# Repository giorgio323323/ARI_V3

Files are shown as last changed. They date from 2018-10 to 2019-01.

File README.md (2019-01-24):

il progetto si sposta in https://github.com/stuffcube/ARI_V3
questo repository va in abbandono.

la documentazione è in costruzione.
ogni folder sarà un repository e conterrà un proprio readme

la documentazione sarà in markdown language per poter essere editata e condivisa

# ARI_V3
versione 3 di Ari(anna)

ARI_V3 è un robot didattico.  
L'abbiamo fatto scrivendo il codice da zero per poter capire e poi speigare tutte le nozioni che servono a farlo funzionare.
Doveva poi poter essere usato senza il timore di romperlo. 
Avere un costo che permettesse a ognuno di averlo.
Doveva avere le possibilità di un robot "Grande", permettere di fare se cose che si fanno sui robot "seri".

Costando il materiale circa 100 € permette a ognuno di averlo per poterci lavorare.
Ha dei motori che gli permettono di muoversi. Sono dotati di encoder sulle ruote, ha quindi un algoritmo di odometria. L'odometria gli permette di sapere dove sta andando.
Ha un Lidar, un radar laser, montato su un servo che permette di ruotarlo. Questo permette di analizzare gli algoritmi di scansione in due dimensione.
Gli permette anche di viaggiare mantenendo la distanza da una parete laterale o di seguire una persona.
Ha una interfaccia WiFi, tramite questa si collega a un pc da dove è possibile inviare comandi ed eseguire programmi che comandano e usano i dati ritornati da ARI.

monta un puntatore laser per indicare cose, ha un sensore IR per poter tornare a casa quando si perde.

Per ultimo ha una interfaccia per bussola magnetica e navigatore inerziale completo.

Ogni suo aspetto può essere studiato 
senza timore di rompere qualcosa.

istruzioni di installazione del SW nel folder:
ARI_V3\00_doc\00_installaECompila

a cura di https://stuffcube.wordpress.com/

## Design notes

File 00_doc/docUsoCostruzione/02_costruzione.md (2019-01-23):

| Tabella aggiornamenti |  |  |
| --- | --- | --- |
| data | autore | modifica |
| |  |  |
| |  |  |
| |  |  |

# Impostazioni e taratura

Una volta montata ARI V3 occorre configurarla per fargli conoscere come è il suo corpo. Le informazioni che servono sono:

La _Carreggiata o Baseline_: distanza tra le ruote in mm

Lo _Sviluppo della ruota_ in mm, la sua circonferenza che è pari a 3.14 volte il diametro.

I _ppr_ (Pulses Per Revolution) degli encoder. Il numero di tacche che ha il disco dell&#39;encoder.

Con questi numeri si ricavano i numeri del robot.

Baseline = Carreggiata

Giro Ruota = sviluppo ruota[mm]/(4\*ppr)

ED = 1

ED\_BASE  = 1

Calcolati questi numeri tramite la CLI

[^]: CLI, Command Line Interface. È la finestra con la quale inviamo I comandi digitandoli sulla tastiera.

 vi imposto su ARI V3. Scritto il comando lo si invia con _InviaCmd_.

_I comandi hanno la seguente forma:_

_il primo numero indica l&#39;azione. 3 significa scrittura, 1 lettura.
dal terzo carattere si indica quale azione fare, nell&#39;esempio sotto F1 significa scrivi ED\_BASE
i caratteri successivi contengono l&#39;argomento del comando, di norma il valore._

_Ad ogni comando inviato viene ritornata una risposta &quot;comprensibile&quot;.
es: invio &quot;3F11&quot; mi viene ritornato &quot;F1\_ED\_BASE: 1.000000&quot;_

Il comando è il seguente:

Fnxxx: imposta dei parametri del robot. &quot;n&quot; indica quale parametro, &quot;xxx&quot; è il valore.

    F0xx ED
    F1xx ED\_BASE
    F2xx BASELINE               mm
    F3xx GIRO\_RUOTA        mm = sviluppo ruota[mm]/(4\*ppr)
    
    N.B. questi valori vanno attivati con un 3E3

Esempio:

carreggiata 		= 220 mm
diametro ruota 	= 50 mm
ppr 				= 20

sviluppo ruota = 3.14\*50 = 157 mm

Giro Ruota = sviluppo ruota[mm]/(4\*ppr) = 157/(4\*20) =1.9625 mm

Comandi da inviare:

E2                carica i valori di default.
E3                attiva i valori
E0                salva i valori in E2prom

I valori di default sono quelli sotto riportati.

dovendo modificare i valori sotto sono riportati i singoli comandi.	

ED                 		= 1        		inviare           	**F01**. **N.B. 0 è &quot;zero&quot; non &quot;O&quot; maiuscolo**
ED\_BASE  		= 1        		inviare               **F11**
BASELINE		= 220      	inviare                **F2220**
GIRO\_RUOTA       	= 1.9625 	inviare                **F31.9625**

inviare E3 per attivare i valori. La risposta conterrà la lista dei parametri attiva. Questo parametro serve anche per mostrare i parametri in uso.

E0 per salvarli nella EEprom 

[^]:  EEprom oppure E2prom. Electrically Erasable Programmable Read-Only Memory. Una memoria dove i dati possono essere letti, scritti e conservati anche senza tensione, cioè a chip spento.

 di ARI V3. Cosi facendo verranno ricaricati ad ogni accensione.

# Verifica dei dati.

Per vedere se i numeri &quot;quadrano&quot; muoviamo ARI. Facciamogli fare un movimento e vediamo come va. Mi serve un metro per misurare lo spazio percorso.

## Verifica distanza

Accendo e spengo ARI.

**3D1000**         definisco un percorso di 1000 mm.
**3R1**                 la faccio muovere in linea retta. ARI dovrebbe partire e fermarsi dopo un metro circa.

Se la distanza percorsa non è corretta aggiusto GIRO\_RUOTA opportunamente.. formula

## Verifica centratura

È probabile che il percorso non sia rettilineo e tenda a curvare verso destra o sinistra. Il fenomeno è dovuto alle ruote che pur simili hanno differenze minime. Aggiustando il parametro ED si corregge questo comportamento, ED infatti modifica il diametro delle ruote sinistra e destra rendendoli diversi.
ED si modifica a piccoli passi, qualche percento alla volta, per esempio 1.01 oppure 0.99. Se lo si aumenta ARI va verso destra, diminuendolo ruota verso sinistra.

Per attivare il valore ED = 1.02 la sequenza è:

passo 1: impostazione parametro

**3F01.02**                 per impostare il nuovo valore 1.02
**3E3**                         per attivare i valori, la risposta

Passo 2:Test

**3D1000**         definisco un percorso di 1000 mm.
**3R1**                 la faccio muovere in linea retta.

Muove verso destra?         Diminuisco ED e torno al passo 1
Muove verso sinistra?         aumento ED e torno al passo 1

Muove diritta? Proseguo e salvare i dati

**3E0**                 salvo i dai in memoria EEprom.

Ex: EEprom.  Esegue operazioni su dei parametri di taratura. Vedi procedura DataEEprom.

    E0 SCRIVI i parametri in E2prom,
    E1 LEGGI i parametri in E2prom,
    E2 rispristina in valori di DEFAULT,
    E3 attiva e mostra i parametri CORRENTI,

# Tabelle di collegamento connettori

| **J\_ENC** | **filo** | **Jb**asetta End Stop | |
| --- | --- | --- | --- |
| 1 | Nero | Emitter-Katode | Dx |
| 2 | Bianco | Collector | Dx |
| 3 | Grigio | Anode | Dx |
| 4 | Viola | Emitter-Katode | Sx |
| 5 | Blu | Collector | Sx |
| 6 | verde | Anode | Sx |

| CN_FRONT_HEAD | | |
| --- | --- | --- |
| 1 | Marrone | Rosso 5V |
| 3 | Rosso | Nero Gnd |
| 5 | Arancio | Bianco Rx1 (lidar tx) |
| 7 | Giallo  | Verde Tx1 (lidar rx)  |
| 2 | Viola | IR rx pin |
| 4 | Grigio  | Nc |
| 6 | Bianco  | Led pointer |
| 8 | Nero | 3V3 IR power supply |

# Collegamento motori

Per il significato di sotto e sopra e destro sinistro fare riferimento all'immagine di montaggio. 

**1) Notare il nottolino giallo rivolto verso l'interno**
**2) Dx e Sx sono riferiti al robot in posizione di lavoro con la punta in avanti. Nella foto c'è la vista da sotto e dx e sx sono quindi invertite.**

| MOTORS | | |
| --- | --- | --- |
| 1 | Marrone | Sotto sx |
| 2 | Rosso | Sopra sx |
| 3 | Arancio | Sopra dx |
| 4 | Giallo  | Sotto dx |

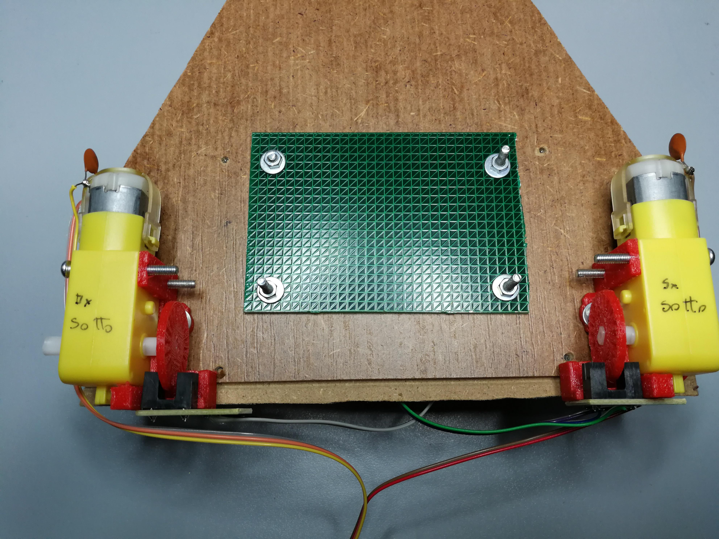
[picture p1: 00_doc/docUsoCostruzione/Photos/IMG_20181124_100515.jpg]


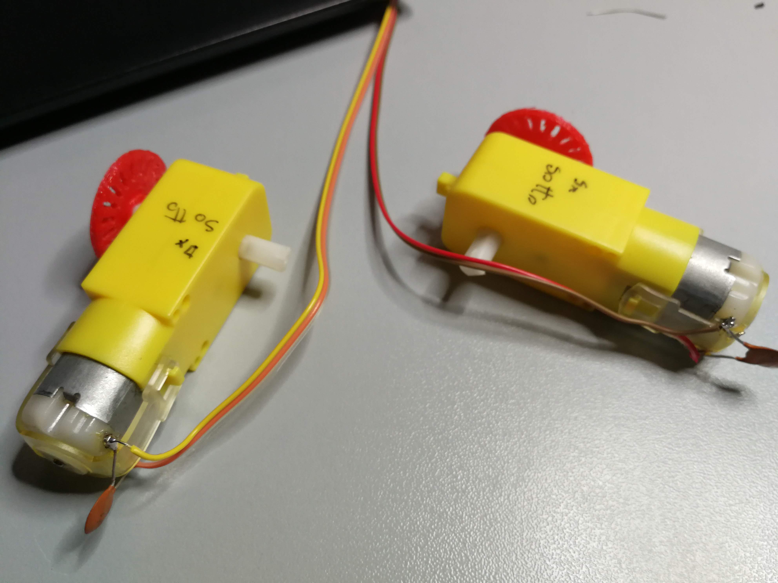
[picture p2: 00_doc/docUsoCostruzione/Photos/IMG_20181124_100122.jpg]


# Sequenza montaggio

Indicare il nottolino che deve stare all&#39;interno

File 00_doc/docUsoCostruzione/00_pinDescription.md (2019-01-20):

# Documentazione elettrica

| Tabella aggiornamenti | | |
| --- | --- | --- |
| data | autore  | modifica |
| 13gen19 | giorgio | portato documento in formato .md |
| | | |
| | | |
| | | |
| | | |
| | | |

##  

vengono descritti i pin dei vari componenti e come vengono usati.

## Wemos nomi pin

Per indirizzare i pin usare il nome della colonna GPIO. I nomi Wemos nella colonna di destra non tornano.

per verificare le corrispondenze ho scritto un codice che stampa i valori dei vari Dx, 

`Serial.println(D1);`

`...`

`Serial.println(D5);`

la colonna Valore print mostra il valore ritornato

| Print(Dx) | Valore print | GPIO | Nome wemos |
| --- | --- | ---- | --- |
| D1 | 01 | 01 | - |
| D2 | 16 | 16 | D0 |
| D3 | 05 | 05 | D1 |
| D4 | 04 | 04 | D2 |
| D5 | 14 | 14 | D5 |
| | | 15 | D8 |
| | | 13 | D7 |
| | | 12 | D6 |
| | | 02 | D4 |
| | | 00 | D3 |
| | | | |

# Dove sono usati i Wemos 

I Wemos sono usati sia sul robot che sulla base a terra. La base a terra è un radiofaro per permettere ad ARI di orientarsi.

La tabella riporta l'ssegnamento pin sui due Wemos

| **Pin number** | **Pin** **name** | **function** | **Ir Tx On ground** | **Ir Rx On robot** |
| --- | --- | --- | --- | --- |
| 1 | RST | Reset module | | |
| 2 | ADC | A/d conversion result. Input voltage range 0~1V, value range: 0~1024 | Fotocellula - in | |
| 3 | EN | Chip enable pin. Active high | | |
| 4 | GPIO16 | GPIO16; can be used to wake up the chipset from deep sleep mode | Stato barriera - D0 - out | |
| 5 | GPIO14 | GPIO14; HSPI_CLK | | |
| 6 | GPIO12 | GPIO12; HSPI_MISO | | |
| 7 | GPIO13 | GPIO13; HSPI_MOSI; UART0_CTS | | |
| 8 | VCC | 3.3V power supply (VDD) | | IR_chip pwr supply |
| 9 | GND | GND | | IR chip ground |
| 10 | GPIO15 | GPIO15; MTDO; HSPICS; UART0_RTS | | |
| **11** | **GPIO2** | **GPIO2; UART1_TXD** | **Seriale tx Debug – D4  - out** | **Seriale tx Debug – D4  - out** |
| 12 | GPIO0 | GPIO0 | Sx led sel  - D3  - out | |
| 13 | GPIO4 | GPIO4 | Ir tx - D2  -  out | Ir rx (D5) In |
| 14 | GPIO5 | GPIO5 | Dx led sel - D1 - out | |
| 15 | RXD0 | UART0_RXD; GPIO3 | | Rx |
| 16 | TXD0 | UART0_TXD; GPIO1 | | Tx |

# Wemos pin description

| **Interface** | **Pin Name** | **Description** |
| --- | --- | --- |
| HSPI | IO12(MISO), IO13(MOSI) IO14(CLK), IO15(CS) | SPI Flash , display screen, and MCU can be connected using HSPI interface |
| PWM | IO12(R), IO15(G), IO13(B) | Currently the PWM interface has four channels, but users can extend the channels according to their own needs. PWM interface can be used to control LED lights, buzzers, relays, electronic machines, and so on. |
| IR Remote Control | IO14(IR_T), IO5(IR_R) | The functionality of Infrared remote control interface can be implemented via software programming. NEC coding, modulation, and demodulation are used by this interface. The frequency of modulated carrier signal is 38KHz. |
| ADC | TOUT | ESP8266EX integrates a 10-bit analog ADC. It can be used to test the power supply voltage of VDD3P3 (Pin3 and Pin4) and the input power voltage of TOUT (Pin 6). However, these two functions cannot be used simultaneously. This interface is typically used in sensor |
| I2C | IO14(SCL), IO2(SDA) | I2C interface can be used to connect external sensor products and display screens, etc. |
| UART | UART0: TXD(U0TXD), RXD(U0RXD), IO15(RTS), IO13(CTS) UART1: IO2(TXD) | Devices with UART interfaces can be connected with the module. Downloading: U0TXD+U0RXD or GPIO2+U0RXD Communicating: UART0: U0TXD, U0RXD, MTDO (U0RTS), MTCK (U0CTS) Debugging: UART1_TXD (GPIO2) can be used to print debugging information. |
| By default, UART0 will output some printed information when the device is powered on and is booting up. If this issue exerts influence on some specific applications, users can exchange the inner pins of UART when initializing, that is to say, exchange U0TXD, U0RXD with U0RTS, U0CTS. | | |
| I2S | I2S Input： IO12 (I2SI_DATA) ; IO13 (I2SI_BCK ); IO14 (I2SI_WS); | I2S interface is mainly used for collecting, processing, and transmission of audio data. |
| I2S Output:： IO15 (I2SO_BCK ); IO3 (I2SO_DATA); IO2 (I2SO_WS ). | | |

## Arduino ATmega 2560 pin assignement table

| **Used for** | **Schematic Name** | **Pin Name** | **Mapped Pin Name** |
| --- | --- | --- | --- |
| | | | |
| | | | |
| | | PG5 ( OC0B ) | Digital pin 4 (PWM) |
| Lidar rx | PWMH.1 | PE0 ( RXD0/PCINT8 ) | Digital pin 0 (RX0) |
| - | | PE1 ( TXD0 ) | Digital pin 1 (TX0) |
| | | PE2 ( XCK0/AIN0 ) | |
| Motor A2 | PWML.6 | PE3 ( OC3A/AIN1 ) | Digital pin 5 (PWM) |
| Motor B2 | PWMH.2 | PE4 ( OC3B/INT4 ) | Digital pin 2 (PWM) |
| Motor B1 | PWMH.3 | PE5 ( OC3C/INT5 ) | Digital pin 3 (PWM) |
| | | PE6 ( T3/INT6 ) | |
| | | PE7 ( CLKO/ICP3/INT7 ) | |
| | | VCC | VCC |
| | | GND | GND |
| | | PH0 ( RXD2 ) | Digital pin 17 (RX2)  |
| | | PH1 ( TXD2 ) | Digital pin 16 (TX2)  |
| | | PH2 ( XCK2 ) | |
| Motor A1 | PWML.7 | PH3 ( OC4A ) | Digital pin 6 (PWM) |
| | | PH4 ( OC4B ) | Digital pin 7 (PWM) |
| | | PH5 ( OC4C ) | Digital pin 8 (PWM) |
| | | PH6 ( OC2B ) | Digital pin 9 (PWM) |
| | | PB0 ( SS/PCINT0 ) | Digital pin 53 (SS) |
| | | PB1 ( SCK/PCINT1 ) | Digital pin 52 (SCK)  |
| | | PB2 ( MOSI/PCINT2 ) | Digital pin 51 (MOSI) |
| | | PB3 ( MISO/PCINT3 ) | Digital pin 50 (MISO) |
| | | PB4 ( OC2A/PCINT4 ) | Digital pin 10 (PWM)  |
| | | PB5 ( OC1A/PCINT5 ) | Digital pin 11 (PWM)  |
| | | PB6 ( OC1B/PCINT6 ) | Digital pin 12 (PWM)  |
| | | PB7 ( OC0A/OC1C/PCINT7 ) | Digital pin 13 (PWM)  |
| | | PH7 ( T4 ) | |
| | | PG3 ( TOSC2 ) | |
| | | PG4 ( TOSC1 ) | |
| | | RESET | RESET |
| | | VCC | VCC |
| | | GND | GND |
| | | XTAL2 | XTAL2 |
| | | XTAL1 | XTAL1 |
| | | PL0 ( ICP4 ) | Digital pin 49 |
| | | PL1 ( ICP5 ) | Digital pin 48 |
| | | PL2 ( T5 ) | Digital pin 47 |
| | | PL3 ( OC5A ) | Digital pin 46 (PWM)  |
| | | PL4 ( OC5B ) | Digital pin 45 (PWM)  |
| | | PL5 ( OC5C ) | Digital pin 44 (PWM)  |
| | | PL6 | Digital pin 43 |
| | | PL7 | Digital pin 42 |
| | | PD0 ( SCL/INT0 ) | Digital pin 21 (SCL)  |
| | | PD1 ( SDA/INT1 ) | Digital pin 20 (SDA)  |
| | | PD2 ( RXDI/INT2 ) | Digital pin 19 (RX1)  |
| | | PD3 ( TXD1/INT3 ) | Digital pin 18 (TX1)  |
| | | PD4 ( ICP1 ) | |
| | | PD5 ( XCK1 ) | |
| | | PD6 ( T1 ) | |
| | | PD7 ( T0 ) | Digital pin 38 |
| | | PG0 ( WR ) | Digital pin 41 |
| | | PG1 ( RD ) | Digital pin 40 |
| | | PC0 ( A8 ) | Digital pin 37 |
| | | PC1 ( A9 ) | Digital pin 36 |
| | | PC2 ( A10 ) | Digital pin 35 |
| Led 3 | XIOH.4 | PC3 ( A11 ) | Digital pin 34 |
| Led 2 | XIOH.5 | PC4 ( A12 ) | Digital pin 33 |
| Led 1 | XIOH.6 | PC5 ( A13 ) | Digital pin 32 |
| | | PC6 ( A14 ) | Digital pin 31 |
| | | PC7 ( A15 ) | Digital pin 30 |
| | | VCC | VCC |
| | | GND | GND |
| | | PJ0 ( RXD3/PCINT9 ) | Digital pin 15 (RX3)  |
| | | PJ1 ( TXD3/PCINT10 ) | Digital pin 14 (TX3)  |
| | | PJ2 ( XCK3/PCINT11 ) | |
| | | PJ3 ( PCINT12 ) | |
| | | PJ4 ( PCINT13 ) | |
| | | PJ5 ( PCINT14 ) | |
| | | PJ6 ( PCINT 15 ) | |
| | | PG2 ( ALE ) | Digital pin 39 |
| | | PA7 ( AD7 ) | Digital pin 29 |
| | | PA6 ( AD6 ) | Digital pin 28 |
| | | PA5 ( AD5 ) | Digital pin 27 |
| | | PA4 ( AD4 ) | Digital pin 26 |
| | | PA3 ( AD3 ) | Digital pin 25 |
| | | PA2 ( AD2 ) | Digital pin 24 |
| | | PA1 ( AD1 ) | Digital pin 23 |
| | | PA0 ( AD0 ) | Digital pin 22 |
| | | PJ7 | |
| | | VCC | VCC |
| | | GND | GND |
| | | PK7 ( ADC15/PCINT23 ) | Analog pin 15 |
| | | PK6 ( ADC14/PCINT22 ) | Analog pin 14 |
| | | PK5 ( ADC13/PCINT21 ) | Analog pin 13 |
| | | PK4 ( ADC12/PCINT20 ) | Analog pin 12 |
| | | PK3 ( ADC11/PCINT19 ) | Analog pin 11 |
| | | PK2 ( ADC10/PCINT18 ) | Analog pin 10 |
| | | PK1 ( ADC9/PCINT17 ) | Analog pin 9 |
| | | PK0 ( ADC8/PCINT16 ) | Analog pin 8 |
| | | PF7 ( ADC7 ) | Analog pin 7 |
| | | PF6 ( ADC6 ) | Analog pin 6 |
| | | PF5 ( ADC5/TMS ) | Analog pin 5 |
| | | PF4 ( ADC4/TMK ) | Analog pin 4 |
| | | PF3 ( ADC3 ) | Analog pin 3 |
| | | PF2 ( ADC2 ) | Analog pin 2 |
| | | PF1 ( ADC1 ) | Analog pin 1 |
| | | PF0 ( ADC0 ) | Analog pin 0 |
| | | AREF | Analog Reference |
| | | GND | GND |
| | | AVCC | VCC |

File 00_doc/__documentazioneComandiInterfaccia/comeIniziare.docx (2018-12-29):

Come muovere ARI V3.

Ari non si muove da sola, si muove su commando. I comandi vengono inviati tramite una riga di commando (Command Line Interface), una GUI oppure un sw.
Per iniziare a capire usare la CLI è una buona soluzione.

Tabella aggiornamenti
data | autore | modifica
29dic18 | giorgio | Inseriti primi movimenti

# Primi movimenti

Onxx:

O0: distRef [cm]. riferimento per guida a distanza fissa nei modi R1 e R2

O1: distOstacolo [cm]. distanza minima sotto la quale ARI si arresta

Pxxx: orienta il servo PAN della testa. xxx è in gradi, 90° guarda in avanti, 0 a sinistra e 180 a destra.

in alcuni casi, a seconda del servo usato, è bene limitare l'escursione ad esempio tra 10 e 170°.

Rx: Run. Definisce in che modo effettuare la corsa "Run". Il run è definito con un obbiettivo (target).

Il raggiungimento del target termina il run.

x=4: R4. Il robot si muove sino a percorrere la distanza impostata con "D" nella direzione alfa impostata con "A".

x=5: R5. Il robot si muove sino a orientarsi nella direzione alfa impostata con "A". La rotazione fa perno su una ruota che rimane ferma.

x=6: R6. Il robot si muove sino a orientarsi nella direzione alfa impostata con "A". La rotazione avviene con perno al centro del robot con ruote controrotanti.

x=2: R2. Il robot effettua un percorso circolare con raggio pari al parametro "C". Il raggiorSterzo può anche essere

imposto direttamente con il comando "S". In questo caso sarà lo scorrimento tra le ruote dx e sx.

R1 e 3. i modi 1 e 3 fanno viaggiare il robot a una distanza fissa dalla parete laterale. la misura è fatta orinetando il LIDAR.

suggerimento, angolo lidar 45 rispetto alla parete

leggere distanza e metterla come distRef (O0)

mettere distOstacolo maggiore distRef (O1), per esempio + 30 cm

gli angoli pan (P) sono P45 seguo parete dx con R3

gli angoli pan (P) sono P135 seguo parete sx con R1

x=99: provoca l'arresto del movimento

R2 lo scorrimento tra i due motori depende dal parametro "S". con zero i due motori hanno la stessa velocità

## Elenco comandi

Axxx: Alfa. assegna Alfa, la direzione del robot. xxx è l'angolo in radianti, es 3.14. La direzione zero è definita all'accensione del robot. E' la direzione in avanti. Coincide con l'asse x.

Alfa è positivo in senso antiorario.

Bx: enableFrontSensor. 1 Enable, 0 disable

Cxxx: assegna "raggiorSterzo" in [m]. La variabile è usata nella movimento R2, stabilisce il raggio della circonferenza su cui ruota il robot.

Dxxx: Distance. La distanza che viene percorsa nel prossimo Run espressa in [mm]. La distanza è sempre incrementale.

Ex: EEprom. Esegue operazioni su dei parametri di taratura. Vedi procedura DataEEprom.

E0 SCRIVI i parametri in E2prom,

E1 LEGGI i parametri in E2prom,

E2 rispristina in valori di DEFAULT,

E3 mostra i parametri CORRENTI,

E4 carica i valori di DEFAULT per il modello ARI02,

E5 carica i valori di DEFAULT per il modello ARI03,

Fnxxx: imposta dei parametri del robot. "n" indica quale parametro, "xxx" è il valore.

F0xx ED

F1xx ED_BASE

F2xx BASELINE mm

F3xx GIRO_RUOTA mm = sviluppo ruota[mm]/(4*ppr)

N.B. questi valori vanno attivati con un 3E3

Gxxx: "Guide Mode". definisce il modo di guida nel run "R4". Il teta di feedback, tetaMisura, può provenire dall'odometria, dalla bussola, o altri mix possibili.

Nel codice sotto teta è l'angolo ricavato dagli encoder.

Il modo zero si affida alle misure fatte dagli encoder.

Il modo 1 e 3 ricavano il teta direttamente dalla bussola. Nel modo 3 anche le posizioni x e y

sono calcolate dal teta della bussola.

con il modo 2 è possibile imporre l'angolo corrente come angolo zero. Altrimenti la direzione è

assoluta come determinata dalla bussola.

if (modoGuida == 0) tetaMisura = teta; // ID_001

if (modoGuida == 1) tetaMisura = tetaCompass; // ID_009

if (modoGuida == 3) tetaMisura = tetaCompass; // ID_009

if (modoGuida == 2) {

tetaCompass = 0; // definisco la direzione corrente come zero.

modoGuida = 1;

}

in updatePosition integro posizioni in funzione del modoGuida attivo

if (modoGuida == 3) {

xpos += deltaC*cos(tetaCompass);

ypos += deltaC*sin(tetaCompass);

}

else{

xpos += deltaC*cos(teta);

ypos += deltaC*sin(teta);

}

Knxx: assegna i guadagni

K0 kpTeta il guadagno proporzionale kp usato nel modo Run 4

K1 kiTeta

K2 kp_guida il guadagno proporzionale kp usato nel modo Run 1 e 3 (sensore di distanza laterale)

K3 kd_guida il guadagno derivativo kd usato nel modo Run 1 e 3 (sensore di distanza laterale)

H0: Homing, assegna lo posizione corrente (x, y, teta) = (0, 0, 0)

Ixxx; Integral part. assegna il guadagno della parte integrale kiTeta usato nel modo Run 4.

Lx: Led. puntatore a Led acceso, x=1, o spento x=0.

Mx: Monitor. Attiva, 1, o disattiva, 0, l'invio continuo di misure da parte del robot.

le msiure sono inviate nella routine "updatePosition" ogni 100 ms.

La stringa ha l'header "mon:"

if (monitorDati && (counter >=4) ){

counter = 0;

risposta = "mon;";

risposta += (dDxCnt);

risposta += (";");

risposta += (dSxCnt);

risposta += (";");

risposta += (deltaC);

risposta += (";");

risposta += (teta);

risposta += (";");

risposta += (xpos);

risposta += (";");

risposta += (ypos);

risposta += (";");

risposta += (i_part);// raggiorSterzo

risposta += (";");

risposta += event.magnetic.x;

risposta += ";";

risposta += event.magnetic.y;

risposta += ";";

risposta += event.magnetic.z;

risposta += ";";

sendAnswer2(port);

}

Nnxxx: assegna i coefficienti di correzione della bussola.

N0: ox

N1: oy

N2: ky

Onxx:

O0: distRef [cm]. riferimento per guida a distanza fissa nei modi R1 e R2

O0: distOstacolo [cm]. distanza minima sotto la quale ARI si arresta

Pxxx: orienta il servo PAN della testa. xxx è in gradi, 90° guarda in avanti, 0 a sinistra e 180 a destra.

in alcuni casi, a seconda del servo usato, è bene limitare l'escursione ad esempio tra 10 e 170°.

Rx: Run. Definisce in che modo effettuare la corsa "Run". Il run è definito con un obbiettivo (target).

Il raggiungimento del target termina il run.

x=4: R4. Il robot si muove sino a percorrere la distanza impostata con "D" nella direzione alfa impostata con "A".

x=5: R5. Il robot si muove sino a orientarsi nella direzione alfa impostata con "A". La rotazione fa perno su una ruota che rimane ferma.

x=6: R6. Il robot si muove sino a orientarsi nella direzione alfa impostata con "A". La rotazione avviene con perno al centro del robot con ruote controrotanti.

x=2: R2. Il robot effettua un percorso circolare con raggio pari al parametro "C". Il raggiorSterzo può anche essere

imposto direttamente con il comando "S". In questo caso sarà lo scorrimento tra le ruote dx e sx.

R1 e 3. i modi 1 e 3 fanno viaggiare il robot a una distanza fissa dalla parete laterale. la misura è fatta orinetando il LIDAR.

x=99: provoca l'arresto del movimento

Il movimento si arresta quando il lidar vede un ostacolo troppo vicino.

if (lidardist<50 && (statoRun != 5) &&(statoRun != 6) &&(statoRun != 0))

{

statoRun = 99; // senza rampa

motorSpeed = 0; // annullo rampa

motorSpeedRef = 0;

risposta = "ostacolo";

sendAnswer2(port);

}

Sxxx: Scorrimento. Imposta direttamente la varibile "raggiDiSterzo". è un numero tra -1 e 1.

Zero significa scorrimento nullo, cioè le due ruote hanno la stessa velocità comandata.

vedi procedura "differenziale"

ponendo s = raggiorSterzo abbiamo che le velocita' alle ruote valgono:

VA = motorSpeed*(1-s)

VB = motorSpeed*(1+s)

Txxx: orienta il servo TILT della testa. xxx è in gradi, 90° guarda in avanti, 0 a sinistra e 180 a destra.

in alcuni casi, a seconda del servo usato, è bene limitare l'escursione ad esempio tra 10 e 170°.

Vxxx: Velocità. Definisce la velocità del robot. é il valore assegnato al PWM.

Zxxx: definisce MAX_S. è il limite dello scorrimento (positivo e negativo) applicabile dal controllo.

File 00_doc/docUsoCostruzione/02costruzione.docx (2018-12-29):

Tabella aggiornamenti
data | autore | modifica

# Impostazioni e taratura

Una volta montata ARI V3 occorre configurarla per fargli conoscere come è il suo corpo. Le informazioni che servono sono:

La Carreggiata o Baseline: distanza tra le ruote in mm

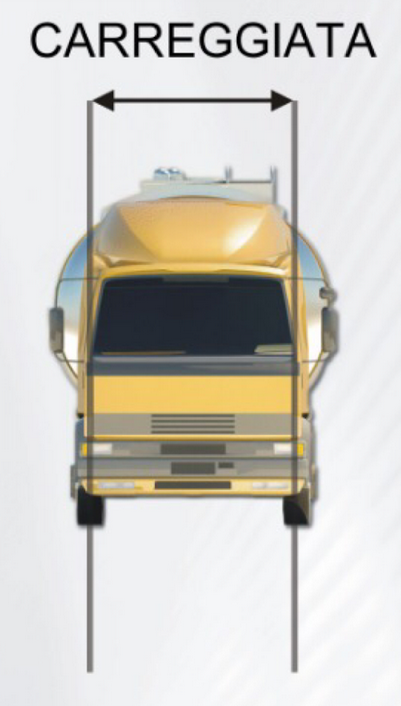
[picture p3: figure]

Lo Sviluppo della ruota in mm, la sua circonferenza che è pari a 3.14 volte il diametro.

I ppr (Pulses Per Revolution) degli encoder. Il numero di tacche che ha il disco dell’encoder.

Con questi numeri si ricavano i numeri del robot.

Baseline = Carreggiata

Giro Ruota = sviluppo ruota[mm]/(4*ppr)

ED = 1

ED_BASE = 1

Calcolati questi numeri tramite la CLI[^1] vi imposto su ARI V3. Scritto il comando lo si invia con InviaCmd.

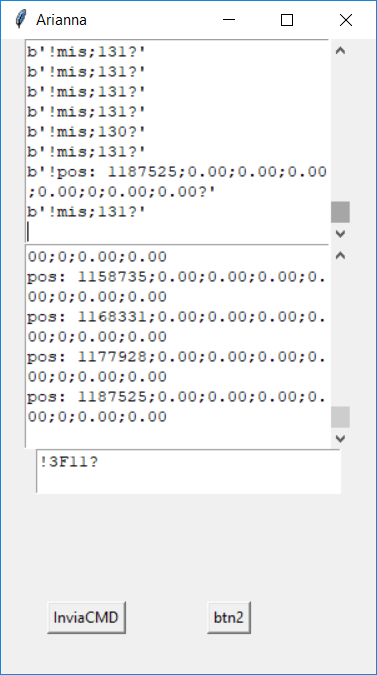
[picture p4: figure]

I comandi hanno la seguente forma:

il primo numero indica l’azione. 3 significa scrittura, 1 lettura.
dal terzo carattere si indica quale azione fare, nell’esempio sotto F1 significa scrivi ED_BASE
i caratteri successivi contengono l’argomento del comando, di norma il valore.

Ad ogni comando inviato viene ritornata una risposta “comprensibile”.
es: invio “3F11” mi viene ritornato “F1_ED_BASE: 1.000000”

Il comando è il seguente:

Fnxxx: imposta dei parametri del robot. "n" indica quale parametro, "xxx" è il valore.

F0xx ED

F1xx ED_BASE

F2xx BASELINE mm

F3xx GIRO_RUOTA mm = sviluppo ruota[mm]/(4*ppr)

N.B. questi valori vanno attivati con un 3E3

Esempio:

carreggiata = 220 mm
diametro ruota = 50 mm
ppr = 20

sviluppo ruota = 3.14*50 = 157 mm

Giro Ruota = sviluppo ruota[mm]/(4*ppr) = 157/(4*20) = 1.9625 mm

Comandi da inviare:

E2 carica i valori di default.
E3 attiva i valori
E0 salva i valori in E2prom

I valori di default sono quelli sotto riportati.

dovendo modificare i valori sotto sono riportati i singoli comandi.

ED = 1 inviare F01. N.B. 0 è “zero” non “O” maiuscolo
ED_BASE = 1 inviare F11
BASELINE = 220 inviare F2220
GIRO_RUOTA =1.9625 inviare F31.9625

inviare E3 per attivare i valori. La risposta conterrà la lista dei parametri attiva. Questo parametro serve anche per mostrare i parametri in uso.

E0 per salvarli nella EEprom[^2] di ARI V3. Cosi facendo verranno ricaricati ad ogni accensione.

# Verifica dei dati.

Per vedere se i numeri “quadrano” muoviamo ARI. Facciamogli fare un movimento e vediamo come va. Mi serve un metro per misurare lo spazio percorso.

## Verifica distanza

Accendo e spengo ARI.

3D1000 definisco un percorso di 1000 mm.
3R1 la faccio muovere in linea retta. ARI dovrebbe partire e fermarsi dopo un metro circa.

Se la distanza percorsa non è corretta aggiusto GIRO_RUOTA opportunamente.. formula

## Verifica centratura

È probabile che il percorso non sia rettilineo e tenda a curvare verso destra o sinistra. Il fenomeno è dovuto alle ruote che pur simili hanno differenze minime. Aggiustando il parametro ED si corregge questo comportamento, ED infatti modifica il diametro delle ruote sinistra e destra rendendoli diversi.
ED si modifica a piccoli passi, qualche percento alla volta, per esempio 1.01 oppure 0.99. Se lo si aumenta ARI va verso destra, diminuendolo ruota verso sinistra.

Per attivare il valore ED = 1.02 la sequenza è:

passo 1: impostazione parametro

3F01.02 per impostare il nuovo valore 1.02
3E3 per attivare i valori, la risposta

Passo 2:Test

3D1000 definisco un percorso di 1000 mm.
3R1 la faccio muovere in linea retta.

Muove verso destra? Diminuisco ED e torno al passo 1
Muove verso sinistra? aumento ED e torno al passo 1

Muove diritta? Proseguo e salvare i dati

3E0 salvo i dai in memoria EEprom.

Ex: EEprom. Esegue operazioni su dei parametri di taratura. Vedi procedura DataEEprom.

E0 SCRIVI i parametri in E2prom,

E1 LEGGI i parametri in E2prom,

E2 rispristina in valori di DEFAULT,

E3 attiva e mostra i parametri CORRENTI,

# Tabelle di collegamento

J_ENC | filo | JbasettaMotore
1 | Nero | Emitter-Katode | Dx | Gnd
2 | Bianco | Collector | Dx | Encoder
3 | Grigio | Anode | Dx | Alimentazione diodo
4 | Viola | Emitter-Katode | Sx | Gnd
5 | Blu | Collector | Sx | Encoder
6 | verde | Anode | Sx | Alimentazione diodo

CN_FRONT_HEAD
1 | Marrone | Rosso 5V
3 | Rosso | Nero Gnd
5 | Arancio | Bianco Rx1 (lidar tx)
7 | Giallo | Verde Tx1 (lidar rx)
2 | Viola | IR rx pin
4 | Grigio | Nc
6 | Bianco | Led pointer
8 | Nero | 3V3 IR power supply

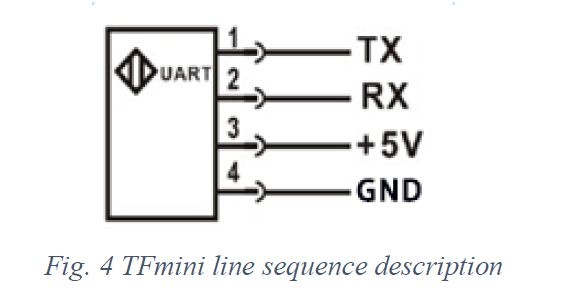
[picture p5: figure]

Collegamento motori

MOTORS
1 | Marrone | Sotto sx
2 | Rosso | Sopra sx
3 | Arancio | Sopra dx
4 | Giallo | Sotto dx

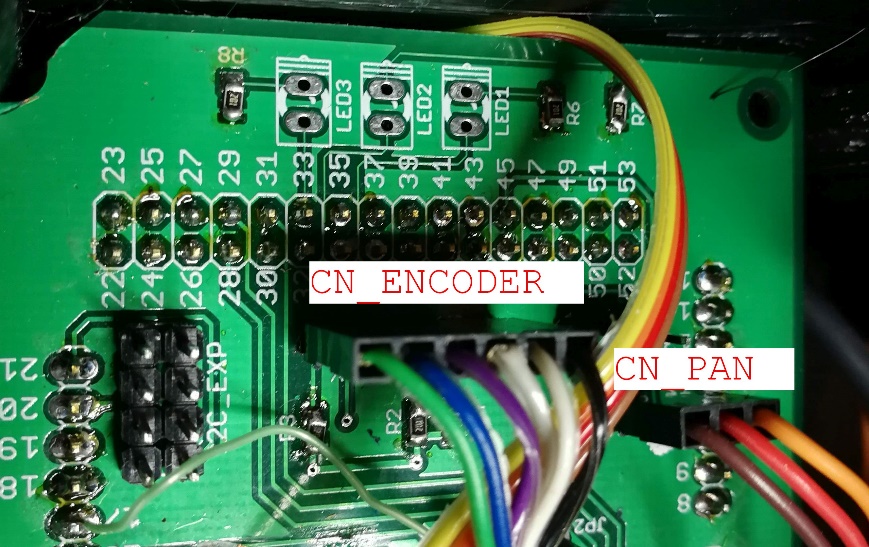
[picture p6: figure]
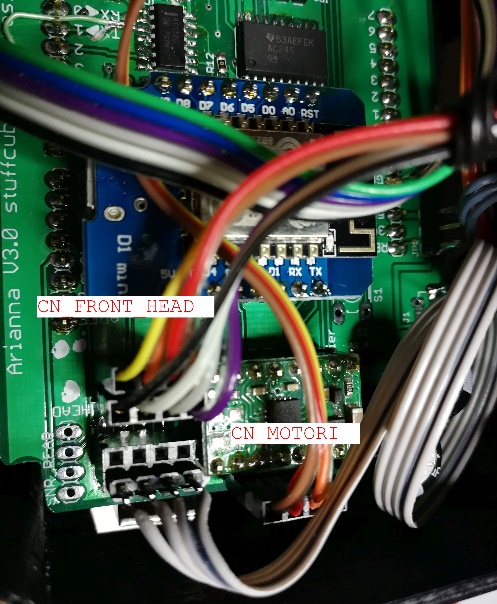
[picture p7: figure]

# Sequenza montaggio

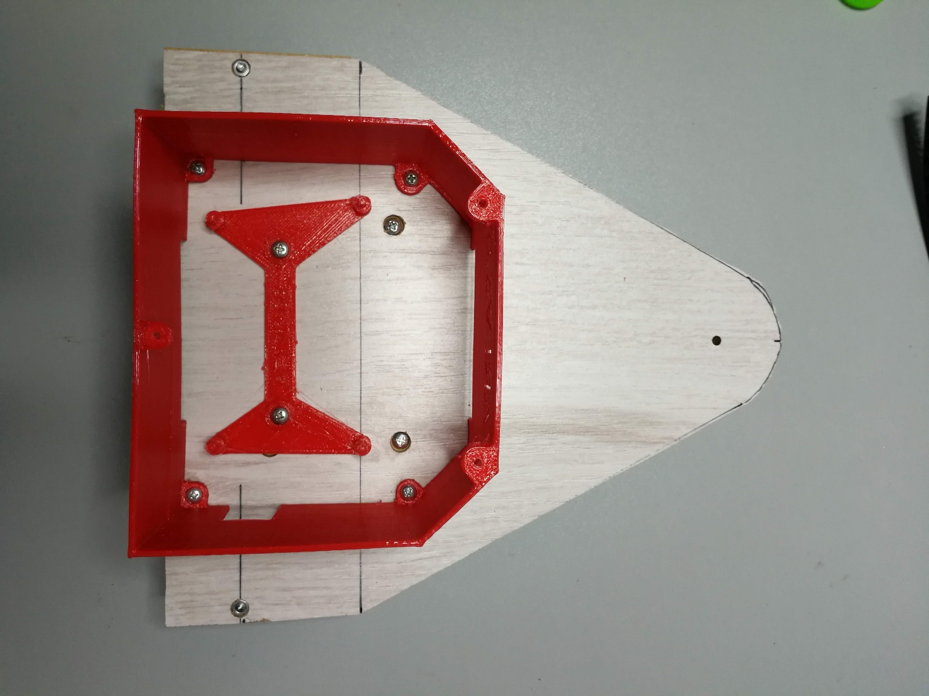
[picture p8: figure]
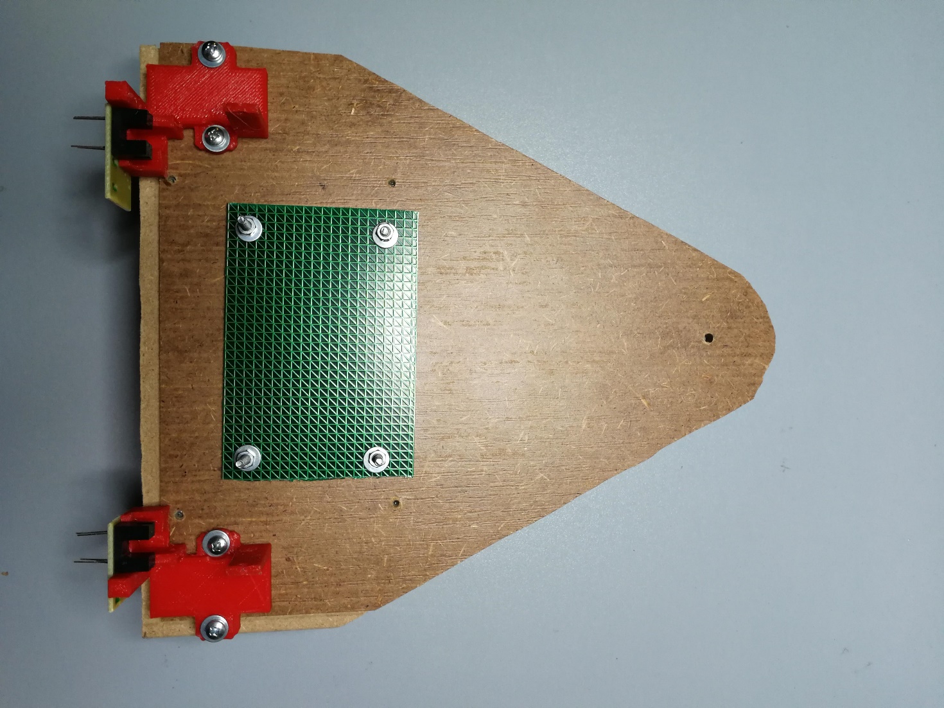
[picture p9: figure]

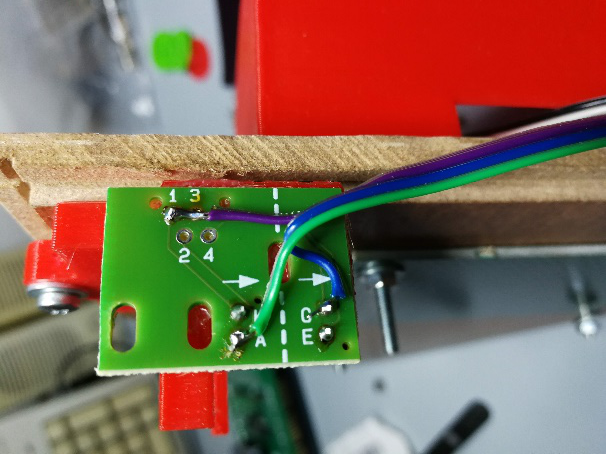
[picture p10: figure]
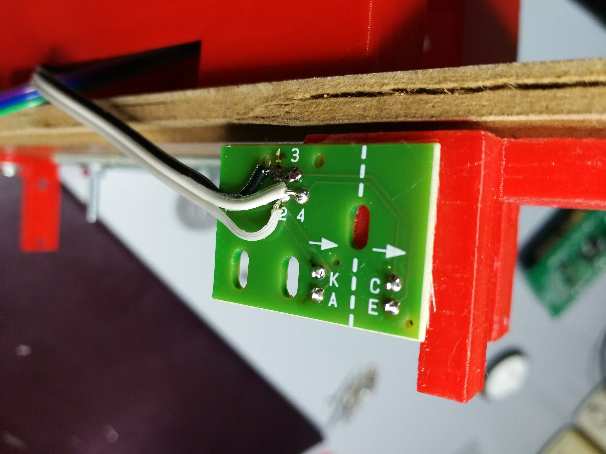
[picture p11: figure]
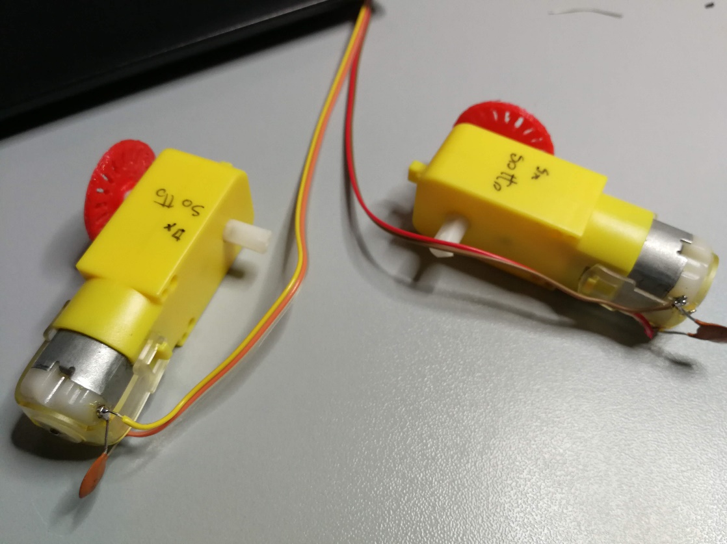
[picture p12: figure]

Indicare il nottolino che deve stare all’interno

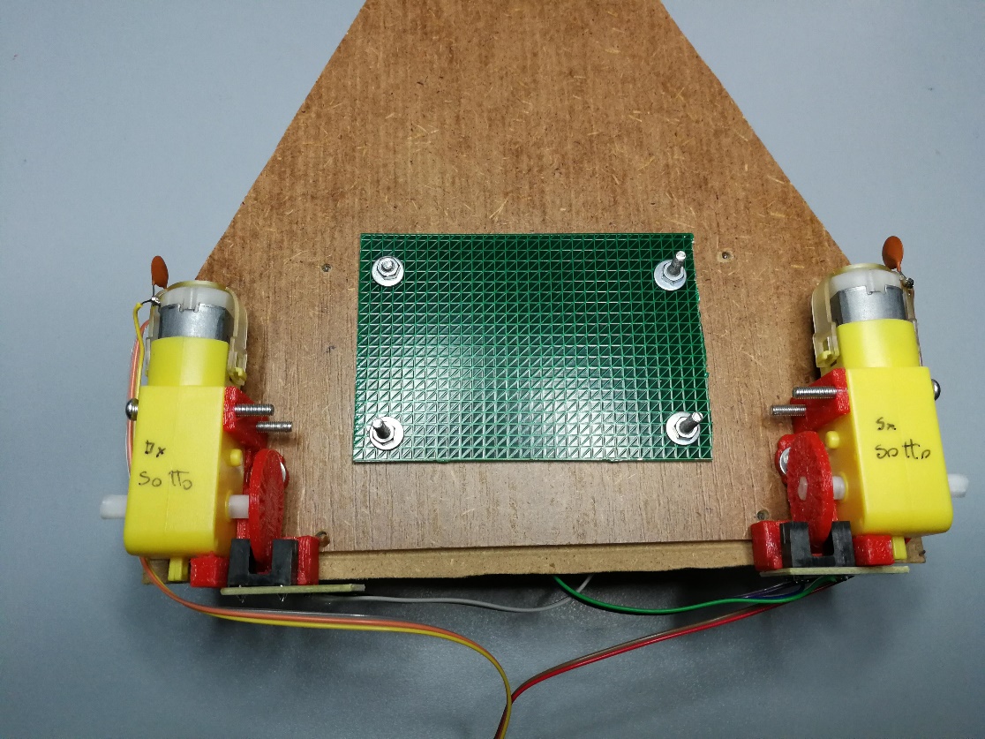
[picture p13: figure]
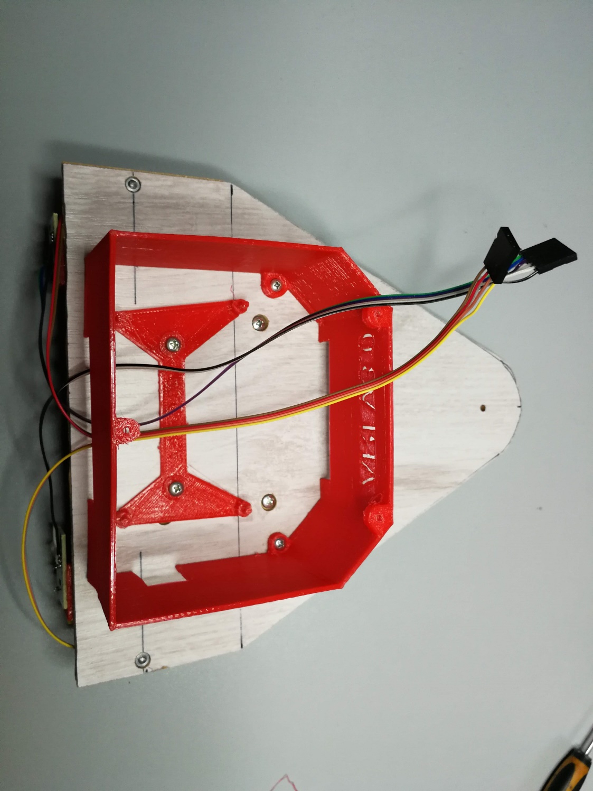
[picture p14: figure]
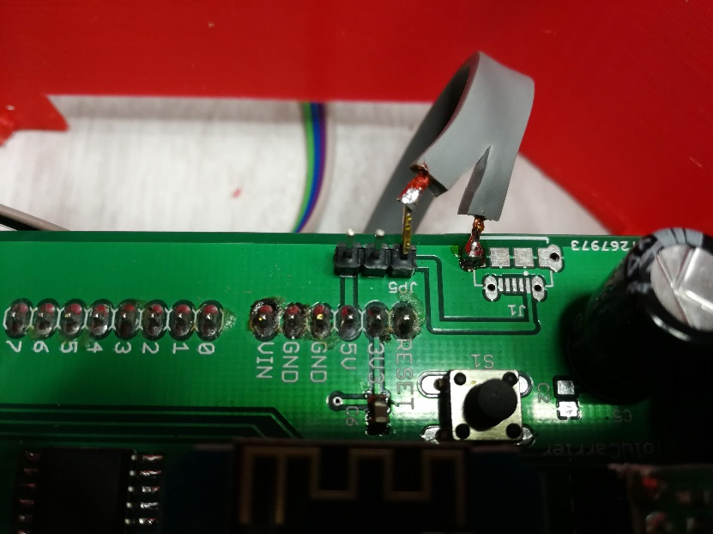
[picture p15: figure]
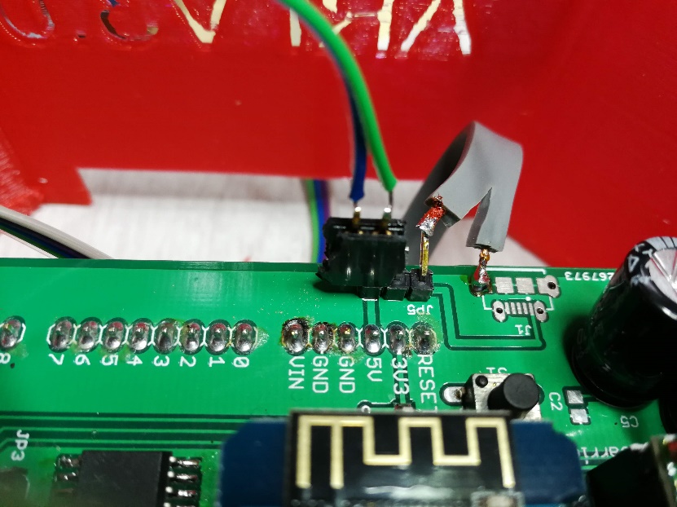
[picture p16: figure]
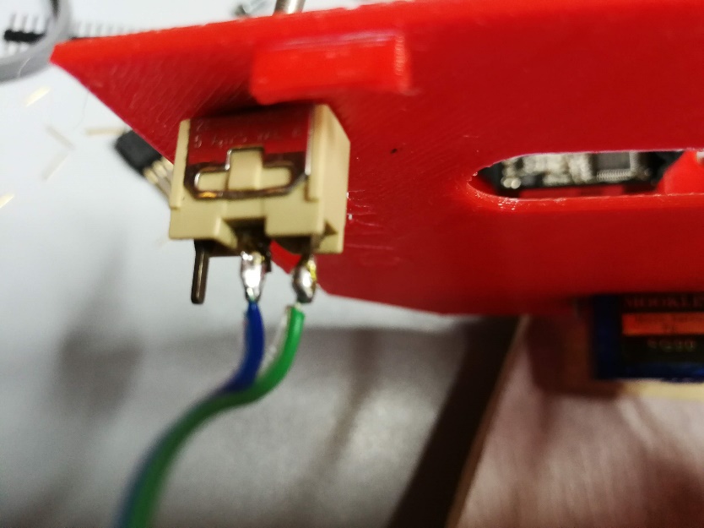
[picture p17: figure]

[^1] CLI, Command Line Interface. È la finestra con la quale inviamo I comandi digitandoli sulla tastiera.
[^2] EEprom oppure E2prom. Electrically Erasable Programmable Read-Only Memory. Una memoria dove i dati possono essere letti, scritti e conservati anche senza tensione, cioè a chip spento.

02costruzione.docx 1/10

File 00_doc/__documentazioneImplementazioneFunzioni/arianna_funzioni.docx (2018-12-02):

Sommario

# 1 come nasce Arianna

Arrivo in biblioteca e chiedo “Robinia Blues” di Valter Binaghi, il bibliotecario consulta il computer e mi informa che c’è e lo posso trovare tra gli autori italiani. Un attimo di imbarazzo, non frequento questo luogo abbastanza da conoscere la disposizione degli scaffali, faccio per domandare ma il mio interlocutore mi anticipa dicendomi di seguire Arianna. Arianna ? Un sibilo mi fa voltare, vedo una macchinina che parte lungo il corridoio, porta la scritta Arianna. Al mio sguardo interrogativo il mio interlocutore mi fa cenno di andare, segua Arianna mi dice. Tutto dura pochi secondi nei quali valuto anche la possibilità di essere vittima di “Scherzi a parte”, Arianna si ferma, si gira un poco e con un altro fruscio un puntatore luminoso si muove, si accende e quando decido di guardare dove Arianna sembra “indicare” vedo una luce sui libri e li vicino il mio “Robina Blues”. Lo prendo, lo sfoglio e me ne vado un poco stupito, saluto il bibliotecario e nel frattempo risento il sibilo. Vedo Arianna che torna da dove era venuta, la vedo accoccolarsi in una piccola casetta e io lascio la biblioteca pronto a rileggere il libro di un bravo insegnante che ha attraversato i nostri luoghi.

Arianna è un robot che è in grado di muoversi sul pavimento e andare dove gli viene richiesto. E’ il progetto che abbiamo avviato all’interno di StuffCube. La prima parte è stato definire cosa deve fare, lo abbiamo descritto nell’incipit. Successivamente abbiamo scomposto il progetto nelle diverse funzioni di considerando le caratteristiche della biblioteca che ci ospita:

- Realizzare oggetto che si muove (rover cioè vagabondo)
- sensori sul rover
- ricevimento comandi di destinazione
- determinare dove deve andare
- determinare dove è
- determinare il moto verso la destinazione
- indicare il libro
- ritorno a casa
- ricarica
- la nostra bilbioteca ha degli scaffali su ruote, questo aggounge un nuovo compito, mappare gli scaffali quando vengono spostati.

Altri vincoli di progetto che ci siamo dati sono di essere il meno intrusivi possibile, questo fa si che dobbiamo evitare soluzioni che richiedano sorgenti di alimentazione, oppure il porre strisce guida sul pavimento e cosi via.

Inizieremo partendo dagli scaffali più semplici, quelli che affiancano la parete. L’idea è seguire lo scaffale viaggiandoci radente e identificando dove siamo misurando lo spostamento e usando dei segni già presenti sulla struttura. Guardare cosa hanno fatto altri è utile e istruttivo. Siamao partiti da: Un robot che segue le pareti (http://www.allaboutcircuits.com/projects/how-to-build-a-robot-follow-walls/)

# 2 il punto di vista del robot

Arianna, l’aiuto bibliotecario dove lavora? La biblioteca dove lavora Arianna è un ampio spazio aperto su un solo piano e ha un bel pavimento in parquet laminato. I libri sono ospitati da un lungo scaffale disposto lungo e da alcuni scaffali montati su rotelle. Ci sono sia tavoli che ospitano dei pc fissi che tavoli per lo studio. Alcune poltroncine e un pianoforte completano l’arredo. I vari elementi sono facilmente spostabili per adattare lo spazio a varie esigenze, studio, conferenze, laboratori. Questo almeno è quello che vediamo noi, lo vediamo coi nostri occhi e la consuetudine che abbiamo con l’ambiente. Arianna è diversa, la sua percezione del mondo è dovuta ai suoi sensori e le sue scelte sono frutto di quello che scriveremo nel software.

Il punto di vista è importante, già abbassandoci al livello di Arianna vediamo le cose in maniera diversa. Iniziamo dal movimento. Il prototipo zero ha due ruote motrici posteriori ognuna pilotata da un proprio motore, davanti una sfera funge da terzo appoggio. Controllando opportunamente i due motori siamo in grado di regolare sia la velocità che la direzione. Arianna zero usa due motori stepper derivati da dei lettori CD. Gli stepper sono motori nei quali possiamo imporre rotazioni in maniera controllata. Questo ci permette di conoscere anche l’entità dello spostamento, questa informazione ci permetterà di sapere dove siamo sul pavimento.

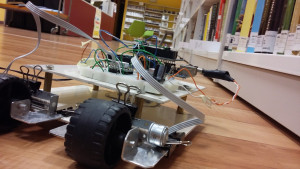
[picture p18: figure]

il punto di vsita di Arianna

Le ruote vengono da una scatola del Meccano. I supporti sono lamiera di allumino taglia e piegata. Mollette, viti e distanziali permettono di montare il tutto su delle piastre in PVC.

Abbiamo pronta la parte meccanica. Il prossimo passo è verificare il movimento, come curva e stimare la capacità di percorrere ripetutamente uno stesso percorso senza l’ausilio di sensori.

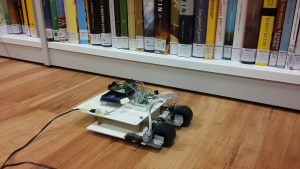
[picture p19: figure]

Arianna di fronte agli scaffali

# 3 vari prototipi. Arianna e i suoi fratelli

Tre sono i prototipi in corso di costruzione, servono a provare in campo diverse soluzioni di motorizzazione e guida.

Arianna 00 ha come base una macchinina giocattolo, ha un motore DC posteriore per il movimento e il classico sterzo anteriore a due ruote come le automobili. Lo sterzo è stato modificato sostituendo l’esistente che ammetteva solo tre possibili direzioni dritto, tutto sinistra, tutta destra con un servomotore che regola a piacere la direzione.
Arianna 01, detta anche Ambros, è invece un tre ruote. Due motrici comandate da due separati motori DC e una terza piroettante anteriore. In questo caso la direzione viene cambiata regolando le velocità dei due motori. Con questa soluzione è possibile ottenere qualunque angolo di sterzata, anche ruotando su se stessa.
Ultima è 02, questa ha la stessa struttura di 01 eccetto che usa motori stepper.

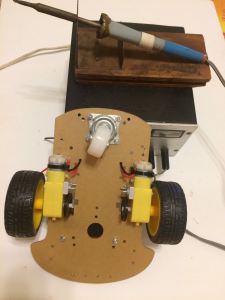
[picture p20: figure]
ari-01-20161202-wa0004

Arianna 01 detta “Ambros”

Con gli stepper siamo in grado di imporre una rotazione nota delle ruote, possiamo quindi imporre la traslazione e rotazione del robot senza usare sensori sui motori. Con il motore dc per conoscere lo spostamento delle ruote abbiamo bisogno di un sensore di rotazione posto sull’albero del motore.

## chi guida?

Fatta la macchina occorre il guidatore che a sua volta necessità di occhi bene aperti. Il nostro comune guidare l’auto è a ben vedere composto da diverse guide sovrapposte:
una prima è quella che ci fa seguire la strada evitando muri, marciapiedi e altri ostacoli, un controllo sugli elementi locali, la chiameremo guida locale.
Un livello superiore è quello che ci fa capire dove siamo e quale percorso fare per giungere a destinazione, diamogli il nome di navigazione e posizionamento.

## La guida locale, valutazione e misura

I questo momento stiamo lavorando sulla guida locale. Il primo test di guida in corso è quello di percorre l’intero scaffale diritto con una velocità ragionevolmente elevata e un andamento elegante e sicuro, il test è detto “della libreria”.
Questi due parametri sono il criterio di misura e valutazione del risultato. La velocità deve essere paragonabile a una persona che cammina in un locale, l’abbiamo stimata ragionevole tra i 0.25-0.5 m/s pari a circa 1-2 km/h. L’incedere deve essere lineare senza bruschi cambi di direzione e neppure oscillate a mo’ di ubriaco. Un moto di questo tipo è prevedibile e ben accetto, è conforme alle attese di chi ci segue.

Nei video vediamo una demo di Arianna 00 con risultati promettenti.

https://youtu.be/69APaa1ccjU

https://youtu.be/A6ZCeFUlZlU

## Sensori

Per correre lungo la libreria dobbiamo sapere dove questa si trova, tramite dei sensori posti sul lato del veicolo otteniamo l’informazione. In questo modello abbiamo usato sensori a infrarossi della Pololu 2579 – Pololu 38 kHz IR Proximity Sensor.

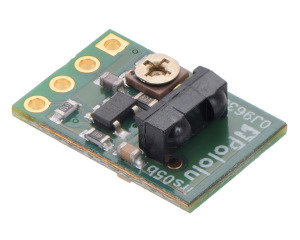
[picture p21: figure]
ir38khz

Questi sono previsti per indicare la presenza o assenza di un ostacolo in un range tra i 30-40 cm. Hanno una banda di incertezza di 10-20 cm dove la loro uscita è instabile.
Abbiamo voluto sperimentare se fosse possibile sfruttare questa banda di incertezza per avere una informazione continua sulla distanza, lo facciamo misurando il tempo in cui il segnale rimane a uno sul tempo di lettura totale.
Usando sia il rapporto Ton/Tmisura che il numero di transizioni abbiamo ottenuto una misura utile nel passaggio tra presenza e assenza.
La funzione ha dato buoni risultati. Il grafico mostra una misura fatta con un oggetto che si avvicina al sensore. La linea rossa con asse a sinistra mostra la variazione tra ostacolo assente, valore uno, a ostacolo presente, valore zero. Nella regione di transizione viene restituita una informazione significativa. In blu riferito all’asse destro c’è il contatore dello stato del sensore.

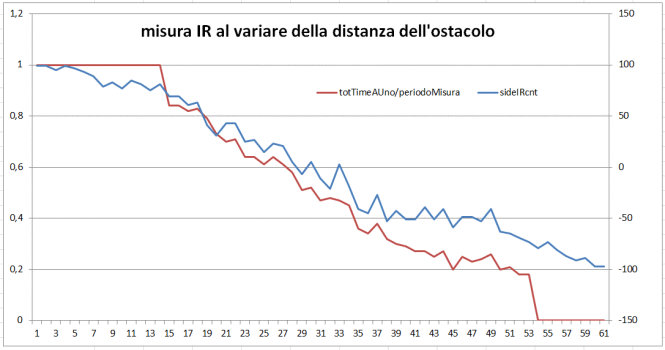
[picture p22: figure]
misurair_excel

misurazione ricavata nel campo di incertezza del sensore

Il contatore valore viene incrementato a tempo secondo il suo stato e serve a capire se siamo vicini alla zona di lettura stabile. I queste zone non possiamo estrarre ulteriori informazioni.

1 2 | if (digitalRead(SIDE_IR)) sideIRcnt++; else sideIRcnt--;

disponiamo quindi di un’informazione continua che ci dice che siamo tra i 30-50 cm dalla libreria, e che siamo oltre i 50 o al disotto dei 30 cm. Questa è la nostra visione del mondo. sottraendo uno 0.5 abbiamo normalizzato questo numero tra +/- 0.5.

## Il guidatore ovvero il sistema di controllo

Noi vogliamo che Arianna viaggi a una distanza dalla libreria che vale 0.5. Per fare questo utlizziamo un regolatore proporzionale. La distanza misurata viene sottrata a 0.5, il valore ottenuto è l’errore, usiamo questo numero per pilotare l’angolo dello sterzo.
Con errore 0 andiamo diritti.
Quando ci allontaniamo curviamo verso destra per avvicinarci, quando ci avviciniamo andiamo a sinistra.
Questi continui aggiustamenti ci mantengono sulla retta via. Così come quando impariamo a guidare dobbiamo imparare a dosare la curva per non avere una traiettoria ondeggiante da ubriaco. Più veloci andiamo più dobbiamo essere dolci. Il guadagno proporzionale del nostro anello è quello che ci serve tarare.

Attualmente il sistema in assenza di ostacolo si muove verso destra cercando la libreria.

## Prossimi passi

Le varie attività proseguono in parallelo a seconda delle difficoltà e disponibilità di tempo delle persone. Non c’è quindi un cronoprogamma rigoroso, c’è invece un lavoro flessibile e guidato dalle opportunità. Possiamo però indicare le previsioni a breve.

Appena pronti anche gli altri prototipo saranno sottoposti al test della libreria. Abbiamo visto che il sensore frontale deve avere un raggio di azione di almeno un paio di metri e lo sostituiremo con uno a ultrasuoni. Possiamo iniziare a definire una strategia di utilizzo dei sensori per navigare in assenza di informazioni, in altre parole se i miei sensori non vedano nulla dove vado? Il tema si chiama posizionamento all’interno di locali (indoor positioning).

# 4 struttura scelta

L’articolo precedente su Arianna, il robot bibliotecario, risale a dicembre. Anche se apparentemente i cambiamenti sono pochi per il nostro robot letterato la frase “tutto cambia affinché nulla cambi” non vale. Un grosso lavoro è stato fatto, molte le cose imparate e che condivideremo con voi. La cadenza degli articoli sarà settimanale e manterremo la continuità.
StuffCube è un luogo di incontro reale e non virtuale, siamo il mercoledì e giovedì sera alla biblioteca di Canegrate e l’ingresso è libero.
Arianna serve per imparare come si fa un robot, non per usarne uno già fatto!

A dicembre Arianna era fatto con una meccanica basata su sterzo di Ackerman (http://www.modellismo.net/articoli/assetto.html), il classico sistema di curvatura delle automobili, e aveva la trazione posteriore, era capace di seguire lo scaffale della biblioteca grazie ad un sensore ad infrarossi, misurava la distanza percorsa tramite un sensore sull’asse posteriore, partiva comandato da un bottone. Aveva anche dei fratelli e delle sorelle che avevano scelto motorizzazioni diverse.

## Arianna oggi

La struttura: Viste le caratteristiche dei fratelli, Arianna oggi è basata su un kit con due ruote motorizzate e una ruota castor anteriore. Il testo “Autonomous Mobile Robot Mechanical Design” (http://mech.vub.ac.be/multibody/final_works/ThesisKristofGoris.pdf)
contiene una chiara presentazione dei vari tipi di scelte fattibili sul movimento di macchine, partendo da un semplice robottino sino a una ruspa passando attraverso l’Ape car. Leggendolo abbiamo scoperto le ruote ominidirezionali, mostrate nel video seguente

https://youtu.be/IlmKcohyXG0

Tornando a noi la meccanica è basata su un kit (https://www.amazon.it/gp/product/B01F3OHY1U/ref=oh_aui_detailpage_o00_s00?ie=UTF8&amp;psc=1)reperibile su Amazon, kit che era stato usato da “Ambros”. È un sistema a tre ruote con due ruote fisse, motorizzate e indipendenti, la terza è una ruota piroettante castor.

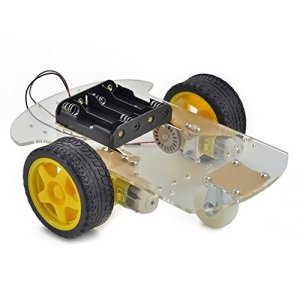
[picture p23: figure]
51eazpp-s2l

È stato scelto per diversi motivi. Il primo era dare la possibilita di avere un oggetto che chiunque potesse facilmente ed economicamente riprodurre. L’arianna ottenuta modificando una macchinina giocattolo è un esercizio istruttivo ma richiede tempo e manualità che non tutti hanno. Questo permette di fare esperienza e sviluppare software in poco tempo.
Inoltre la struttura a due motori separati permette un mobilità molto superiore allo sterzo classico. Il kit contiene anche i dischi encoder che servono per rilevare lo spostamento delle ruote e da questo identificare dove va Arianna (odometria).

Arrivato il kit è stato adattato per ospitare l’elettronica precedente. La scelta fatta di usare una piastra aggiuntiva che raccogliesse tutta l’elettronica ha permesso un “trapianto abbastanza semplice. Una nuova struttura è stata fatta sul kit per accogliere la piastra elettronica e sono stati collegati i motori, uno destro e uno sinistro, e in sensori degli encoder. La scheda Arduino è passata dal modello “Uno” alla “Mega 2560”. Vedremo nei prossimi articoli che il cambio si è reso necessario per gestire sotto interrupt anche gli encoder delle ruote.

Nelle foto la meccanica attuale. Per le connessioni meccaniche in questo modello si fa largo uso di connessioni usando delle mollette che si trovano in cartoleria.

Tramite opportune fessure fatte col seghetto è possibile unire pezzi meccanici in maniera robusta, veloce e facilmente smontabile.

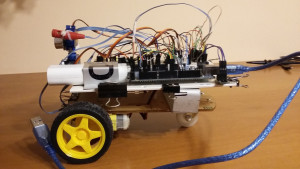
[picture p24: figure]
piastra controllo montata su base. Da sinistra, batteria. ATmega 2560, pan e tilt con sonar montato

piastra controllo montata su base. Da sinistra, batteria. ATmega 2560, pan e tilt con sonar montato

base: vista superiore

base: vista superiore

base: vista inferiore

base: vista inferiore

## Come sterza Arianna

Avendo due ruote motrici indipendenti è facile intuire che la direzione viene stabilita dalla velocità delle ruote, se vanno alla stessa velocità Arianna procederà diritta, con velocità diverse curverà più o meno. Dall’intuizione passiamo alla pratica che in questo caso è matematica.

formulacurva

moto circolare uniforme intorno a un punto. w è la velocità angolare, Vi,Vc, Ve le velocità tangenziali alla distanza ri, rc, re

Ve = re*w velocità ruota esterna, re raggio curva ruota e(sterna)
Vi = ri*w velocità ruota interna, ri raggio curva ruota i(nterna)
Vc = rc*w velocità punto centrale, rc raggio curva punto centrale

w = Vc/rc velocità angolare

Ve = re*Vc/rc
Vi = ri*Vc/rc

a = carreggiata, distanza tra le due ruote motrici.

Re = rc + a/2
Ri = rc – a/2

Ve = (rc + a/s)*Vc/rc = Vc + Vc*a/(2*rc) = Vc*(1 + a/(2*rc))
Vi = (rc – a/s)*Vc/rc = Vc – Vc*a/(2*rc) = Vc*(1 – a/(2*rc))

Detto:
S = a/(2*rc) scorrimento tra le ruote
V = Vc velocità di Arianna

possiamo scrivere:
Ve= V*(1+S)
Vi= V*(1-S)

Le formule sopra ci mostrano come imporre la velocità di Arianna (V) su una curva di raggio rc imponendo il parametro S.

- Con S=0 abbiamo le ruote che viaggiano alla stesso velocità e quindi andiamo diritti, notiamo che S diventa zero se il raggio di curvatura rc tende a infinito.
- Se S vale 1 abbiamo che Vi vale zero, Arianna girerà su se stessa con una ruota ferma, la formula ci mostra che S vale uno quando rc = a/2, cioè il raggio di curvatura è pari a mezza carreggiata.
- Quando S supera l’uno Vi girerà in senso negativo portando Arianna a ruotare sempre più su se stessa, sempre la formula mostra che con rc tendente a zero S tende a infinito.

https://youtu.be/tLTO42dV7H8

https://youtu.be/ULWIDnszzB4

Il codice che realizza questa funzione è riportato sotto, S è limitato tra +/- 1.

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
/* sterzo con differenziale

raggiorSterzo indica lo scorrimento che applichiamo alle ruote

VA = motorSpeed*(1-s)

VB = motorSpeed*(1+s)

S_NEUTRO è il valore per andare diritto

si ottiene per taratura (prova)

*/

void differenziale(float motorSpeed){

static float rs;

if (direzione) rs = raggiorSterzo + S_NEUTRO_FWD;

else rs = raggiorSterzo - S_NEUTRO_REV;

if (rs &gt; 1.0) rs = 1.0;

if (rs &lt; -1.0) rs = -1.0;

VA = motorSpeed*(1.0+rs);

VB = motorSpeed*(1.0-rs);

if (VA &gt; 255) VA = 255;

if (VA &lt; 0) VA = 0;

if (VB &gt; 255) VB = 255;

if (VB &lt; 0) VB = 0;

if (direzione){

driver.motorAReverse(VA);

driver.motorBReverse(VB);

}

else{

driver.motorAForward(VA);

driver.motorBForward(VB);

}

}

Abbiamo così lo strumento per fare sterzare Arianna.
La misura della distanza dal bordo l’abbiamo visto in arianna-e-i-suoi-fratelli-sperimentare-soluzioni/ (https://stuffcube.wordpress.com/2016/12/08/arianna-e-i-suoi-fratelli-sperimentare-soluzioni/)

# 5 il primo anello di controllo. Un sistema per correre parallelo alla libreria

il sistema di pilotaggio di Arianna dei motori delle ruote ci permette di fare curve più o meno larghe e abbiamo visto che una curva a raggio infinito equivale ad andare diritto. Perché correre diritto e paralleli alla libreria dovrebbe essere un problema? Approfondiamo la teoria e vediamone che la soluzione sta nell’introdurre un sistema di controllo retroazionato. Vedremo l’elemento di base dei sistemi di controllo che sono onnipresenti intorno a noi, dalla caldaia di casa ai jet militari a reazione che non possono volare senza questi sistemi attivi.

Per percorrere una retta le due ruote devono percorre lo stesso spazio.
Ci sono tre effetti che fanno si che il risultato sia vicino a quello atteso ma non abbastanza per garantire il risultato. Noi governiamo la velocità di rotazione di ogni singolo motore e quindi della ruota.
Supponiamo che le velocità siano uguali, devono essere identiche anche le ruote. Identiche significa perfettamente uguali anche nell’appoggio al terreno. Se la loro circonferenza differisse di un millimetro, che significa una differenza tra i diametri diverso di 3 decimi di mm, avremmo che per ogni giro ruota perderemmo un mm, nel nostro caso una differenza di circa lo 0.7 %. Un piccolo errore che sommato nel tempo, integrato (dalla funzione matematica di integrale) è il termine corretto, conduce a delle differente importanti.
Successivamente abbiamo lo slittamento delle ruote sul terreno, per piccola che sia Arianna, soffre anche lei di perdite di aderenza che fanno si che a un giro ruota non corrisponda esattamente un pari avanzamento sul pavimento.
Per ultimo l’effetto più importante, la differenza tra la velocità richiesta e quella ottenuta. Noi stiamo usando un motore in continua con rotore alimentato a spazzole e statore a magneti permanenti. Il rotore costituisce il circuito di armatura.

eqmotoredc

- Va è la tensione di armatura. Nel nostro caso la tensione generata dal PWM.
- Ia è la corrente di armatura.
- Ra è la resistenza di armatura
- La è l’induttanza di armatura
- Ke e Kt son due costanti, proprie del motore, dette costante elettrica e di coppia
- Cm la coppia motrice
- ω è la velocità di rotazione
- Eg è la tensione controelettromotrice generata dalla rotazione del motore. Questa dipende dalla velocità di rotazione.

A questa aggiungiamo l’equazione della meccanica che lega momento di inerzia, ‘J’, a Coppia motrice e Coppia resistente.

J*dω/dt = Cm – Cr

Il tutto per dire che la velocità del motore, ω, dipende da una serie di fattori. Il considerarla proporzionale alla tensione di alimentazione è una prima approssimazione.

E quindi??

Quindi se vogliamo governare il moto di Arianna non ci basta imporre le scorrimento tra le velocità dei motori, dobbiamo fare anche altro.

## Come guidiamo la macchina?

Quando guidiamo la macchina non lo facciamo ad occhi chiusi, sappiamo anzi che distogliere gli occhi dalla strada ci porta fuori via e dobbiamo correggere prontamente. Se scomponiamo le nostre azioni fatte inconsciamente queste sono nell’ordine:

- valutare nostra posizione rispetto ai bordi della strada,
- ruotare di conseguenza il volante. Questa azione modifica la posizione dell’auto.
- ritornare all’azione di valutazione. Punto 1

Il ripetere questo processo ci porta a seguire il percorso voluto. Questo algoritmo realizza un sistema di controllo ad anello chiuso.

## Controllo in anello chiuso

Vediamolo con uno schema a blocchi, una rappresentazione grafica dove le parti vengono scomposte e vengono indicate i collegamenti.
Nel nostro caso il robot Arianna viene rappresentato come un elemento, blocco, che riceve un valore di scorrimento “S” e in conseguenza a questo si porta a una certa distanza dalla libreria, la posizione reale. All’interno del blocco ci sarà una funzione matematica che rappresenta la fisica del sistema. Al momento non ci interessa adesso sapere come si ricava la funzione.
Vediamo invece come questa distanza fisica entri nel blocco “sensore IR” e da questo esca il numero “lettura sensore”. Questo è il blocco che rappresenta la misura fatta dal sensore IR. La misura viene condotta al nodo di differenza dove viene sottratto al valore “Riferimento”. Questo nodo o blocco si chiama di confronto. È un blocco fondamentale in un sistema di controllo, qui viene fatta la differenza tra il valore desiderato “Riferimento” e dove è realmente il “sistema”. La sua uscita è l’errore “e” che viene portato al “regolatore” altro blocco fondamentale del sistema. Il regolatore in funzione dell’errore produce l’azione di sterzata su Arianna. Siamo così tornati all’inizio dove il ciclo si ripete nuovamente. Nel nostro caso ogni 100 ms ripetiamo tutta l’operazione.

Il risultato di questo ripetersi è che quando Arianna si allontana o avvicina alla libreria viene sterzata in maniera opportuna per mantenersi alla distanza voluta.

Questo modo di operare si dice regolazione ad anello chiuso o a retroazione, il significato di chiuso sta nel blocco di ritorno “sensore IR”. Questo sensore misura la realtà e permette al sistema di reagire a ciò che accade realmente.

Abbiamo introdotto il concetto di sistema di controllo ad anello chiuso perché avevamo visto che governando solo i valori dei PWM non sapevamo esattamente dove saremmo andati. Quel metodo di controllo si chiama in anello aperto.

Introducendo la misura della distanza dalla libreria ci siamo dati un occhio (il sensore) con il blocco comparazione e il blocco regolatore siamo passati alla guida in funzione della distanza letta (sistema in anello chiuso)

## il codice del controllo

Tutto questi concetti si traducono in poche righe di codice:

1 2 3 4 5 6 7 8 9 10 11 12 13 14 15 16 17 18 19 | // parte a 100 ms if ((millis()-lastTime) &gt; 100){ lastTime = millis(); noInterrupts(); measureAvailable = 0; errore = 0.5 - misuraSideIR(0); // nodo di confronto interrupts(); // controllo sterzo da sensore laterale if (statoRun == 1){ raggiorSterzo = kp*errore; // regolatore proporzionale if (raggiorSterzo < -MAX_S) raggiorSterzo = -MAX_S; if (raggiorSterzo > MAX_S) raggiorSterzo = MAX_S; } // raggiorSterzo va al blocco differenziale che gestisce i due motori .....

ogni 100 ms il regolatore viene eseguito.
*per prima c’è una parte relativa alla gestione del sensore IR. Vengono bloccati gli interrupt per poter accedere ai dati in maniera coerente. Il flag measureAvailable viene azzerato per avviare la prossima misura. Sono dettagli che possiamo ora tarscurare.

*la riga sotto è il nodo di confronto. Il nostro sensore restituisce, nel suo range di misura, un numero reale 0 e 1. Mettiamo il riferimento al valore fisso di 0.5 in maniera da poter rimanere all’interno della sua capacità di misura.

1 | errore = 0.5 - misuraSideIR(0); // nodo di confronto

- il regolatore: quando Arianna è in movimento, statoRun == 1, viene eseguito la regolazione. L’errore viene moltiplicato per un numero kp detto guadagno proporzionale. Questo forma un regolatore Proporzionale. Il valore del guadagno verrà trovato in maniera empirica, con il sistema attuale numeri tra 4 e12 danno risultati disgnitosi. L’uscita del regolatore viene limitata con un valore MAX_S, questo evita che vengano applicate correzioni inutili (è inproduttivo sterzare a 90° se devo andare circa diritto, così come in autostrada facciamo correzioni dolci ). Il guadagno e il limite della correzzione possono essere cambiati in funzione della velocità e del tipo di movimento che facciamo adattandoli alle condizioni.

1 2 3 4 5 6 | // controllo sterzo da sensore laterale if (statoRun == 1){ raggiorSterzo = kp*errore; // regolatore proporzionale if (raggiorSterzo < -MAX_S) raggiorSterzo = -MAX_S; if (raggiorSterzo > MAX_S) raggiorSterzo = MAX_S; }

# 6 gli encoder

Arianna parafrasando Totò e Peppino si chiede “per andare dove devo andare, quanto devo andare?”, a questa domanda gli encoder danno la risposta.
Con encoder, nel caso di trasduttori di posizione, intendiamo dei dispositivi in grado di indicarci lo spostamento rotatorio di un albero o lineare di un carrello. Questo valore può essere assoluto o incrementale. I trasduttori possono essere di vari tipi: ai link https://en.wikipedia.org/wiki/Linear_encoder e https://en.wikipedia.org/wiki/Rotary_encoder, sono rappresentati esempi di encoder realizzati con diverse tecnologie.

Gli encoder sono composti di diverse parti: meccanica, elettronica, conteggio etc. In funzione dell’applicazione vengono acquistati già completi (es nell’automazione industriale) oppure costruiti con parti separate, per esempio in una stampante. Arianna ne ha uno realizzato a d hoc che ci permette di vedere le varie parti che lo costituiscono.

## Il trasduttore meccanico


Nel caso di Arianna usiamo un trasduttore incrementale rotatorio, detto anche angolare. Questo è un disco con dei fori lungo la periferia posto sull’asse della ruota, un sensore opportuno rileva il passaggio di ogni fessura, il numero di fessure sul disco è detto ppr cioè pulses per revolution. Quando contiamo ppr impulsi abbiamo fatto un giro. È possibile avere ppr che variano da 1 a decine di migliaia. Nel nostro caso ne abbiamo 20, con una ruota intorno ai 35 mm di diametro un impulso equivale a circa 5.25 mm.
Gli encoder possono anche indicare il senso di rotazione, nel nostro caso non abbiamo questa informazione.

## Sensore elettrico

La rilevazione degli impulsi encoder viene fatta con sensori a infrarossi, questi sono composti da un emettitore e un ricevitore. L’interruzione del fascio luminoso viene rilevata dal ricevitore e costituisce l’informazione. I modelli a forcella (fork) comprendono Tx e Rx meccanicamente allineati rendendoli facili da usare. Un modello usato è lo Omron ee_sx4070


Tx Rx a infrarossi per la lettura degli impulsi

Il Tx è composto da un diodo led a infrarossi, si decide la corrente di lavoro ponendo una resistenza in serie. Il ricevitore è un fototransistor, un transistor la cui base è alimentata dalla luce.
Per il fototransistor la radiazione luminosa ha lo stesso effetto di iniettare corrente in base. Facendola semplice lo fa commutare dandoci un livello alto o basso in uscita a seconda che il percorso Tx Rx sia libero o meno. Avendo un fototransistor va polarizzato per poter funzionare, può essere messo a collettore o emettitore comune e le correnti vanno viste dal data sheet.

fototransistor

fototransistor

Si consiglia di usare sensori con già uscita digitale. Si riconoscono dall’avere 5 terminali anziché quattro. Al loro interno hanno già la parte elettronica che squadra il segnale e gli applica una isteresi per evitare falsi conteggi. Per isteresi si intende che la tensione per dare un livello alto in uscita deve superare un valore Vh, per dare un livello basso non è sufficiente che scenda sotto Vh ma bensi sotto Vl, che è minore di Vh. Questa differenza di livelli, isteresi, fa si che in caso di segnali incerti nel commutare non si abbiano false commutazioni. Il simbolo nel triangolo è rappresenta l’isteresi.

uscita digitale

uscita digitale

## Conteggio hw o sw debounce

Il segnale in uscita del foto sensore va ora collegato a un ingresso digitale e contato. Questa operazione può essere fatta via software o tramite un circuito hardware. In ambedue i casi lo scopo è contare il numero di impulsi che sono arrivati.
Nel caso software possiamo mettere nel loop una lettura dell’ingresso, questo metodo è detto polling. Ovviamente non possiamo rimanere fermi ad attendere il fronte, faremmo solo quello. Dobbiamo ad ogni ciclo verificare un eventuale cambio dell’ingresso e a fronte di un cambio incrementare un contatore. La prossima verifica avverrà al prossimo passaggio. Il sistema è adatto ove il tempo di cambio del segnale sia molto maggiore del tempo di ciclo. Nel nostro caso vogliamo avere una velocità intorno ai 0.5 m/s, con una ruota di sviluppo 0.15 m abbiamo un giro ogni 0.333 s. Il sensore da 20 impulsi a giro e quindi un impulso ogni 16 ms, poiché un impulso è un ciclo 50% alto e 50% basso abbiamo 8 ms per riconoscerlo.
Voler utilizzare il sistema del polling costringe a scrivere un programma strozzato da questo vincolo, per esempio l’invio di dati con la seriale può causare perdita di impulsi encoder.

## L’interrupt

Questo problema si pose si dall’inizio della programmazione. Trovò una soluzione con l’interrupt o interruzione. Questo consiste nell’interrompere il flusso di istruzioni corrente per saltare a una parte di codice appunto di interrupt, al termine di questa sezione il controllo ritorna all’istruzione dove era stato interrotto. Così facendo il nostro processore sembra fare più cose insieme, in realtà ne fa sempre una per volta. Dal punto di vista logico l’interrupt ci permette di ragionare separando le cose dal punto di vista logico, alcune operazioni vengono eseguite in polling nel loop principale, quando serve un codice in interrupt gestisce immediatamente l’encoder.

dichiarazione dell’interrupt

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
/* odometro dx

pin 21 (atMega) int 2

la funzione attachInterrupt richiede:

il numero dell'interrupt da collegare. La funzione digitalPinToInterrupt() passandogli il pin lo

trova per noi;

la funzione o callBack da chiamare quando accade l'evento;

l'evento sul quale attivarsi, questo può essere fronte di salita (RISING), discesa (FALLING),

qualunque transizione (CHANGE).

*/

attachInterrupt(digitalPinToInterrupt(GIRO_DX_PIN), odometroDxMisuraHW, CHANGE);

// pin 20 (atMega) int 3

attachInterrupt(digitalPinToInterrupt(GIRO_SX_PIN), odometroSxMisuraHW, CHANGE);

routine di interrupt lato Destro

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
pin 21 (atMega) int 2

sotto interrupt incremmento contatore interi

solo se R != 0

*/

void odometroDxMisuraHW(void){

unsigned long pulseTime;

/*

questo test verifica il tempo tra due impulsi

se sono troppo vicini significa che c'è un errore nella lettura

*/

if ((millis() - pulseTime) < MIN_TIME_TRA_PULSE) return;

pulseTime = millis();

if (statoRun == 0) return;

//Serial.println("dx"); // debug

digitalWrite(ledPin, !digitalRead(ledPin)); // segnalazione visiva

if (direzione == AVANTI) odometroDxCnt ++;

else odometroDxCnt --;

}

Il codice in interrupt deve spesso essere veloce, cioè durare poco. Evitiamo quindi ove possibile di utilizzare conti “difficili” e fatti in floating point. Nella tabella sotto abbiamo una idea dei tempi di esecuzione con diversi formati. Vediamo che la divisione è un conto difficile, questo perché la moltiplicazione gode di una parte hardware dedicata alle moltiplicazioni 8 bit per 8 bit = 16 bit mentre la divisione no.

Nanosecond execution times on Arduino Mega2560 (16 MHz)
Operation uint8 int16 int32 int64 float
+ 63 884 1763 8428 10943
* 125 1449 4592 57038 10422
/ 15859 15969 41866 274809 31951

http://forum.arduino.cc/index.php?topic=196522.0

## Traduzione in spazio

Dal numero degli impulsi alla misura fisica il passo è breve, ci basta una moltiplicazione per la costante meccanica. La costante meccanica è il numero di mm che Arianna percorre per impulso encoder arrivato. Questa traduzione in unita fisiche, i mm, viene fatta solo quando ci serve. In questo caso nel task di controllo che gira ogni 100 ms. Giunta prossima alla posizione richiesta Arianna rallenta per poi fermarsi arrivata nell’intorno della destinazione fissato.

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
if ( distanza > odometro ) direzione = AVANTI;

else direzione = INDIETRO;

/* gestione velocità

se sono ancora fuori dalla zona di approccio

tengo la velocita' normale

*/

if ( abs(distanza - odometro) > E_APPROCCIO){

motorSpeedRef = motorSpeedValue;

}

else

// altrimenti attuo la velocita' di approccio

if ( abs(distanza - odometro) > E_POSIZIONAMENTO){

motorSpeedRef = APPROCCIO;

}

else{

// arrivato all'interno dell'errore di posizionamento

// mi fermo

motorSpeedRef = FERMO;

lastPosition = odometro;

statoRun = 0;

}

}// fine parte temporizzata TEMPO_CONTROLLO ms

// faccio le variazioni di velocita' con una rampa

if ((millis()-lastTimeFast) > 10){

lastTimeFast = millis();

if (statoRun == 0) motorSpeedRef = 0;

// rampa sulla velocita'

if (motorSpeedRef > motorSpeed) motorSpeed += 5;

if (motorSpeedRef < motorSpeed) motorSpeed -= 15; if (motorSpeed > 250) motorSpeed = 250;

if (motorSpeed < 1) motorSpeed = 0;

}// fine temporizzata veloce

# 7 Servomotori per Pan e Tilt, come muovo la testa.

Arianna si muove sul pavimento, giace su spazio bidimensionale definito con un piano cartesiano x, y. Il libro è posto nello spazio tridimensionale x, y, z. Una volta giunti di fronte allo scaffale cercato, cioè alle coordinate x, y ci manca la dimensione z, nel nostro caso l’altezza, per indicare dove sta il libro. La fantasia può immaginare tante idee ognuna coi suoi pro e contro. Arianna usa un sistema di pan e tilt con un puntatore a diodo. A fianco di questo c’è un progetto di puntatore più simpatico “innovativo” che presenteremo in futuro.

## Pan e Tilt

Pan e tilt sono i movimenti angolari di due assi. Il secondo asse e montato sul primo e quindi si muove con lui. Nel video il progetto per il supporto di un sensore a ultrasuoni fatto da Luca. Il cad permette di verificare movimenti e eventuali inetrferenze.

per muovere i due assi vengono utilizzati i servomotori utilizzati in auto radiocomandati. I servomotori per radiocomandi contengono al loro interno un sistema che permette, variando opportunamente duty cycle applicato, di imporre la posizione dell’albero. Lo schema a blocchi ci mostra le parti costituenti:


schema a blocchi del servomotore

- Il motore dc comanda il movimento meccanico
- Un riduttore a ingranaggi, gearbox, ne diminuisce la velocità di rotazione. L’albero lento è quello di uscita, output shaft, che viene usato per muovere gli oggetti.
- Su questo albero è montato un ingranaggio che si collega a un sensore di posizione. Il sensore, un piccolo potenziometro, ruota con l’albero di uscita, quindi la tensione sul cursore dipende dalla posizione.
- error signal è la differenza tra l’uscita del sensore di posizione e il riferimento, positional input signal.
- L’errore viene passato a un amplificatore capace di pilotare in maniera lineare il motore dc chiudendo l’anello. La parte sensore, nodo di confronto è l’anello di retroazione, feedback loop.

La struttura è la stessa usata per controllare che Arianna viaggiasse parallela alla libreria. La troveremo usata per altre funzioni e che impariamo a conoscere con diversi usi ma sempre lo stesso principio. Azione, misura dell’effetto, comparazione con il valore richiesto, errore e nuova azione.
La differenza tra i due controlli è che Arianna per correre parallela realizzava questo controllo nel software, in questo caso è realizzato con componenti analogici. Il primo è detto controllo digitale, il secondo controllo analogico.

## il software per comandare i servo

Per comandare i due servo usiamo le librerie presenti su Arduino. È sufficiente dichiarare l’oggetto servo e usare il metodo write per scrivere l’angolo desiderato.

1 2 3 4 5 6 7 8 | // dichiarazione degli oggetti Servo servoPan; // create servo object to control a servo Servo servoTilt; // create servo object to control a servo // loop vengono scritti gli angoli ai due servomotori servoPan.write ( panAngle); servoTilt.write(tiltAngle);

## La meccanica


montaggio dei servo

montaggio dei servo

la foto mostra come montare i servo uno sull’altro usando angolari, lamiera e mollette. Il pan e tilt serve a muovere un sensore di distanza a ultrasuoni e il diodo è usato per puntare il libro.

## Arianna indica il libro

https://youtu.be/BjnJZCtSfhg

La sequenza è dunque questa: Arianna arriva all’altezza dello scaffale che contiene il libro, ruota, si mette perpendicolare alla libreria e si allontana un poco.
Una volta ferma, tramite il sensore a ultrasuoni, misura la distanza dalla libreria. Conoscendo l’altezza dello scaffale da puntare calcola l’angolo di inclinazione del tilt, lo orienta e accende il puntatore.
Il servo del pan serve per correggere disallineamenti rispetto alla libreria e per muovere il puntatore per indicare la zona dove si trova il libro.
Il video mostra con ottimismo il libro esattamente puntato, nella realtà, si indica la zona dove sta.

# 8 Odometria

Nella prima puntata ci siamo detti che dobbiamo vedere col il punto di vista di Arianna, l’odometria è una tecnica che usa sensori per stimare dove ci si trova nello spazio. Se pensiamo alla nostra esperienza di vita è la vista il senso che ci fornisce il grosso delle informazioni per stabilire dove siamo. Stabilire dove siamo significa posizionarci nello spazio in relazione ad altri oggetti, quindi in maniera relativa. Messo in un spazio senza oggetti mi sento perso!
La visione ci permette di vedere a grandi distanze, ci risulta difficile provare questa senza sensazione a meno di entrare in camere appositamente realizzate in maniera da annullare la percezione di forme e ombre, Villa Panza a Varese ne ha ospitato sino a qualche anno fa un esempio http://www.aisthesis-fai.it/Ganzfeld.htm .
Possiamo provare una situazione di perdita di posizione se chiudiamo gli occhi, ci mettiamo al centro di una stanza senza toccare nulla e in un luogo senza sorgenti sonore, oppure all’aperto su un sentiero in un parco. Dopo qualche tempo con gli occhi chiusi iniziamo a perdere i riferimenti. Se ci muoviamo il nostro cervello inizia a stimare il nostro movimento e noi costantemente immaginiamo la nostra posizione salvo poi, aprendo gli occhi trovarci da tutt’altra parte. Quello che fa il nostro cervello è fondere tutte le informazioni provenienti dai nostri sensi e ricostruire il nostro movimento, mancando la vista che gli permette una verifica continua della posizione, deve aspettare di trovare un punto di riferimento e sperare di riconoscerlo.

L’odometria in base ai sensori di movimento posti sulle ruote, gli encoder, tenta di ricostruire la posizione di Arianna da quando inizia il suo percorso.

Usiamo come riferimento per questo post l’introduzione che troviamo all’indirizzo: odomtutorial.pdf (http://web.mit.edu/6.186/2007/tutorials/odomtutorial/odomtutorial.pdf).

## La posizione di Arianna

La posizione di Arianna è rappresentata in un piano cartesiano dalle sue coordinate x e y. Questo piano è il pavimento su cui si muove. L’origine è il punto da cui parte per mostrarci il libro, la x è allineata con la libreria, la y rappresenta la distanza da questa. Ci accorgiamo però che queste coordinate non bastano, manca dove è orientata, dove sta guardando. Questa terza variabile è teta, l’angolo che forma l’asse longitudinale del robot, centrato tra le ruote che va dal dietro al davanti, e l’asse delle x. Questo angolo vale quindi 0 se Arianna si muove lungo la libreria allontanandosi dalla base, vale 180 se torna verso la base.


Geometria. Su un periodo sufficientemente piccolo il moto del robot si approssima a un arco. Il problema della odometria è calcolare (x’, y’, teta’) a partire a (x, y, teta). Nella figura il robot si muove in senso antiorario. d_baseline è la distanza tra le due ruote (carreggiata).

La figura illustra il movimento delle due ruote del robot, d_left la distanza percorsa dalla ruota sinistra e d_right dalla destra. L’arco di cerchio percorso ha centro nel punto P. Essendo un moto circolare con centro P in ogni punto sul raggio r la distanza percorsa d vale:

d1 = φ*r1

Dagli encoder, ammesso di non avere slittamento, abbiamo la misura della distanza percorsa dalle singole ruote. Ci serve una formula che a partire dalla posizione attuale ci dia la prossima posizione.
Ripetendo il calcolo continuamente potremo stimare dove siamo.
Arianna calcolerà questo nel loop di controlloche viene eseguito ogni 100 ms, all’interno di questo periodo possiamo supporre che nel velocità dei due motori siano costanti anche se diverse. Vale quindi il disegno della figura 1. Da evidenziare che viaggiare in linea retta significa avere le due velocità uguali.

## La formula

Lo sviluppo della formula è riportato nell’introduzione indicata sopra. Concentriamoci sull’algoritmo che ne deriva.


Con riferimento alla figura sopra le formule da applicare a ogni giro sono le seguenti:


Gli ingressi sono dati dalle coordinate attuali (x, y, θ) e dallo spostamento delle due ruote d_left e d_right. La d_baseline è una costante meccanica, la carreggiata. Applicando le formule ne deriva il nuovo set di coordinate (x’, y’, θ’) che diventano a loro volta le nuove coordinate attuali. Il ciclo va dunque a ripetersi.

## Codice

Il codice raggruppa quanto visto nei post precedenti. Un sensore encoder per ogni ruota e quindi due routine di interrupt che agiscono su due contatori diversi.

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
#define GIRO_RUOTA 2.625 // mm per impulso*0.5 = sviluppo ruota[mm]/ppr (pulsi per rivoluzione)

#define GIRO_RUOTA_DX 2.625

#define GIRO_RUOTA_SX 2.615

// odometro

// pin 21 (atMega) int 2

attachInterrupt(digitalPinToInterrupt(GIRO_DX_PIN), odometroDxMisuraHW, CHANGE);

// pin 20 (atMega) int 3

attachInterrupt(digitalPinToInterrupt(GIRO_SX_PIN), odometroSxMisuraHW, CHANGE);

/*

pin 21 (atMega) int 2

sotto interrupt incremmento contatore interi

solo se R != 0. cioè se in movimento

*/

void odometroDxMisuraHW(void){

unsigned long pulseTime;

// se gli impulsi sono troppo vicini è dovuto a un disturbo

if ((millis() - pulseTime) < MIN_TIME_TRA_PULSE) return;

pulseTime = millis();

if (statoRun == 0) return;

if (direzione == AVANTI) odometroDxCnt ++;

else odometroDxCnt --;

}

/*

pin 20 (atMega) int 3

sotto interrupt incremmento contatore interi

solo se R != 0. cioè se in movimento

*/

void odometroSxMisuraHW(void){

unsigned long pulseTime;

// se gli impulsi sono troppo vicini è dovuto a un disturbo

if ((millis() - pulseTime) < MIN_TIME_TRA_PULSE) return;

pulseTime = millis();

if (statoRun == 0) return;

if (direzione == AVANTI) odometroSxCnt ++;

else odometroSxCnt --;

}

void updatePosition(void){

static long SxCnt_k_1 = 0; // valore cnt a k-1

static long DxCnt_k_1 = 0; // valore cnt a k-1

static long dDxCnt, dSxCnt; // delta cnt

static long letturaDx; // congelo cnt

static long letturaSx; // congelo cnt

static float deltaC; // delta cnt

// valore complessivo: usato temporaneamente

odometro = (odometroDxCnt + odometroSxCnt)*GIRO_RUOTA;

// calcolo evoluzione nel periodo

// blocco gli interrupt per fare le letture coerenti

noInterrupts();

letturaDx= odometroDxCnt;

letturaSx= odometroSxCnt;

interrupts();

dDxCnt = letturaDx - DxCnt_k_1; // delta sx e dx in count

dSxCnt = letturaSx - SxCnt_k_1;

deltaC = (dDxCnt + dSxCnt)*GIRO_RUOTA; // avanzamento del centro nel periodo in mm

DxCnt_k_1= letturaDx; // memoria per prossimo ciclo

SxCnt_k_1= letturaSx;

// integro teta

teta += ((float)dDxCnt*GIRO_RUOTA_DX - (float)dSxCnt*GIRO_RUOTA_SX)*2.0/BASELINE;

// integro posizioni

xpos += deltaC*cos(teta);

ypos += deltaC*sin(teta);

// monitor dati

if (monitorDati){

Serial1.print(dDxCnt);

Serial1.print(", ");

Serial1.print(dSxCnt);

Serial1.print(", ");

Serial1.print(deltaC);

Serial1.print(", ");

Serial1.print(teta);

Serial1.print(", ");

Serial1.print(xpos);

Serial1.print(", ");

Serial1.print(ypos);

Serial1.print(", ");

Serial1.print(errore);

Serial1.println();

}

}

Allo scattare del tempo viene chiamata la updatePosition. Qui viene eseguito l’algoritmo descritto, per risparmiare tempo si usano gli interi per i contatori sotto interrupt, le trasformazioni in float vengono fatte solo quando necessario per i conti difficili. Le costanti meccaniche per ogni impulso sono definite separatamente per ogni ruota. Durante la fase di taratura una differenza di 1 centesimo di mm per ogni impulso rendeva il sistema più preciso. Il valore equivale a 4 decimi di mm di differenza sullo sviluppo tra le due ruote.

## Risultato e Problemi

Grazie all’odometria è stato aggiunto un nuovo meccanismo di guida, è possibile definire l’angolo cioè la direzione del movimento. Il regolatore confronta l’angolo desiderato con il valore stimato dall’odometria. L’errore influisce sullo scorrimento tra le due ruote.
Il meccanismo funziona! Sotto il grafico dei valori x e y restituiti da Arianna con il monitorDati attivo.


Il grafico x, y mostra i punti stimati in un viaggio con varie curve. Il tragitto partiva da 0, 0 con direzione 0°, poi 180°, di nuovo 0°, -90° e per finire 180°. Le distanze da percorrere erano diverse nei vari tratti. È curioso come per passare da -90 a 180° Arianna abbia fatto un intero giro su se stessa, in realtà ha fatto quanto richiesto, infatti per curvare ancora verso destra avremmo dovuto dirgli di andare a -180°!! Per capirlo occorre ragionare un poco sugli angoli!

Una nota sulla posizione y, come si vede durante le curve si sposta dallo zero. anche qui nessuno stupore, quella che viene controllata è la direzione non le posizioni x e y.

Gli ondeggiamenti che si vedono sono dovuti alla dinamica del sistema e del regolatore, possiamo paragonarlo a quando guidando l’auto dobbiamo correggere più del dovuto, ad esempio uscendo velocemente da una curva o essendo lenti nelle correzioni.

Altra fonte di errore sono gli scivolamenti delle ruote sul terreno. La base del principio usato è la misura dello spostamento se questa è falsata il risultato è falsato. Il pavimento della biblioteca ha reso necessari degli ulteriori accorgimenti per evitare questo fenomeno.

Altro errore è la bassa risoluzione degli encoder usati, questi fanno si che la risoluzione minima dell’angolo sia circa 3.5°, valore di per se non male per l’angolo. Purtroppo questo errore riportato sulle y ad esempio da luogo a deviazioni notevoli. Possiamo dire che mentre l’angolo e quindi l’orientamento è sufficiente lo stesso non vale per le coordinate cartesiane.

Per finire rammentiamo che il meccanismo di stima della posizione per integrazione dei piccoli passi a lungo andare accumula forzatamente errori, questo rende necessari dei riallineamenti quando si passa in prossimità di punti noti. Riprendendo la metafora iniziale abbiamo che viaggiando ad occhi chiusi dobbiamo ogni tanto tastare le pareti alla ricerca di un punto di riferimento.

# Arianna ritorno alla docking station.

Per avere l’autonomia un robot mobile deve essere in grado di tornare da solo alla stazione di ricarica. Affidarsi alla sua capacità di sapere dove si trova grazie all’odometria non è sufficiente, sia per motivi sistematici, l’odometria è un processo di integrazione e quindi portato a fare errori, sia per cause accidentali come urti e ingombri sull terreno.

È necessario ricorrere a riferimenti esterni. Il metodo usato è basato su trasmettitori e ricevitori IR del tipo utilizzato nei telecomandi del televisore.

## Il metodo usato

Il principio è basato su una base fissa che monta due diversi trasmettitori. questi sovrappongono parzialmente i loro coni di emissione. Quando il robot è nel raggio di azione dei trasmettitori si muoverà per seguire la zona dove legge ambedue i fasci.

Figura 1: fascio emesso dai due diversi trasmettitori IR. I mezzo la zona centrale che guida al bersaglio.

Sul robot andiamo a porre tre ricevitori. Questo ci permette di avere una copertura angolare molto ampia.
Una soluzione alternative è usare un solo IR e orientarlo col PAN.

Figura 2: tre ricevitori a poco meno di 90° l'uno dall'altro allargano l'angolo di copertura

La realizzazione

### La base di trasmissione

La prima necessità era quella di limitare l’angolo di emissione del led IR. Questi hanno un ampio angolo di emissione


E’ utile sapere che gli infrarossi usati dai led (near IR) sono diversi da quelli termici (thermal IR) https://edavies.me.uk/2014/08/ir-myth/. Quelli dei nostri Led sono vicini di spettro alla luce visibile si comportano in maniera simile. Questo permette di limitare il cono di diffusione con del materiale che non riflette la luce. La verifica sperimentale ha confermato la funzionalità della schermatura.

Per identificare i trasmettitori si sono utilizzati due diversi codici, uno per il led destro e uno per il sinistro. Questi vengono trasmessi alternativamente per evitare sovrapposizioni. Il codice di trasmissione usato è quello dei telecomandi dei televisori implementato su una scheda Arduino.

Due transistor vengono utilizzati per fornire la corrente necessaria ad avere la portata di oltre tre metri.

### La parte ricevente

Questa parte è montata sul robot. Per sviluppare velocemente il test si è utilizzata una scheda arduino addizionale che comunica con la scheda principale tramite la seriale 4. Meccanicamente i tre ricevitori sono montati a 90 gradi l’uno dall’altro. I ricevitori sono circondati da separatori che restringono l’angolo di ricezione, facendolo più stretto per il ricevitore centrale il quale deve seguire la pista verso la docking station. Elettricamente si è usato un unico pin di ricezione, tramite delle porte logiche si abilita un ricevitore alla volta.

La stazione trasmittente emette alternativamente il due codici: CodeSx dal led sinistro e codice CodeDX dal quello destro.
Il ricevitore, su comando, avvia la scansione dei ricevitori. Il ciclo di lettura consiste in 20 letture sui tre sensori sinistro (sx), centrale (cnt) e destro (dx). Se il segnale letto corrisponde a un codice valido un viene incrementato il contatore relativo a ricevitore ( sx, cnt, dx) e sul codice ricevuto (CodeSx, CodeDX).

L’informazione del codice lettore e del numero di letture per il sensore sinistro, centrale, destro ha la forma seguente:

#{'CodeSX': {'sx': 8, 'ct': 0, 'dx': 0, 'cn': 0},

# 'CodeDX': {'sx': 9, 'ct': 0, 'dx': 0, 'cn': 0}}

### La procedura di ricerca della base

Quando si ritiene che il robot sia nel raggio di azione della docking station si avvia la procedura di ricerca della base (seeking). È una procedura ripetitiva composta da tre passi fondamentali: misura, scelta e azione.

1. Misura: lettura dati
2. scelta: decisione del movimento. Se arrivato vai alla fine
3. movimento: azione. Avanza della distanza e secondo l’angolo scelto e li si arresta.
4. torna a 1
5. fine

l’andamento è quindi simile all’avanzare di un ubriaco. Osserva i luoghi, decide dove andare, fa un piccolo spostamento, si arresta e ripete il ciclo

la misura è l’avvio della scansione dei sensori che ritorna la frequenza dei codici sui sensori.

La scelta deve decidere che movimento fare. Il robot viene comandato in angolo (direzione) e spazio da percorrere. Lo spazio è adesso fisso e pari a 100 mm. La direzione viene calcolata sommando alla direzione corrente un valore dato dalla seguente formula:

eDX = IRcode['CodeSX']['dx'] + IRcode['CodeDX']['dx']

eSX = IRcode['CodeSX']['sx'] + IRcode['CodeDX']['sx']

eCT = IRcode['CodeSX']['ct'] - IRcode['CodeDX']['ct']

# decidi

e = 4*eSX + eCT - 4*eDX

alfa += e

la formula fornisce un numero che rappresenta come il robot è inclinato rispetto alla base. Questo numero indica quanto, rispetto alla direzione corrente, sterzare a destra i sinistra.
partiamo da eCT, errore sui centrali, indica se il ricevitore frontale (centrale) riceve uniformemente i due codici. Lo sbilancio dei conteggi dei codici indica se sterzare a destra o sinistra.
Per i sensori sx e dx i conteggi si sommano andando richiedere di sterzare maggiormente. Il segno – su eDx attribuisce la direzione.
eSx ed eDx vengono moltiplicati per 4. Questo attribuisce un peso maggiore sull’angolo da parte di questi sensori.


Figura 3: le due righe superiori mostrano il CodeSx e CodeDx ricevuti dal sensore sx, cnt, dx. La riga inferiore a sinistra da l'errore ‘e’ e a destra l'angolo ‘alfa’. Sull’asse x il ciclo di ricerca. Attenzione alle scale sulle y diverse.

I grafici sopra mostrano un avvicinamento. Attenzione alle scale sulle y diverse. Nei primi cicli non vi sono segnali sui sensori centrali e sinistro. L’angolo passa da zero a 50 gradi in pochi cicli. Iniziano ad apparire letture sui sensori centrali sino a portare il robot a destinazione. Alcuni segnali sui sensori laterali arrivano per riflessione dovuta alle pareti circostanti.

Rimane da definire come decretare che il robot è arrivato alla base. È necessario rilevare l’arrivo del robot e inviare l’informazione di robot arrivato alla procedura di ricerca. Per la prima parte è stata realizzata una semplice barriera luminosa. Un diodo laser del tipo utilizzato per i puntatori luminosi illumina una cellula fotoelettrica. Quando il robot arriva interrompe il raggio e la resistenza della fotocellula cambia. Il micro della docking station rileva questa variazione.
Per trasferire l’informazione si è utilizzato il canale ad infrarossi. Quando il raggio è interrotto il codice trasmesso cambia e la procedura può agire di conseguenza.

## Miglioramenti

La procedura di ricerca può essere velocizzata misurando la distanza tramite il lidar dalla base e variando il passo di avanzamento del robot. Quando il sensore frontale è ben illuminato, ha cioè un numero elevato di codici ricevuti, è ragionevole ignorare i sensori laterali che possono ricevere riflessioni. La stazione di arrivo può modulare la potenza e il codice emesso, questo può permettere una valutazione ulteriore della posizione. Le stazione può dialogare col il robot tramite wifi o bluetooth per ulteriori strategie di sincronizzazione tra trasmissione e ricezione. Queste possono permettere la lettura al volo senza la necessità di fermata.

# 9 Tempo di libri, Technology Hub

StuffCube ha contribuito ad animare lo stand del consorzio delle biblioteche CSBNO alla fiera “Tempo di libri” che si svolge a Rho Fiera Milano. lo ha fatto con gli oggetti prodotti dai partecipanti, in questo caso le versioni di Arianna -il robot bibliotecario-, il braccio e mano meccanica Luka-Arm e un video su StuffCube.

Nel contempo ho visitato Technology Hub, una piccola fiera dedicata all’innovazione, che si teneva alla fiera di Milano city. I trend erano materiali compositi, la stampa 3d, la realtà aumentata e virtuale, i robot collaborativi.

Due fiere diverse, libri verso innovazione tecnologica. La domanda che mi sorge è : ”Sono veramente fiere diverse?”


A Technology Hub, in uno stand sulla robotica, in un video ho visto queste parole “ un robot lavora 24 ore al giorno, 365 giorni all’anno, non vuole aumenti di stipendio, non sciopera, non sbaglia”.

I robot collaborativi hanno la novità di poter lavorare a fianco di un essere umano, non dovendo essere confinati per ragioni di sicurezza, e possono apprendere da lui.
Nulla di nuovo, semplicemente la prosecuzione di quanto iniziato da Taylor all’inizio del secolo scorso. Taylor, citato spesso insieme a Ford, introdusse la scomposizione del lavoro in singole operazioni aumentando la produttività delle fabbriche.
Oltre ad aumentare l’efficienza questo modo di lavorare apprendeva dagli artigiani la conoscenza della tecnologia di produzione. Prima della fabbrica moderna erano gli artigiani che sapevano fare le cose e se le tramandavano in bottega. Nella fabbrica moderna con i concetti introdotti da Taylor e Ford ogni operaio sa fare solo la sua parte di lavoro e quindi è più produttivo e facilmente sostituibile.

Queste informazioni si trovano scritte sui libri che vanno letti e ne vanno letti molti perché ogni episodio della vita umana ha molti aspetti. Volendo dare uno spunto di riflessione direi che la lettura della storia del inizio del ‘900 propone temi attuali anche oggi.
Leggere i pensieri dei nostri predecessori ci permette di vedere lontano “di vedere seduti sulle spalle di giganti”.

Quello che voglio dire è che i libri, conoscenza umanistica cioè dell’uomo, e tecnologia non possono vivere separatamente, le grandi menti del Rinascimento, uno per tutti Leonardo, erano umanisti, tecnici e scienziati allo stesso tempo. Avere una tecnologia, con tutto il suo impatto sull’uomo, che si muove guidata da chi ignora cosa sia l’uomo non è bello e le conseguenze potrebbero essere spiacevoli.
L’atto di semplificare le cose va fatto quando le cose si sono comprese a fondo, oggi un malinteso processo di specializzazione e semplificazione ci fa perdere il quadro d’insieme degli accadimenti e quindi ci porta a decisioni che danno effetti imprevisti ma non imprevedibili.

# 10 IoT + Robotics = Cloud Robotics

Sabato 13 maggio abbiamo fatto un corso su IoT + Robotics = Cloud Robotics. Un progetto made in Torino per rendere facile la realizzazione di robot utilizzando il sistema ROS (Robot Operating System). Il lavoro è all’inizio, ambisce ad essere l’Arduino dei Robot connessi in rete.
Il termine robot è ampio e non si limita a solo quelli che si movono, un robot può anche accendere luci o aprire porte o quello che volete.

Nelle otto ore di workshop tenutosi a WeMake di Milano abbiamo giocato con alcuni robot, questi sono basati su Raspberry PI, tramite l’iterfaccia su cloud abbiamo acceso un led, inviato comandi a i motori da un joystick da web, da una interfaccia vocale, intefacciato al Raspberry una scheda Arduino via seriale.

Abbiamo inoltre conosciuto tante persone dalle esperienze più diverse che vanno a formare una comunità di sviluppatori, utilizzatori etc etc….

una giornata intensa con prospettive tutte da scoprire.

Low cost Open Source Robots now connect to the power of Cloud Computing
hotBlackRobotics (http://www.hotblackrobotics.com/)

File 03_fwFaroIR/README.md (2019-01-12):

IRsend02Esp

Il sistema ARIV3 comprende dei Fari IR. I fari IR sono dispositivi che emettono un segnale a infrarossi che può essere ricevuto dal robot. Questo sistema, come un faro costiero per una nave, permette ad ARI di seguirne la luce e raggiungerlo.

questo fw gestisce il faro IR.

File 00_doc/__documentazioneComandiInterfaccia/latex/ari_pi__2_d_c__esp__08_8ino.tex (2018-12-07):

\hypertarget{ari_pi__2_d_c__esp__08_8ino}{}\section{C\+:/\+Users/giorgio.rancilio/\+Dropbox/\+Makers\+Pgo/progetto\+Alfredo/arianna/ari2\+D\+Cmotor/arianna-\/arianna2dc/00\+\_\+ari\+\_\+\+V3\+\_\+git/\+A\+R\+I\+\_\+\+V3/02\+\_\+fw\+Arianna/ari\+Pi\+\_\+2\+D\+C\+\_\+esp\+\_\+08/ari\+Pi\+\_\+2\+D\+C\+\_\+esp\+\_\+08.ino File Reference}
\label{ari_pi__2_d_c__esp__08_8ino}\index{C\+:/\+Users/giorgio.\+rancilio/\+Dropbox/\+Makers\+Pgo/progetto\+Alfredo/arianna/ari2\+D\+Cmotor/arianna-\/arianna2dc/00\+\_\+ari\+\_\+\+V3\+\_\+git/\+A\+R\+I\+\_\+\+V3/02\+\_\+fw\+Arianna/ari\+Pi\+\_\+2\+D\+C\+\_\+esp\+\_\+08/ari\+Pi\+\_\+2\+D\+C\+\_\+esp\+\_\+08.\+ino@{C\+:/\+Users/giorgio.\+rancilio/\+Dropbox/\+Makers\+Pgo/progetto\+Alfredo/arianna/ari2\+D\+Cmotor/arianna-\/arianna2dc/00\+\_\+ari\+\_\+\+V3\+\_\+git/\+A\+R\+I\+\_\+\+V3/02\+\_\+fw\+Arianna/ari\+Pi\+\_\+2\+D\+C\+\_\+esp\+\_\+08/ari\+Pi\+\_\+2\+D\+C\+\_\+esp\+\_\+08.\+ino}}
{\ttfamily \#include $<$S\+P\+I.\+h$>$}\newline
{\ttfamily \#include $<$S\+D.\+h$>$}\newline
{\ttfamily \#include $<$Servo.\+h$>$}\newline
{\ttfamily \#include $<$T\+F\+Mini.\+h$>$}\newline
{\ttfamily \#include $<$E\+E\+P\+R\+O\+M.\+h$>$}\newline
{\ttfamily \#include $<$Wire.\+h$>$}\newline
{\ttfamily \#include $<$Adafruit\+\_\+\+Sensor.\+h$>$}\newline
{\ttfamily \#include $<$Adafruit\+\_\+\+L\+S\+M303\+\_\+\+U.\+h$>$}\newline
{\ttfamily \#include $<$math.\+h$>$}\newline
{\ttfamily \#include $<$D\+R\+V8833.\+h$>$}\newline
\subsection*{Macros}
\begin{DoxyCompactItemize}
\item 
\mbox{\Hypertarget{ari_pi__2_d_c__esp__08_8ino_ac4e2d6235f12dec9dc3674a0e0a139ba}\label{ari_pi__2_d_c__esp__08_8ino_ac4e2d6235f12dec9dc3674a0e0a139ba}} 
\#define {\bfseries V\+\_\+\+F\+W\+\_\+\+A\+T\+M\+E\+GA}~\char`\"{}3.\+04.\+00\char`\"{}
\item 
\mbox{\Hypertarget{ari_pi__2_d_c__esp__08_8ino_af5e2c0a692b6b075e9a95ac11a5c5b06}\label{ari_pi__2_d_c__esp__08_8ino_af5e2c0a692b6b075e9a95ac11a5c5b06}} 
\#define {\bfseries A\+R\+I3}~1
\item 
\mbox{\Hypertarget{ari_pi__2_d_c__esp__08_8ino_a0795d970ec6b0998fc398ecba0dc1fbc}\label{ari_pi__2_d_c__esp__08_8ino_a0795d970ec6b0998fc398ecba0dc1fbc}} 
\#define {\bfseries S\+C\+R\+I\+VI}~0
\item 
\mbox{\Hypertarget{ari_pi__2_d_c__esp__08_8ino_a6f99aa69652bb4f0435fbf31d21ba7c9}\label{ari_pi__2_d_c__esp__08_8ino_a6f99aa69652bb4f0435fbf31d21ba7c9}} 
\#define {\bfseries L\+E\+G\+GI}~1
\item 
\mbox{\Hypertarget{ari_pi__2_d_c__esp__08_8ino_a3da44afeba217135a680a7477b5e3ce3}\label{ari_pi__2_d_c__esp__08_8ino_a3da44afeba217135a680a7477b5e3ce3}} 
\#define {\bfseries D\+E\+F\+A\+U\+LT}~2
\item 
\mbox{\Hypertarget{ari_pi__2_d_c__esp__08_8ino_a8e296a962daed7fa0ffeeab350593594}\label{ari_pi__2_d_c__esp__08_8ino_a8e296a962daed7fa0ffeeab350593594}} 
\#define {\bfseries D\+U\+E\+\_\+\+PI}~6.\+28318
\item 
\mbox{\Hypertarget{ari_pi__2_d_c__esp__08_8ino_a3059d914dc801da27fea64290d8f0a28}\label{ari_pi__2_d_c__esp__08_8ino_a3059d914dc801da27fea64290d8f0a28}} 
\#define {\bfseries E\+S\+Pserial}~Serial2
\item 
\mbox{\Hypertarget{ari_pi__2_d_c__esp__08_8ino_a09582c1cafb46dfb44288122f23ed702}\label{ari_pi__2_d_c__esp__08_8ino_a09582c1cafb46dfb44288122f23ed702}} 
\#define {\bfseries T\+Fserial}~Serial1
\item 
\mbox{\Hypertarget{ari_pi__2_d_c__esp__08_8ino_acc60ca04f3ee450b48548582048ed8fa}\label{ari_pi__2_d_c__esp__08_8ino_acc60ca04f3ee450b48548582048ed8fa}} 
\#define \mbox{\hyperlink{ari_pi__2_d_c__esp__08_8ino_acc60ca04f3ee450b48548582048ed8fa}{S\+E\+R\+V\+O\+\_\+\+P\+A\+N\+\_\+\+P\+IN}}~45
\begin{DoxyCompactList}\small\item\em Digital IO pin connected to the servo pin. \end{DoxyCompactList}\item 
\mbox{\Hypertarget{ari_pi__2_d_c__esp__08_8ino_aacf6d5e66edfb457b13cbced950fc0af}\label{ari_pi__2_d_c__esp__08_8ino_aacf6d5e66edfb457b13cbced950fc0af}} 
\#define \mbox{\hyperlink{ari_pi__2_d_c__esp__08_8ino_aacf6d5e66edfb457b13cbced950fc0af}{S\+E\+R\+V\+O\+\_\+\+T\+I\+L\+T\+\_\+\+P\+IN}}~44
\begin{DoxyCompactList}\small\item\em Digital IO pin connected to the servo pin. \end{DoxyCompactList}\item 
\mbox{\Hypertarget{ari_pi__2_d_c__esp__08_8ino_a594090dbf515f41d4249fade4f14c463}\label{ari_pi__2_d_c__esp__08_8ino_a594090dbf515f41d4249fade4f14c463}} 
\#define \mbox{\hyperlink{ari_pi__2_d_c__esp__08_8ino_a594090dbf515f41d4249fade4f14c463}{G\+I\+R\+O\+\_\+\+D\+X\+\_\+\+P\+IN}}~3
\begin{DoxyCompactList}\small\item\em encoder rotazione albero motore I\+D\+\_\+009 \end{DoxyCompactList}\item 
\mbox{\Hypertarget{ari_pi__2_d_c__esp__08_8ino_ab1940449ba61cdf83d35a9dab25b039c}\label{ari_pi__2_d_c__esp__08_8ino_ab1940449ba61cdf83d35a9dab25b039c}} 
\#define \mbox{\hyperlink{ari_pi__2_d_c__esp__08_8ino_ab1940449ba61cdf83d35a9dab25b039c}{G\+I\+R\+O\+\_\+\+S\+X\+\_\+\+P\+IN}}~2
\begin{DoxyCompactList}\small\item\em encoder rotazione albero motore I\+D\+\_\+009 \end{DoxyCompactList}\item 
\mbox{\Hypertarget{ari_pi__2_d_c__esp__08_8ino_a3b5d438b9c0508db7c53e86daa265dc8}\label{ari_pi__2_d_c__esp__08_8ino_a3b5d438b9c0508db7c53e86daa265dc8}} 
\#define \mbox{\hyperlink{ari_pi__2_d_c__esp__08_8ino_a3b5d438b9c0508db7c53e86daa265dc8}{R\+\_\+\+S\+I\+D\+E\+\_\+\+F\+R\+O\+NT}}~29
\begin{DoxyCompactList}\small\item\em sensore frontale Dx Low = ostacolo \end{DoxyCompactList}\item 
\mbox{\Hypertarget{ari_pi__2_d_c__esp__08_8ino_a531e2edff1884d356024e8764761ffaa}\label{ari_pi__2_d_c__esp__08_8ino_a531e2edff1884d356024e8764761ffaa}} 
\#define \mbox{\hyperlink{ari_pi__2_d_c__esp__08_8ino_a531e2edff1884d356024e8764761ffaa}{L\+\_\+\+S\+I\+D\+E\+\_\+\+F\+R\+O\+NT}}~31
\begin{DoxyCompactList}\small\item\em sensore frontale Sx \end{DoxyCompactList}\item 
\mbox{\Hypertarget{ari_pi__2_d_c__esp__08_8ino_a551793442f7ac915171c5478f3df0955}\label{ari_pi__2_d_c__esp__08_8ino_a551793442f7ac915171c5478f3df0955}} 
\#define \mbox{\hyperlink{ari_pi__2_d_c__esp__08_8ino_a551793442f7ac915171c5478f3df0955}{E\+N\+B\+\_\+\+R\+\_\+\+S\+I\+D\+E\+\_\+\+F\+R\+O\+NT}}~28
\begin{DoxyCompactList}\small\item\em abilita sensore frontale Dx. High = Enable \end{DoxyCompactList}\item 
\mbox{\Hypertarget{ari_pi__2_d_c__esp__08_8ino_a5709a7b011efe9859445cf4a2c0646ea}\label{ari_pi__2_d_c__esp__08_8ino_a5709a7b011efe9859445cf4a2c0646ea}} 
\#define \mbox{\hyperlink{ari_pi__2_d_c__esp__08_8ino_a5709a7b011efe9859445cf4a2c0646ea}{E\+N\+B\+\_\+\+L\+\_\+\+S\+I\+D\+E\+\_\+\+F\+R\+O\+NT}}~30
\begin{DoxyCompactList}\small\item\em abilita frontale Sx \end{DoxyCompactList}\item 
\mbox{\Hypertarget{ari_pi__2_d_c__esp__08_8ino_a8aa85ae9867fabf70ec72cd3bf6fb6b9}\label{ari_pi__2_d_c__esp__08_8ino_a8aa85ae9867fabf70ec72cd3bf6fb6b9}} 
\#define \mbox{\hyperlink{ari_pi__2_d_c__esp__08_8ino_a8aa85ae9867fabf70ec72cd3bf6fb6b9}{L\+E\+D1}}~34
\begin{DoxyCompactList}\small\item\em L\+E\+D1. \end{DoxyCompactList}\item 
\mbox{\Hypertarget{ari_pi__2_d_c__esp__08_8ino_ad09fe5bf321b9a2de26bd5e5b9af6424}\label{ari_pi__2_d_c__esp__08_8ino_ad09fe5bf321b9a2de26bd5e5b9af6424}} 
\#define \mbox{\hyperlink{ari_pi__2_d_c__esp__08_8ino_ad09fe5bf321b9a2de26bd5e5b9af6424}{L\+E\+D2}}~33
\begin{DoxyCompactList}\small\item\em L\+E\+D2. \end{DoxyCompactList}\item 
\mbox{\Hypertarget{ari_pi__2_d_c__esp__08_8ino_a4b7ff8e253a7412f83deba3a447028a8}\label{ari_pi__2_d_c__esp__08_8ino_a4b7ff8e253a7412f83deba3a447028a8}} 
\#define \mbox{\hyperlink{ari_pi__2_d_c__esp__08_8ino_a4b7ff8e253a7412f83deba3a447028a8}{L\+E\+D3}}~32
\begin{DoxyCompactList}\small\item\em L\+E\+D3. \end{DoxyCompactList}\item 
\mbox{\Hypertarget{ari_pi__2_d_c__esp__08_8ino_a49ba715e713d99d1a5c20429dacaf073}\label{ari_pi__2_d_c__esp__08_8ino_a49ba715e713d99d1a5c20429dacaf073}} 
\#define \mbox{\hyperlink{ari_pi__2_d_c__esp__08_8ino_a49ba715e713d99d1a5c20429dacaf073}{led\+Pin}}~13
\begin{DoxyCompactList}\small\item\em led segnalazioni varie su Arduino \end{DoxyCompactList}\item 
\mbox{\Hypertarget{ari_pi__2_d_c__esp__08_8ino_ad29f66110456ba86205034ad1232fca8}\label{ari_pi__2_d_c__esp__08_8ino_ad29f66110456ba86205034ad1232fca8}} 
\#define \mbox{\hyperlink{ari_pi__2_d_c__esp__08_8ino_ad29f66110456ba86205034ad1232fca8}{laser\+Pin}}~8
\begin{DoxyCompactList}\small\item\em porta puntatore laser \end{DoxyCompactList}\item 
\mbox{\Hypertarget{ari_pi__2_d_c__esp__08_8ino_a61f762ee849a4b411a7cc07d78dde55d}\label{ari_pi__2_d_c__esp__08_8ino_a61f762ee849a4b411a7cc07d78dde55d}} 
\#define \mbox{\hyperlink{ari_pi__2_d_c__esp__08_8ino_a61f762ee849a4b411a7cc07d78dde55d}{T\+E\+S\+T\+\_\+\+M\+O\+T\+O\+RE}}~0
\begin{DoxyCompactList}\small\item\em modalità di test per fasi di debug \end{DoxyCompactList}\item 
\mbox{\Hypertarget{ari_pi__2_d_c__esp__08_8ino_a3e6a2d7b0da74a50b9fd5b16aace4414}\label{ari_pi__2_d_c__esp__08_8ino_a3e6a2d7b0da74a50b9fd5b16aace4414}} 
\#define \mbox{\hyperlink{ari_pi__2_d_c__esp__08_8ino_a3e6a2d7b0da74a50b9fd5b16aace4414}{T\+E\+S\+T\+\_\+\+S\+T\+E\+R\+ZO}}~1
\begin{DoxyCompactList}\small\item\em modalità di test per fasi di debug \end{DoxyCompactList}\item 
\mbox{\Hypertarget{ari_pi__2_d_c__esp__08_8ino_addf0ed25cb1de6ac65f3f60a7f50c01a}\label{ari_pi__2_d_c__esp__08_8ino_addf0ed25cb1de6ac65f3f60a7f50c01a}} 
\#define \mbox{\hyperlink{ari_pi__2_d_c__esp__08_8ino_addf0ed25cb1de6ac65f3f60a7f50c01a}{T\+E\+S\+T\+\_\+\+S\+E\+N\+S\+O\+RS}}~2
\begin{DoxyCompactList}\small\item\em modalità di test per fasi di debug \end{DoxyCompactList}\item 
\mbox{\Hypertarget{ari_pi__2_d_c__esp__08_8ino_ab57f62e8f32f367dbca255771ff72e20}\label{ari_pi__2_d_c__esp__08_8ino_ab57f62e8f32f367dbca255771ff72e20}} 
\#define \mbox{\hyperlink{ari_pi__2_d_c__esp__08_8ino_ab57f62e8f32f367dbca255771ff72e20}{T\+E\+S\+T\+\_\+\+C\+O\+N\+T\+R\+O\+L\+LO}}~3
\begin{DoxyCompactList}\small\item\em modalità di test per fasi di debug \end{DoxyCompactList}\item 
\mbox{\Hypertarget{ari_pi__2_d_c__esp__08_8ino_adcc6c25175a8908813ff718bc774c2ab}\label{ari_pi__2_d_c__esp__08_8ino_adcc6c25175a8908813ff718bc774c2ab}} 
\#define \mbox{\hyperlink{ari_pi__2_d_c__esp__08_8ino_adcc6c25175a8908813ff718bc774c2ab}{T\+E\+S\+T\+\_\+\+G\+I\+R\+O\+\_\+\+S\+E\+N\+S\+OR}}~4
\begin{DoxyCompactList}\small\item\em modalità di test per fasi di debug \end{DoxyCompactList}\item 
\mbox{\Hypertarget{ari_pi__2_d_c__esp__08_8ino_ab6c0fc0e0028f3917b0ce67bee73d01e}\label{ari_pi__2_d_c__esp__08_8ino_ab6c0fc0e0028f3917b0ce67bee73d01e}} 
\#define \mbox{\hyperlink{ari_pi__2_d_c__esp__08_8ino_ab6c0fc0e0028f3917b0ce67bee73d01e}{T\+E\+M\+P\+O\+\_\+\+C\+O\+N\+T\+R\+O\+L\+LO}}~25
\begin{DoxyCompactList}\small\item\em tempo del controllo sterzo, posizione etc in ms \end{DoxyCompactList}\item 
\mbox{\Hypertarget{ari_pi__2_d_c__esp__08_8ino_a140e19c4b6cb883d0f3abceea67a62ba}\label{ari_pi__2_d_c__esp__08_8ino_a140e19c4b6cb883d0f3abceea67a62ba}} 
\#define \mbox{\hyperlink{ari_pi__2_d_c__esp__08_8ino_a140e19c4b6cb883d0f3abceea67a62ba}{E\+\_\+\+P\+O\+S\+I\+Z\+I\+O\+N\+A\+M\+E\+N\+TO}}~10
\begin{DoxyCompactList}\small\item\em \mbox{[}mm\mbox{]}, distanza dall\textquotesingle{}obbiettivo dove il robot si arresta \end{DoxyCompactList}\item 
\mbox{\Hypertarget{ari_pi__2_d_c__esp__08_8ino_a60736df151b230ad9683a2e8dbee13a6}\label{ari_pi__2_d_c__esp__08_8ino_a60736df151b230ad9683a2e8dbee13a6}} 
\#define \mbox{\hyperlink{ari_pi__2_d_c__esp__08_8ino_a60736df151b230ad9683a2e8dbee13a6}{E\+\_\+\+A\+P\+P\+R\+O\+C\+C\+IO}}~300
\begin{DoxyCompactList}\small\item\em \mbox{[}mm\mbox{]}, distanza dall\textquotesingle{}obbiettivo dove il robot inizia a rallentare \end{DoxyCompactList}\item 
\mbox{\Hypertarget{ari_pi__2_d_c__esp__08_8ino_a3ea4f86fda9125c7b34d735b4f14f42a}\label{ari_pi__2_d_c__esp__08_8ino_a3ea4f86fda9125c7b34d735b4f14f42a}} 
\#define \mbox{\hyperlink{ari_pi__2_d_c__esp__08_8ino_a3ea4f86fda9125c7b34d735b4f14f42a}{F\+E\+R\+MO}}~0
\begin{DoxyCompactList}\small\item\em valore pwm di uscita durante stato di F\+E\+R\+MO \end{DoxyCompactList}\item 
\mbox{\Hypertarget{ari_pi__2_d_c__esp__08_8ino_a4774b749cfc65db93b2e726543c9115f}\label{ari_pi__2_d_c__esp__08_8ino_a4774b749cfc65db93b2e726543c9115f}} 
\#define \mbox{\hyperlink{ari_pi__2_d_c__esp__08_8ino_a4774b749cfc65db93b2e726543c9115f}{M\+O\+D\+E\+R\+A\+TA}}~190
\begin{DoxyCompactList}\small\item\em valore pwm di uscita durante marcia M\+O\+D\+E\+R\+A\+TA \end{DoxyCompactList}\item 
\mbox{\Hypertarget{ari_pi__2_d_c__esp__08_8ino_a3336677c5466ffd6adee69e68e25f236}\label{ari_pi__2_d_c__esp__08_8ino_a3336677c5466ffd6adee69e68e25f236}} 
\#define \mbox{\hyperlink{ari_pi__2_d_c__esp__08_8ino_a3336677c5466ffd6adee69e68e25f236}{A\+P\+P\+R\+O\+C\+C\+IO}}~110
\begin{DoxyCompactList}\small\item\em valore pwm di uscita durante marcia A\+P\+P\+R\+O\+C\+C\+IO \end{DoxyCompactList}\item 
\mbox{\Hypertarget{ari_pi__2_d_c__esp__08_8ino_a9af1e62ce938e1b51a846fc15cf307e3}\label{ari_pi__2_d_c__esp__08_8ino_a9af1e62ce938e1b51a846fc15cf307e3}} 
\#define \mbox{\hyperlink{ari_pi__2_d_c__esp__08_8ino_a9af1e62ce938e1b51a846fc15cf307e3}{A\+C\+C\+E\+L\+E\+R\+A\+Z\+I\+O\+NE}}~160
\begin{DoxyCompactList}\small\item\em valore pwm di uscita durante fase accelerazione (non usato) \end{DoxyCompactList}\item 
\mbox{\Hypertarget{ari_pi__2_d_c__esp__08_8ino_a7d6e95bc7ca024893f2bd7d217b2bd6d}\label{ari_pi__2_d_c__esp__08_8ino_a7d6e95bc7ca024893f2bd7d217b2bd6d}} 
\#define {\bfseries A\+V\+A\+N\+TI}~0
\item 
\mbox{\Hypertarget{ari_pi__2_d_c__esp__08_8ino_a8db0e8841207a8e9ce1845ba10b4a637}\label{ari_pi__2_d_c__esp__08_8ino_a8db0e8841207a8e9ce1845ba10b4a637}} 
\#define {\bfseries I\+N\+D\+I\+E\+T\+RO}~1
\item 
\mbox{\Hypertarget{ari_pi__2_d_c__esp__08_8ino_a6ae4300a3f1fbbb8e3d4393603b6d402}\label{ari_pi__2_d_c__esp__08_8ino_a6ae4300a3f1fbbb8e3d4393603b6d402}} 
\#define \mbox{\hyperlink{ari_pi__2_d_c__esp__08_8ino_a6ae4300a3f1fbbb8e3d4393603b6d402}{K\+P\+\_\+\+T\+E\+T\+A\+\_\+\+D\+EF}}~0.\+8
\begin{DoxyCompactList}\small\item\em valore default P contrllo guida con distanza muro \end{DoxyCompactList}\item 
\mbox{\Hypertarget{ari_pi__2_d_c__esp__08_8ino_ae69228439056c7947d8c67f0e31cd555}\label{ari_pi__2_d_c__esp__08_8ino_ae69228439056c7947d8c67f0e31cd555}} 
\#define \mbox{\hyperlink{ari_pi__2_d_c__esp__08_8ino_ae69228439056c7947d8c67f0e31cd555}{M\+A\+X\+\_\+\+S\+T\+E\+R\+ZO}}~1.\+0
\begin{DoxyCompactList}\small\item\em massimo valore di sterzo. con 1 si ha una ruota ferma e l\textquotesingle{}altra al doppio della velocita\textquotesingle{} \end{DoxyCompactList}\end{DoxyCompactItemize}
\subsection*{Functions}
\begin{DoxyCompactItemize}
\item 
\mbox{\Hypertarget{ari_pi__2_d_c__esp__08_8ino_a4fc01d736fe50cf5b977f755b675f11d}\label{ari_pi__2_d_c__esp__08_8ino_a4fc01d736fe50cf5b977f755b675f11d}} 
void \mbox{\hyperlink{ari_pi__2_d_c__esp__08_8ino_a4fc01d736fe50cf5b977f755b675f11d}{setup}} ()
\begin{DoxyCompactList}\small\item\em setup della parte hardware e caricamento coefficienti da E2prom \end{DoxyCompactList}\item 
void \mbox{\hyperlink{ari_pi__2_d_c__esp__08_8ino_afe461d27b9c48d5921c00d521181f12f}{loop}} ()
\item 
void \mbox{\hyperlink{ari_pi__2_d_c__esp__08_8ino_a6af06b46b74b5a44e1adc270e1e07e6b}{odometro\+Dx\+Misura\+HW}} (void)
\begin{DoxyCompactList}\small\item\em odometri \end{DoxyCompactList}\item 
\mbox{\Hypertarget{ari_pi__2_d_c__esp__08_8ino_aef8d9e68883244c4d12fb9dfb14b0b2e}\label{ari_pi__2_d_c__esp__08_8ino_aef8d9e68883244c4d12fb9dfb14b0b2e}}
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

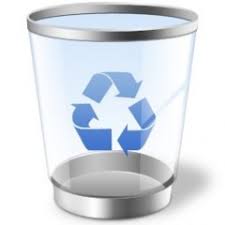
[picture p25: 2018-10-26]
01_pcSoftware/arianna_cli_socket2.2/scheda/images/cancella_all.jpg

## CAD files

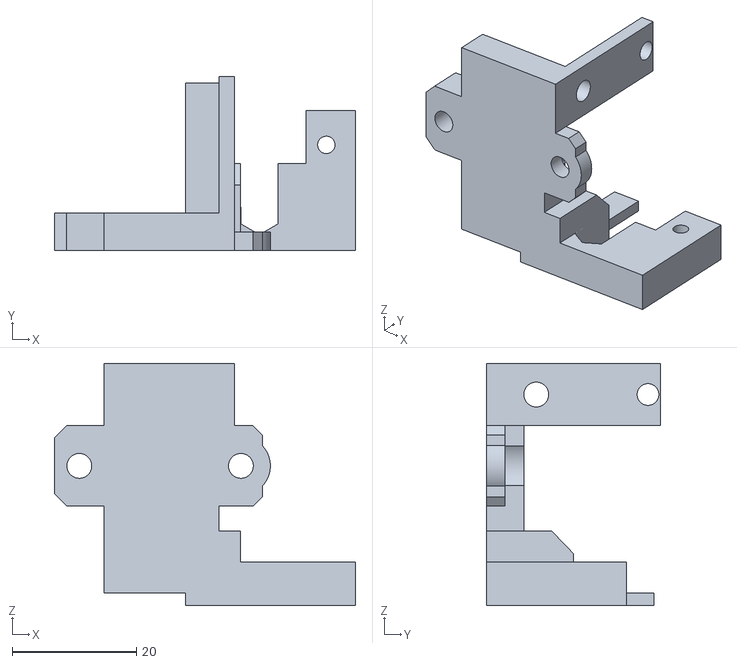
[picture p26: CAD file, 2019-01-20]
04_disegni3D/stl/ARI_V3_supportoMotoreEncoder_V2.stl
48.5 x 28.0 x 39.0

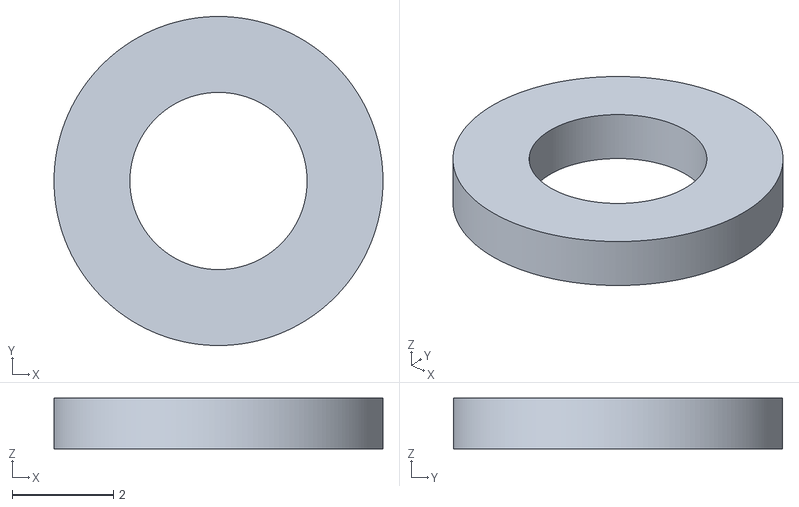
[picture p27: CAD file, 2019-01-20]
04_disegni3D/stl/ARI_V3_rondella.stl
6.50 x 6.50 x 1.00

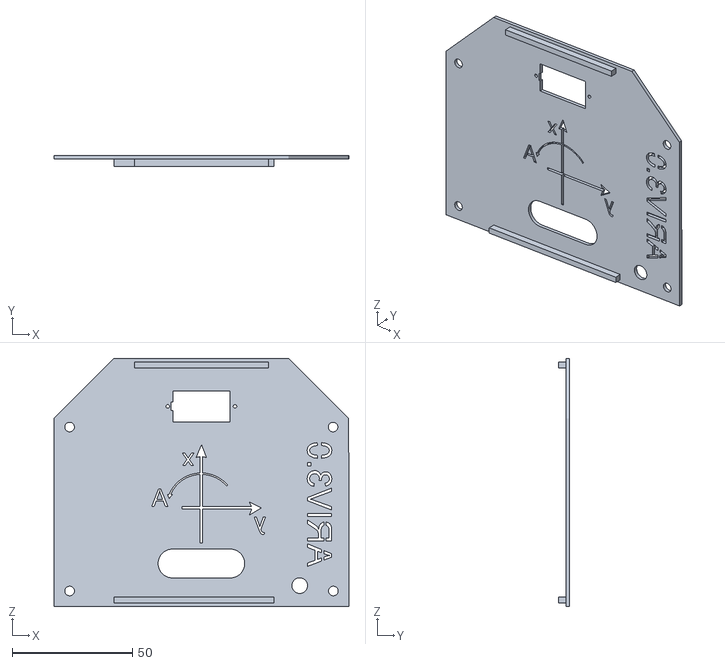
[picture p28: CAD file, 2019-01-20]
04_disegni3D/stl/ARI_V3_coperchio.stl
122.7 x 4.50 x 103.3

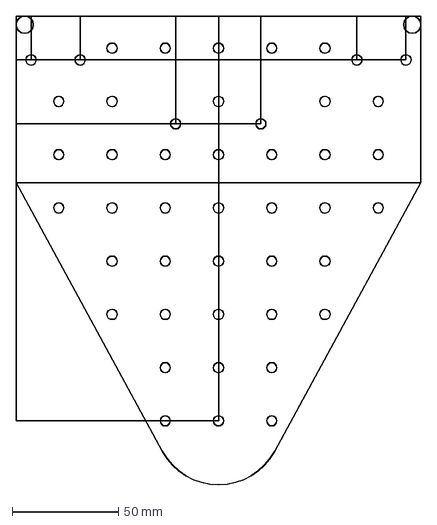
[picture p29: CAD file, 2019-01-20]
04_disegni3D/stl/ARI_V3_baseSupportoGrigliaFori.dxf
190.0 x 220.0 mm

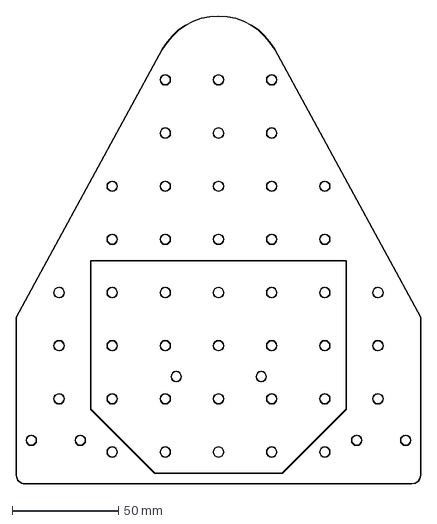
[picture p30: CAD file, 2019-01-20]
04_disegni3D/stl/ARI_V3_piastraSupportoBatteria.dxf
190.0 x 220.0 mm

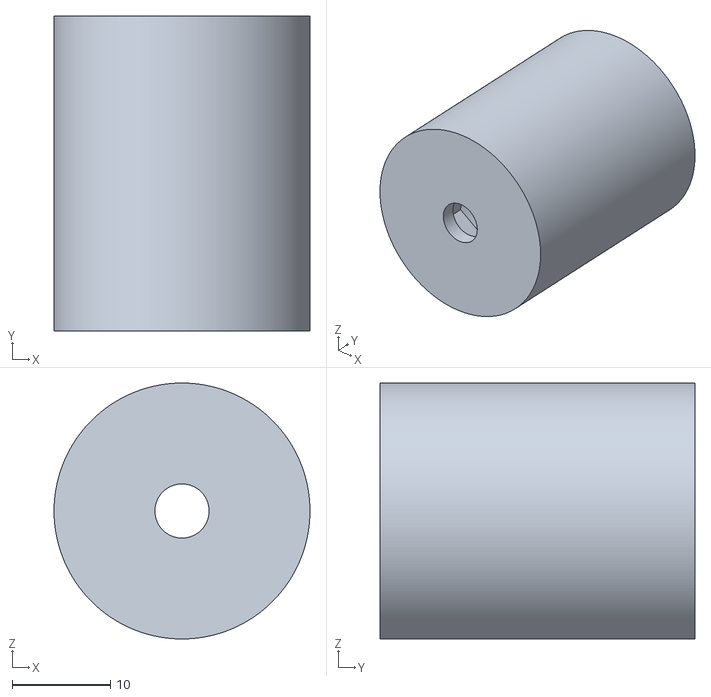
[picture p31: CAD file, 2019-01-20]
04_disegni3D/stl/ARI_V3_omniDue.stl
26.0 x 32.0 x 26.0

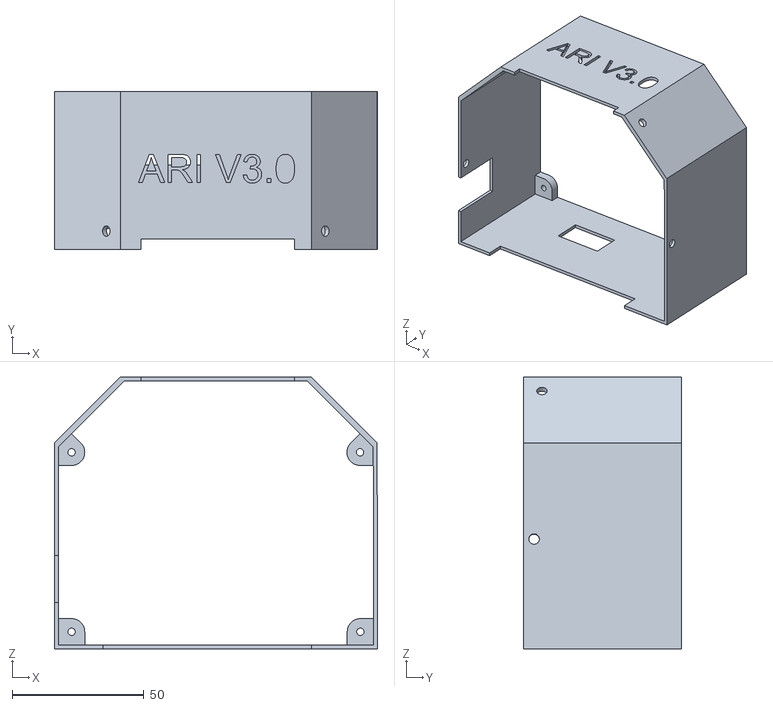
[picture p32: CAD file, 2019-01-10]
04_disegni3D/stl/ARI_V3_contenitore.stl
122.7 x 60.0 x 103.3

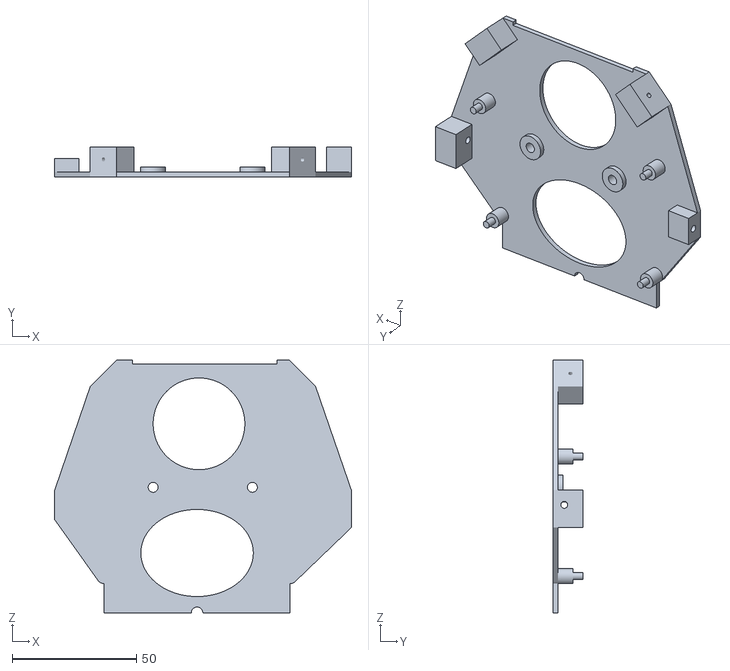
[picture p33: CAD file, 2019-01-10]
04_disegni3D/stl/ARI_V3_baseSupporto.stl
119.7 x 12.0 x 101.8

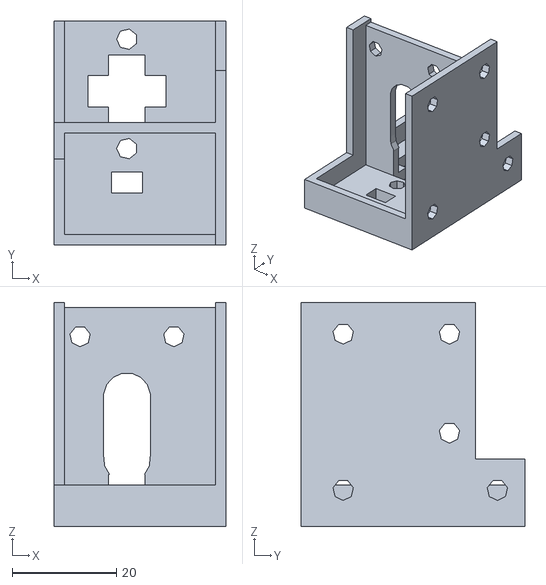
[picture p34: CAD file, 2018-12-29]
04_disegni3D/stl/motorMount_v2.stl
33.0 x 43.0 x 43.0

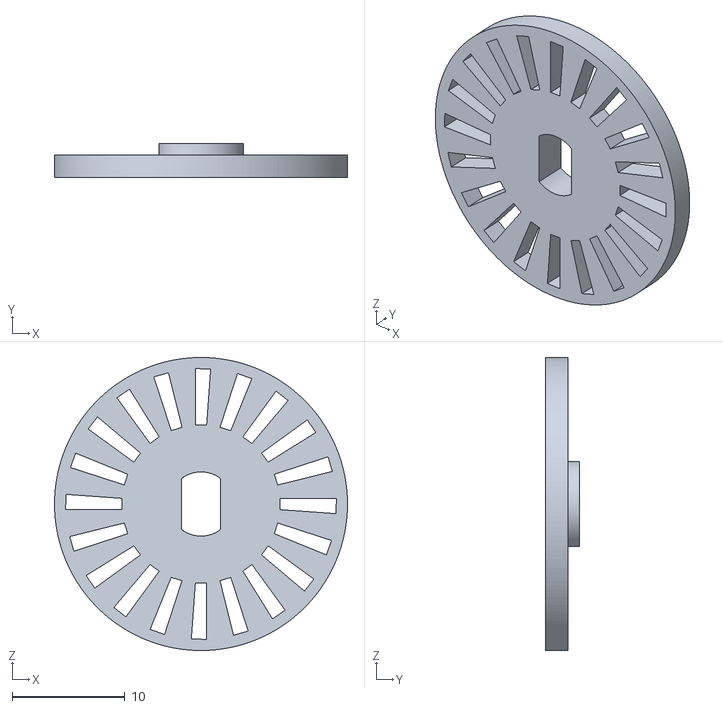
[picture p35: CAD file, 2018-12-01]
04_disegni3D/stl/rotelleEncoderTaccaLarga20.stl
26.0 x 3.00 x 26.0

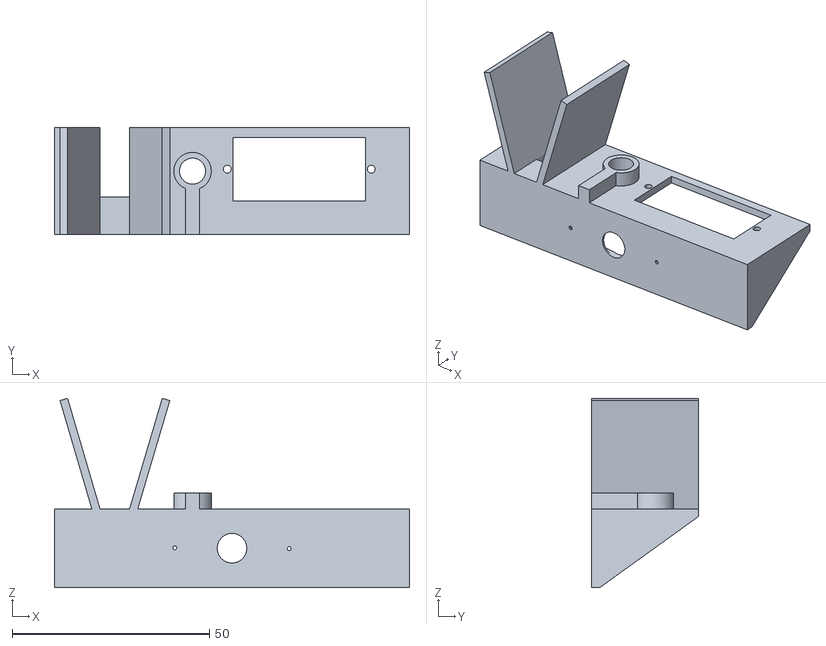
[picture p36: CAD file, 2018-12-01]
04_disegni3D/stl/poratLidarServoPiccolo v4.stl
90.0 x 27.0 x 48.0

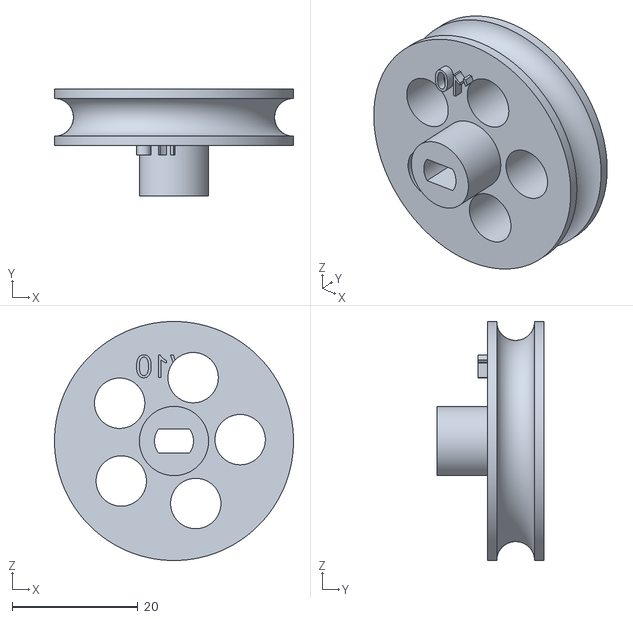
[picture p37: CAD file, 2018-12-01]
04_disegni3D/stl/ruotaMotricePiccola v11.stl
38.0 x 17.0 x 38.0

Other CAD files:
04_disegni3D/stl/motorMount_v2.scad

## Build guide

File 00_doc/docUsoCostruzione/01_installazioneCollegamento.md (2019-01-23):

# Impostazioni e taratura

## configurazione

Una volta montata ARI V3 occorre configurarla per fargli conoscere come è il suo corpo. Le informazioni che servono sono:

*La Carreggiata o Baseline*: distanza tra le ruote in mm
Lo *Sviluppo della ruota* in mm, la sua circonferenza che è pari a 3.14 volte il diametro.
I *ppr* (Pulses Per Revolution) degli encoder. Il numero di tacche che ha il disco dell’encoder.

carreggiata

Con questi valori si ricavano i parametri del robot.

`Baseline   = Carreggiata`
`Giro Ruota = sviluppo ruota[mm]/(4*ppr)`
`ED         = 1`
`ED_BASE    = 1`

Calcolati questi numeri tramite la CLI[[1\]](#_ftn1) li configuro su ARI V3. 
Scritto il comando lo si invia con *InviaCmd*.



## I comandi

I comandi hanno la seguente forma:

Yn(m)xxx: 

il primo numero (Y) indica l’azione. 3 significa scrittura, 1 lettura. 
n e il carattere opzionale m indica(no) quale azione fare, nell’esempio sotto F1 significa scrivi ED_BASE i caratteri successivi contengono l’argomento del comando, di norma il valore.
Ad ogni comando inviato viene ritornata una risposta “leggibile”. ad esempio se invio “3F11” mi viene ritornato “F1_ED_BASE: 1.000000”

Il comando è il seguente:

Fnxxx: imposta dei parametri del robot. "n" indica quale parametro, "xxx" è il valore. 

    F0xx 	ED           
    F1xx 	ED_BASE            
    F2xx 	BASELINE           mm
    F3xx 	GIRO_RUOTA   mm = sviluppo ruota[mm]/(4*ppr)

N.B. questi valori vanno attivati con un 3E3

Esempio:

carreggiata = 220 mm
 diametro ruota = 50 mm
 ppr = 20

sviluppo ruota = 3.14*50 = 157 mm

Giro Ruota = sviluppo ruota[mm]/(4*ppr) = 157/(4*20) = 1.9625 mm

Comandi da inviare:

E2                          carica i valori di default.
 E3                          attiva i valori
 E0                          salva i valori in E2prom

I valori di default sono quelli sotto riportati.

 dovendo modificare i valori sotto sono riportati i singoli comandi.

ED                         = 1          inviare                  **F01**. **N.B. 0 è “zero” non “O” maiuscolo** ED_BASE                = 1          inviare                  **F11** 
 BASELINE               = 220     inviare                  **F2220** 
 GIRO_RUOTA       =1.9625 inviare                   **F31.9625** 

inviare E3 per attivare i valori. La risposta conterrà la lista dei parametri attiva. Questo parametro serve anche per mostrare i parametri in uso.

E0 per salvarli nella EEprom[[1\]](#_ftn1) di ARI V3. Cosi facendo verranno ricaricati ad ogni accensione.

# Verifica dei dati.

Per vedere se i numeri “quadrano” muoviamo ARI. Facciamogli fare un movimento e vediamo come va. Mi serve un metro per misurare lo spazio percorso.

## Verifica distanza

Accendo e spengo ARI.

**3D1000** definisco un percorso di 1000 mm.
 **3R1**                      la faccio muovere in linea retta. ARI dovrebbe partire e fermarsi dopo un metro circa.

Se la distanza percorsa non è corretta aggiusto GIRO_RUOTA opportunamente.. formula

## Verifica centratura

È probabile che il percorso non sia rettilineo e tenda a curvare verso destra o sinistra. Il fenomeno è dovuto alle ruote che pur simili hanno differenze minime. Aggiustando il parametro ED si corregge questo comportamento, ED infatti modifica il diametro delle ruote sinistra e destra rendendoli diversi. 
 ED si modifica a piccoli passi, qualche percento alla volta, per esempio 1.01 oppure 0.99. Se lo si aumenta ARI va verso destra, diminuendolo ruota verso sinistra.

Per attivare il valore ED = 1.02 la sequenza è:

passo 1: impostazione parametro

**3F01.02**                             per impostare il nuovo valore 1.02
 **3E3**                                      per attivare i valori, la risposta

Passo 2:Test 

**3D1000** definisco un percorso di 1000 mm.
 **3R1**                      la faccio muovere in linea retta. 

Muove verso destra?      Diminuisco ED e torno al passo 1 
 Muove verso sinistra?     aumento ED e torno al passo 1 

Muove diritta? Proseguo e salvare i dati

**3E0**                       salvo i dai in memoria EEprom. 

Ex: EEprom.  Esegue operazioni su dei parametri di taratura. Vedi procedura DataEEprom. 

    E0 SCRIVI i parametri in E2prom,            

    E1 LEGGI i parametri in E2prom,             

    E2 rispristina in valori di DEFAULT,            

    E3 attiva e mostra i parametri CORRENTI,             

------

[[1\]](#_ftnref1) EEprom oppure E2prom. Electrically Erasable Programmable Read-Only Memory. Una memoria dove i dati possono essere letti, scritti e conservati anche senza tensione, cioè a chip spento.

------

[[1\]](#_ftnref1) CLI, Command Line Interface. È la finestra con la quale inviamo I comandi digitandoli sulla tastiera.

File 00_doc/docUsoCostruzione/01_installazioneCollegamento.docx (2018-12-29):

Tabella aggiornamenti
data | autore | modifica

# Come è fatto

ARI è composto da una parte HW e FW, il robot ARI. ARI è composto da una scheda Arduino ATMEGA e da uno shield ARI_V3 fatto da StuffCube stuffcube.wordpress.com. Lo shield porta il controllo dei due motori, un ESP8266 per l'interfaccia col WiFi e funzioni accessori, l'interfaccia elettrica e i connettori verso i sensori ottici degli encoder e alle altre periferiche.

ci sono quindi due FW. Uno per l'ATMega e uno per l'ESP8266 (Wemmos mini D1). Questi si compilano e scaricano con l'ambiente Arduino. Una serie di librerie deve essere installata. elenco librerie ... da fare

Un software su pc è l'interfaccia con ARI. E' un server in python che offre una interfaccia web visualizzabile nel browser. richiede l'installazione di Python3 e di alcune librerie.

# Installazione Python

## Librerie Python

i comandi segunti valgono per Windows e Linux.

utility pip da shell di comando lanciare pip, se non risultasse installato fare

apt-get install python3_pip

### modulo Tkinter

il 3.6 va sostituito dalla versione di python installata sul proprio computer, per conoscerla lanciare python3 da riga di comando

apt-get install python3.6-tk

### modulo Sympy

pip3 install sympy

### modulo Numpy

pip3 install numpy

### modulo Cherrypy

pip3 install cherrypy

## Wifi setting

Se rete non è presente o non è stata ancora impostata il led blu sull’ESP lampeggia col periodo di un secondo (05 on, o5 off).
L’eSP si configura come access point con il nome ESP.. seguito dal suo numero di serie.

Questa rete è aperta, non è necessario user name e password. Una volta collegati avviate un browser che andrà automaticamente alla pagina di configurazione, nel caso non funzione andate all’indirizzo 192.168.4.1

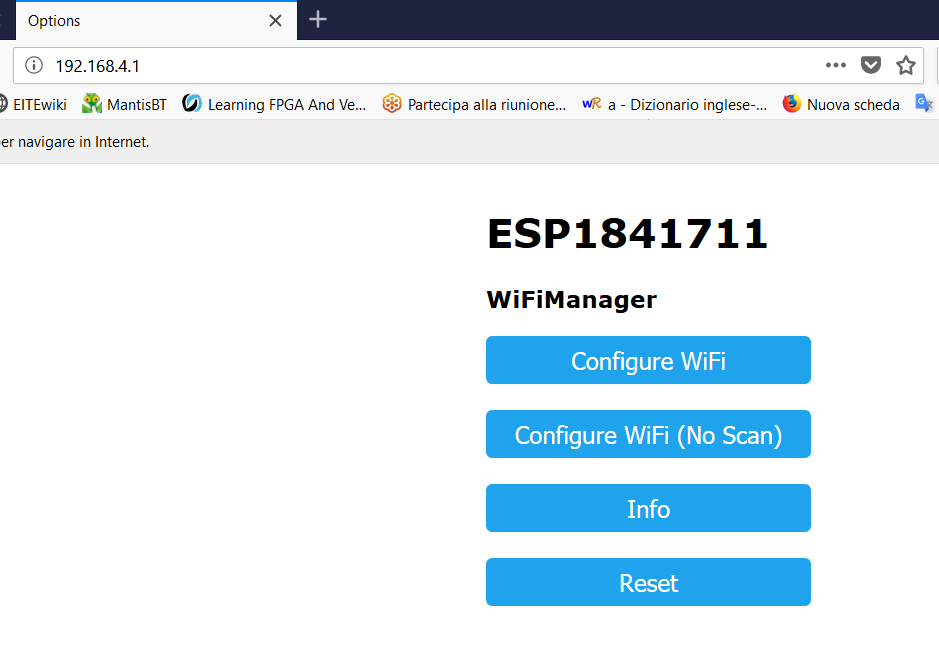
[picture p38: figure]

Scegliendo “Configure WiFi” si ottiene la lista delle reti, selezionatene una, inserite la password e fate Save. Al riavvio si connetterà alla rete scelta.

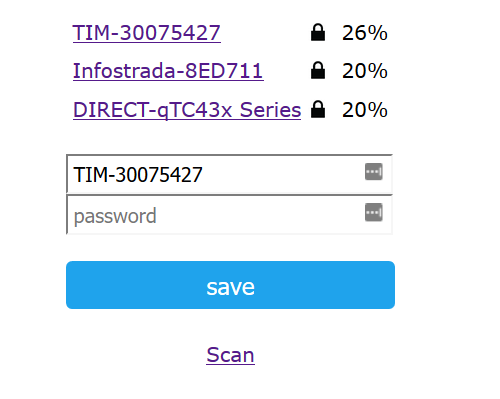
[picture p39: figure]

# Collegamento da pc

ARI_V3\01_pcSoftware\arianna_cli_socket2.0

Avviare Python e aprire il programma “arianna_clisocket.py”

Appare la CLI.

GUI: da browser inserire l’indirizzo http://127.0.0.1:8081/ui2

01_installazioneCollegamento.docx 1/2

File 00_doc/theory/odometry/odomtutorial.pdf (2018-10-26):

# A Primer on Odometry and Motor Control

Edwin Olson

December 4, 2004

### 1 Introduction

Most robotics problems ultimately reduce to the question: where am I? How can you go somewhere else without some notion of where you are now? You could proceed naively, stumbling around, hoping that your goal will appear in range of your robot’s sensors, but a better plan is to navigate. A basic method of navigation, used by virtually all robots, is odometry, using knowledge of your wheel’s motion to estimate your vehicle’s motion.
The goal of this primer is to show you how to use odometry data. A real dataset will be used extensively to show how well (and how badly) these ideas can work.
Suppose your robot starts at the origin, pointed down the xaxis. Its state is (x, y, θ) = (0, 0, 0). If the robot travels (roughly) straight for three seconds at 1 m/s, a good guess of your state will be (3, 0, 0). That’s the essence of odometry.
We’ll assume that the vehicle is differentially driven: it has a motor on the left side of the robot, and another motor on the right side. If both motors rotate forward, the robot goes (roughly) straight. If the right motor turns faster than the left motor, the robot will move left.
Our goal is to measure how fast our left and right motors are turning. From this, we can measure our velocity and rate of turn, and then integrate these quantities to obtain our position.

### 2 Derivation

The speeds of our motors give us two quantities: the rate at which the vehicle is turning, and the rate at which the vehicle is moving forward. All we have to do is integrate these two quantities, and we’ll have our robot’s state (x, y, θ).
That sounds a bit scary, but the mathematics end up being very simple. If we had analytic expressions for the angular rate and forward rate functions, their integral probably would be scary. But in a real system, our data comes from real sensors that are sampled periodically. Every few milliseconds, we get a new measurement of our motor velocities. We will numerically integrate our solution, which is of course, just a fancy way of saying that we’ll divide time up into little chunks and just add up all the little pieces.
Suppose our robot is at (x, y, θ). Depending on what kind of sensors we have, we might get measurements of how much the motors have rotated (in radians), or an estimate of how fast they’re rotating (angular rate, radians/sec.) We’ll consider the first case, but of course the second case can be handled by just multiplying the angular rate by the amount of time that has elapsed since our last iteration. Given the amount of rotation of the motor and the diameter of the wheel, we can compute the actual distance that the wheel has covered.

Suppose the left wheel has moved by a distance of dleft and the right wheel has moved dright. For some small period of time (such that dleft and dright are short), we can reasonably assume that the vehicle trajectory was an arc (see Fig. 1).

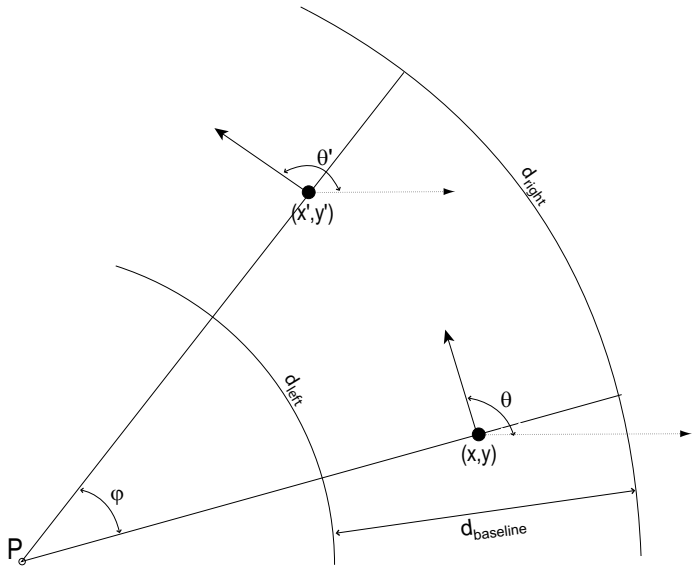
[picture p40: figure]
dright; dleft; dbaseline

Figure 1: Odometry geometry. Over a small time period, the robot’s motion can be approximated by an arc. The odometry problem is to solve for (x

, y

, θ
) given (x, y, θ) and
dbaseline. In the figure, the robot is moving counterclockwise.

The initial state (x, y, θ) defines our starting point, with θ representing the vehicle’s heading. After our vehicle has moved by dleft and dright, we want to compute the new position, (x

, y

, θ
).
The center of the robot (the spot immediately between the two wheels that define’s the robot’s location), travels along an arc as well. Remembering that arc length is equal to the radius times the inner angle, the length of this arc is:
dleft + dright dcenter = | (1) 2

Given basic geometry, we know that:

φrleft = dleft | (2)
φrright = dright | (3)

If dbaseline is the distance between the left and right wheels, we can write:

rleft + dbaseline = rright | (4)
Subtracting (2) from (3), we see:

φrright − φrleft = dright − dleft

φ(rright − rleft) = dright − dleft

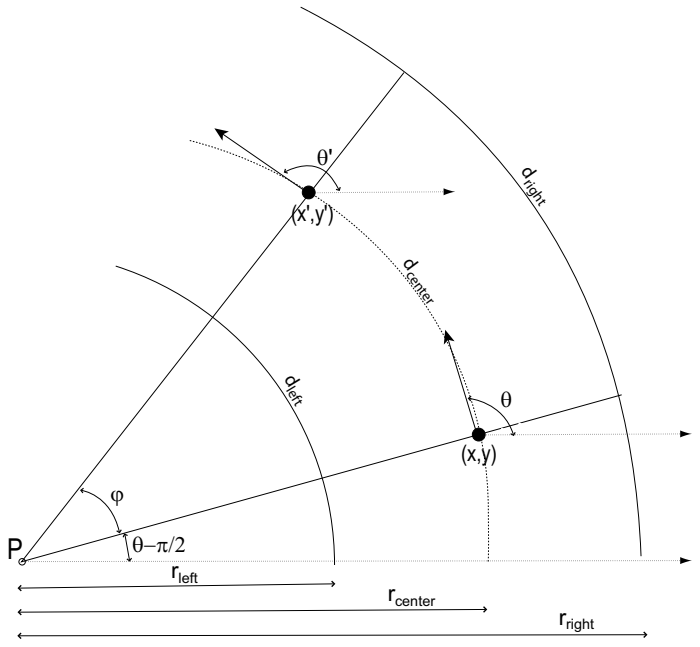
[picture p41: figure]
dright; d center; dleft; rleft; rcenter; rright

Figure 2: Detailed odometry geometry. We compute the center of the circle P by forcing dleft and dright to be two arcs with the same inner angle φ. From this, we can compute the new robot position (x

, y

, θ
).

φdbaseline = dright − dleft

dright − dleft φ = | (5) dbaseline

At the risk of making the math a bit uglier than really necessary, let’s very carefully compute the new robot state. All of our arcs have a common origin at point P. Note that the angle of the robot’s baseline with respect to the x axis is θ − π/2. We now compute the coordinates of P:

Px = x − rcentercos(θ − π/2) = x − rcentersin(θ)
Py = y − rcentersin(θ − π/2) = y + rcentercos(θ)

Now we can compute x and y :

x = Px + rcentercos(φ + θ − π/2)
= x − rcentersin(θ) + rcenter ∗ sin(φ + θ)
= x + rcenter[−sin(θ) + sin(φ)cos(θ) + sin(θ)cos(φ)] | (6)

and y = Py + rcentersin(φ + θ − π/2)
= y + rcentercos(θ) − rcentercos(φ + θ)
= y + rcenter[cos(θ) − cos(φ)cos(θ) + sin(θ)sin(φ)] | (7)

If φ is small (as is usually the case for small time steps), we can approximate sin(φ) = φ and cos(φ) = 1. This now gives us:

x = x + rcenter[−sin(θ) + φcos(θ) + sin(θ)]
= x + rcenterφcos(θ)
= x + dcentercos(θ) | (8)

and

y = y + rcenter[cos(θ) − cos(θ) + φsin(θ)]
= y + rcenter[φsin(θ)]
= y + dcentersin(θ) | (9)

In summary, our odometry equations for (x

, y

, θ
) reduce to:
dleft + dright dcenter | = | (10) 2
dright − dleft φ = | (11) dbaseline
θ | = θ + φ | (12)
x | = x + dcentercos(θ) | (13)
y | = y + dcentersin(θ) | (14)

### 3 Basic Motor Theory

Subsequent sections will discuss how we can measure the performance of our motors. We’ll need to put this into context by talking first about some basic motor physics.
Motors are devices which manipulate magnetic fields in order to convert electrical energy into rotational energy. An electric current flows through coils of wire, causing a magnetic field to form. This magnetic field interacts with permanent magnets (like those on your refrigerator), causing the shaft to rotate.
We also know that motors can be used in reverse; if you rotate the shaft of the motor, the permanent magnets induce a current in the rotating coils of wire. This, of course, is known as a generator.
It is important to realize that motors are always behaving as generators. If the output shaft is rotating, a current is being induced in the wires. Usually, this current opposes the current resulting from an externally applied voltage.

### 3.1 Motor model

A motor can be simply modelled by the resistance of its coil of wire and a voltage source that produces a voltage proportional to rotational speed (see Fig. 3). The “generator” voltage

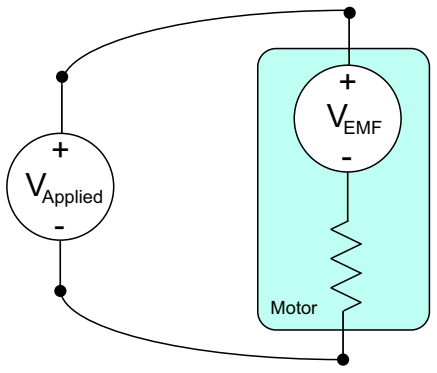
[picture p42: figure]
VEMF; VApplied; Motor

Figure 3: Simple motor model. The simplest motor model is a resistor (corresponding to the resistance of the motor’s wire coil), and a voltage source corresponding to the Back EMF.

is known as the Electro-Motive Force (EMF). It’s often called the “Back EMF”, since it’s the voltage coming back out of the motor.
When we interface with a motor, we typically control the voltage applied to the motor. This applied voltage can cause current to flow into the motor. At any given moment, Ohm’s law can be applied. However, the voltage that we have to consider isn’t the applied voltage, but the net voltage: Vapplied − Vemf . In other words, the current can be written:
I = (Vapplied − Vemf )/Rwinding | (15)
The current of a motor is extremely important: it is proportional to the torque. A motor only does work when its producing torque, and since torque is proportional to current, this only occurs when Vapplied = Vemf .
When a voltage is first applied to a motor, Vapplied − Vemf > 0, and so current will flow. This will produce torque and the output shaft will begin to rotate (provided the torque exceeds the static friction of the load.) As time goes on, the motor will slowly accelerate. As the motor gains speed, Vemf increases, and the current drops. At some point, we’ll reach an equilibrium, where the motor’s torque (and current) exactly matches the load.
Here’s an important thought experiment: suppose we take a motor and short the two leads together. Will it be easier or harder to turn the output shaft? If we turn the output shaft, the motor will act as a generator, producing a voltage of Vemf . But the applied voltage is zero, since the leads are shorted. All of the back EMF voltage is applied across the motor winding, inducing a current. This current will generate a torque that will oppose the external torque. Setting both terminals of a motor to the same voltage brakes the motor, without the need for any mechanical mechanism.

### 3.2 Applied Voltage and PWM

As we’ve seen, the applied voltage is intimately involved in the behavior of a motor. Special circuitry is required to drive motors; a typical microcontroller can only provide a very small amount of power on each of its outputs– far too little to power a motor. We’ll need some additional circuitry to drive the motors.
It turns out that building a circuit that can output an arbitrary applied voltage at high current is quite difficult. It is much easier to build a simple high current switch, whose output is either Vmax or zero. In fact, we can build a switch that can change state very fast, upwards of 100kHz.

period

50%

20%

80%

Suppose you’re trying to build a dimmable light switch; can you build one from just an onoff switch? Suppose you start flipping the light on and off repeatedly, at first fairly slowly. The room is bright, then dark, then bright again. Not a very good dimmer! But you can probably imagine that if you could flip the switch fast enough, that you could achieve intermediate brightness levels. This is what we’re going to do with motors.
If the switch is “on” 50% of the time, you might expect the motor to run about the same as it does at 50% the voltage. This does, in fact, work... provided that the switching is fast enough. The criteria for the switching rate is that the voltage has to change faster than the motor can react; the motor has an “electrical time constant”, which reflects how rapidly it can react to changing electrical conditions.

Figure 4: PWM Waveforms. We can approximate different applied voltages by using a pulsewidthmodulated signal whose period is less than the motor’s electrical time constant.

This technique is called Pulse Width Modulation (PWM) (see Fig. 4), since the width of each pulse is modulated in order to approximate different values of Vapplied.
In general, motor electrical time constants are on the order of a few milliseconds, but PWM frequencies in the ¡20kHz range can cause audible vibrations. So often, PWM frequencies are increased well above the human range of hearing.

### 3.3 Deficiencies of our model

This is a pretty good model for a motor, but it ignores one often important detail: electrical transients. When the motor is in steady state (i.e., it’s been rotating under a uniform load for a long time), our model is accurate. But when conditions are changing (the load is changing, or the applied voltage is changing), the model can be pretty lousy.
The main issue we’ve overlooked is the transient behavior of the motor. Not only is the coil of wire an electromagnet, it’s also an inductor. Recall that the voltage across an inductor with inductance L is:
dI V = L | (16) dt

If the current is changing quickly, the inductor can develop a very large voltage! Many motor controllers support a controllable “slew rate”; this is a way of limiting the rate at which the applied voltage changes (and hopefully the current as well!) Large voltage transients are not good for circuits, and large motors can develope enormous transients on the order of tens or hundreds of volts.

### 3.4 Summary

We’ll continue to use our simple model for the rest of this article. Here’s what you need to remember:

- The Back EMF of a motor (Vemf ) is proportional to the speed of the motor.

Break-beam sensor

Clockwise rotation:

Counter-Clockwise rotation:

4

- Motor current is proportional to torque.
- We drive motors with PWM, which allows us to approximately control Vapplied.

### Deadreckoning Sensors

In order to build an odometry system, you must have a way of measuring the angular velocity of the motor. This can be accomplished in a number of ways:
- Mono Phase Encoders. A sensor is placed on the motor shaft or wheel such that when the shaft rotates, the circuitry generates alternating 1’s and 0’s. One way of implementing a simple encoder is by attaching a disc with holes to the shaft, and using a breakbeam sensor to detect when a hole passes by. A mono phase encoder can not determine the direction of motion. A serious failure mode occurs when the motor is essentially stationary with a hole halfway in front of the sensor: environmental noise can cause the encoder to trigger and untrigger, making it appear as though the shaft is rotating.

Figure 5: Simple Encoder. As a perforated disk rotates, a breakbeam sensor alternates between 1 and 0. The direction of motion is ambiguous.

- Quadrature Phase Encoders. An improvement upon mono phase encoders, quadrature phase encoders use two simple encoders arranged so that they produce waveforms 90 degrees outofphase. When the shaft rotates in one direction, signal A will “lead” signal B; when rotating in the opposite direction, signal “B” will “lead” signal A. Quadrature phase encoders are generally considered the most precise form of motor feedback, and can be quite expensive. A simple state machine can decode the quadrature phase signals into “up” and “down” pulses. The two outofphase signals provide immunity from spurious transitions due to a hole being halfway in front of one of the sensors: only one signal can be transitioning at any given time, and if this signal jumps back and forth, it maps to alternating (and cancelling) forward and backward motion.
- Tachometer. A tachometer is essentially a small motor attached to the output shaft of the main motor. It operates as a generator, where the output voltage is proportional to the angular velocity of the main motor.
- Direct Back EMF measurement. With a little extra circuitry, we can measure the back EMF of a motor directly. We set Vapplied = 0, wait for the electrical transients to die off, and then measure the voltage produced by the motor. Since we’re not applying any power to the motor, the motor will tend to slow down while we’re performing the measurement. Fortunately, it doesn’t take long for electrical transients to die off; we can measure the back EMF quickly, and then restore power.

5

Break-beam sensors
(90 degrees offset)

Clockwise rotation:

Counter-Clockwise rotation:

a

b

a

a

b

b

Figure 6: Quadrature Phase Encoder. Two simple encoders, arranged so that they pick up the same perforated holes, but 90 degrees out of phase with each other, allow the direction of rotation to be determined.

- Indirect Back EMF estimation via current sense. We can measure the amount of current flowing through the motor by putting a smallvalued resistor in the path between the motor and ground. Ohm’s law tells us that the voltage across that resistor will be proportional to the current.
If we know the motor current, the applied voltage (which we’re controlling), and the resistance of the motor winding, we can estimate the back EMF. Solving Eqn 15 for

Vemf

Vemf = Vapplied − IRwinding | (17)
- Gyro heading adjustment. Some vehicles have a gyroscope, which can provide an estimate of the vehicle’s angular rate dθ/dt. Gyros drift over time, but can be quite accurate over small periods of time. They can be used to improve dead reckoning accuracy, particularly when a poor motor feedback sensor is used (e.g., back EMF.)

### Odometry in Practice

Odometry can provide good deadreckoning over short distances, but error accumulates very rapidly. At every step, we inject error (noise) into not just x and y, but also θ. The error in θ is the killer, since every error in θ will be amplified by future iterations.
There are a number of basic noise sources.
- Sensor error. If we’re using anything other than quadrature phase encoders for our feedback, then our estimates of the dleft and dright will be noisy.
- Slippage. When the robot turns a corner, one wheel will, in general, slip a little bit. This means that even if the odometry data was perfect, the robot’s path would not recoverable from it.
- Error in estimate of dbaseline or in wheel diameters. We must measure the baseline of the robot and the scale factor relating angular rate and linear velocity (a function of the wheel diameter.) Even small errors in these constants can cause problems– typically, the odometry result will have a consistent veer in one direction or the other. In fact, often the wheels on the robot are slightly different sizes. Even small differences lead to large navigation errors with time.

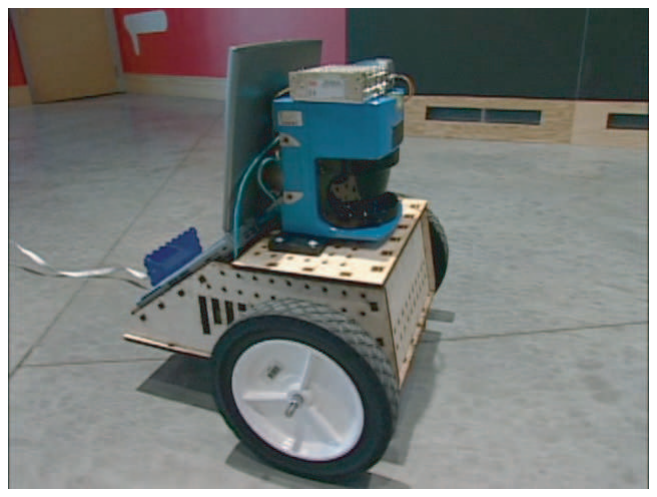
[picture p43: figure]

Figure 7: Splinter. This is the robot that collected the dataset. The vehicle, known as “Splinter”, has high quality quadrature phase encoders on each drive motor. A laptop on the back of the vehicle logged the data. The large blue device in the front of the vehicle is a laser range finder, not used in this article.

You should be itching to try out odometry now, and fortunately, there’s a dataset waiting for you! In this section, we’ll walk through a few examples in Matlab.
The dataset consists of 200 meters of odometry and gyro data from an experiment that lasted about 10 minutes. The vehicle that collected the data is shown in Fig. 7. The vehicle left the lab, travelled around a large open space in a clockwise (as viewed from the top) direction three times, then reversed direction and travelled around the same loop once in the opposite direction. Finally, it returned to lab.
A good odometry result is shown in Fig. 8. While the robot started and stopped in (approximately) the same space, notice how the odometry estimate is quite different at the beginning and end. A small error in θ causes all subsequent navigation to be rotated out of alignment.
The dataset is available from /mit/6.186/2005/doc/odomtutorial. Copy it into a directory and start matlab. The data is contained in a single array called “data”. Each row in the dataset is a set of observations made at a single point in time. A helper script, “setup.m” is provided which loads the dataset and sets up a few constants. These constants are TIME, LEFTTICKS, RIGHTTICKS, LEFTCURRENT, RIGHTCURRENT, LEFT-PWM, RIGHTPWM, and GYRO, and correspond to the column numbers in which data of different types is stored. To get started, type:

>> setup

Note that the odometry data is provided in units of ticks: the amount of forward (or backward) motion that occured since the last sample. Ticks are related to distance (and angular rate) by constant scale factors, which are characteristics of the robot’s geometry. We mentioned before that the baseline, the distance between the left and right wheels, is also a characteristic of the robot.
These measurements are made using a ruler, and are inexact. One of our tasks will be to find better values of the parameters.
Parameter | Value
baseline | 0.45 meters
metersPerTick | 0.000045 meters

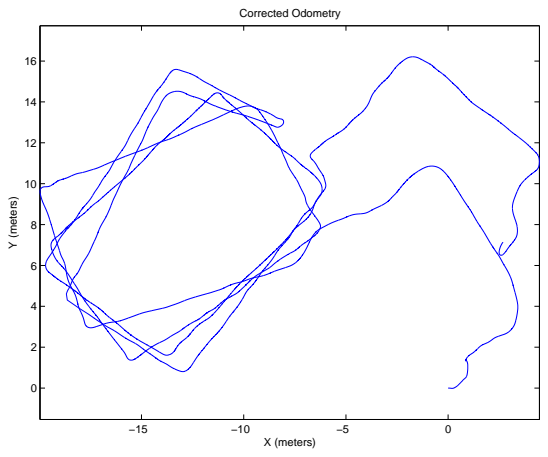
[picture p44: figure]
X (meters); Y (meters); Corrected Odometry

Figure 8: Good odometry result. This result was obtained by manually optimizing the rigid parameters of the vehicle until the path best resembled the actual trajectory. Note that the trajectory, in fact, started and ended at approximately the same position; even good odometry results can contain significant errors.

Problem 1. Examining the raw odometry data

Let’s get familiar with the data by plotting the left versus right wheel odometry ticks; we’ll be able to see how fast the left and right wheels are moving.

>> clf;
>> hold on;
>> plot(data(:,LEFTTICKS),’r’);
>> plot(data(:,RIGHTTICKS),’b’);

The command “clf” clears the figure, “hold on” allows multiple plots to be displayed on top of each other, and the two plot commands plot the vector of data in either red (’r’) or blue(’b’).
Compare the instantaneous velocity of the left and right wheels to the odometry results in Fig. 8. Identify in the velocity plot where the robot was turning.

Problem 2. Plotting the gyro data

Now let’s take a look at the gyro’s reported angular position over time. Plot the gyro data over time (the commands should look much like a previous example.) Your figure should look something like Fig. 9.
The shape of this graph is characteristic of a robot path which was mostly piecewiselinear; the robot goes straight for a while (the graph is horizontal), turns (the graph is vertical), then goes straight again.
Gyros tend to drift (a roughly uniform linear deviation over time.) We try to calibrate our gyros as carefully as we can so that the drift is small, but often our final data still contains drift. Look at the horizontal segments of the graph: they aren’t quite horizontal. Compute a better estimate of the gyro by finding a drift rate which makes the graph look more like Fig. 9.
You can do this with code like this:

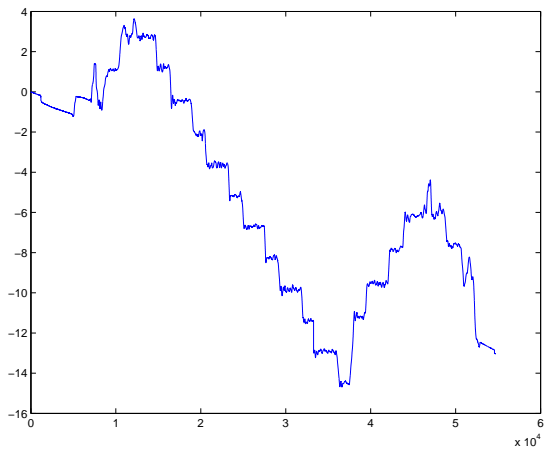
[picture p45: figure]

Figure 9: Adjusted gyro data. The robot traveled in straight line segments, punctuated by (roughly) 90 degree turns. This is readily evident from the gyro data.

>> gyro = unwrap(data(:,GYRO));
>> driftrate = <fill in this value>;
>> gyrocorrected = gyro + data(:,TIME)*driftrate;

Make sure you understand how this code works. Try it with and without the “unwrap” command. Obviously, you’ll need to experiment with different values of driftrate. Dealing with 2π wraparound is tricky, and many bugs can be introduced by neglecting it!
A fancy way of doing the calibration is to find some metric that “measures” the goodness of the drift rate. Suppose you assume that the starting orientation and end orientation were different by π/2; could you compute the correct drift rate from this?

Problem 3. Basic odometry

Your next task is to replicate the odometry result in Fig. 8. This is the most “key” problem in this whole tutorial, so don’t skip it!
Use the equations derived in this section to compute the change in θ at each time step. You can integrate this by using the cumsum command. You’ll now have a vector of the value of θ for every time step which you can use to compute the change in x and y. Using cumsum again, compute the actual x and y position. Plot the result.
Your first attempt will look like Fig. 10. These results are not terribly good, but that’s largely because the metersPerTick and baseline parameters were only estimates. Try to improve the odometry result by adjusting the parameters. Remember that metersPerTick might actually be different for the left and right wheel!
It may seem a bit tedious to optimize the parameters, and to a degree, it is. However, it is possible (and desirable) to develop an intuition for how the parameters affect the odometry result. You should be able to look at a result and say to yourself, “Hmm, I think the baseline distance is too short.”
When optimizing parameters by hand, we often use the shape of the robot path as our metric, mostly ignoring the scale. Can multiple sets of values for the baseline and metersPerTick result in the same path shape?
You should also be aware of overfitting. The more “knobs” we have to adjust the size and shape of our path, the more likely we are to be able to coax it into a shape we want–

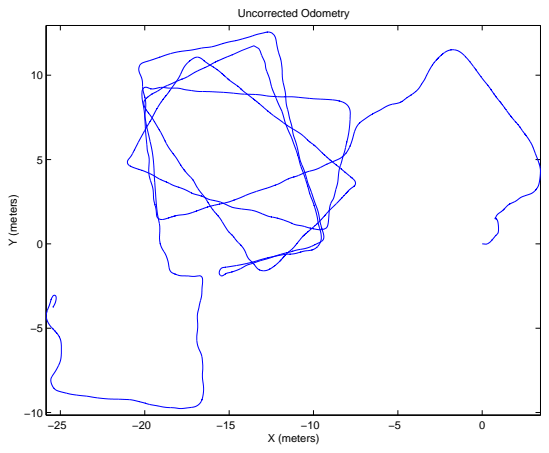
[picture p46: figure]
X (meters); Y (meters); Uncorrected Odometry

Figure 10: Uncorrected Odometry. Your first attempt at odometry should match this figure.

regardless of what the data actually tells us. Our goal is to get the best general purpose values of our parameters– ones that will be useful on future navigation missions, not get the absolute best result on a single, controlled (and perhaps contrived!) experiment. Remember that on any actual experimental run, it is much more likely that there was some error, than that there was no error.
Even with only three parameters (leftMetersPerTick, rightMetersPerTick, and baseline) it is quite possible to overfit, particularly when the dataset is relatively short. A general strategy for dealing with overfitting is to use crossvalidation: fit parameters to a subset of the data, and test it on a disjoint subset of the data. We can’t readily do that here, since we only have one relatively short dataset.

Problem 4. Gyroassisted odometry

Suppose your robot is a tricycle, with only the center wheel having an optical encoder. You no longer have dleft and dright– you only have dcenter. This means that you cannot compute changes in θ.
If you have a gyro, you could use the gyro’s estimate of heading instead! That is your challenge in this problem. Using the gyro data that you adjusted in Problem 1, recompute the odometry using only dcenter. Your graph should look similar to Fig. 11.
Is the path better or worse?
If you have dleft, dright, and gyro data, how could you fuse the two independent estimates of θ to get a better value of θ? If you’re interested in this, you should read about Kalman filters. I recommend Chapter 1 of Peter Maybeck’s book, “Stochastic Models, Estimation, and Control”; a PDF is available on the MASLab website.

Problem 5. Estimating velocity with back EMF

In the last problem, we assumed we didn’t have complete odometry data. Now we’re going to assume we don’t have any!
The dataset contains a log of the PWM values given to the motor controller, as well as the current consumption. A PWM value of -255 corresponds to about -12V, while +255 corresponds to +12V. The current consumption is given in amps, and the motor winding has a resistance of 3.5 Ohms.

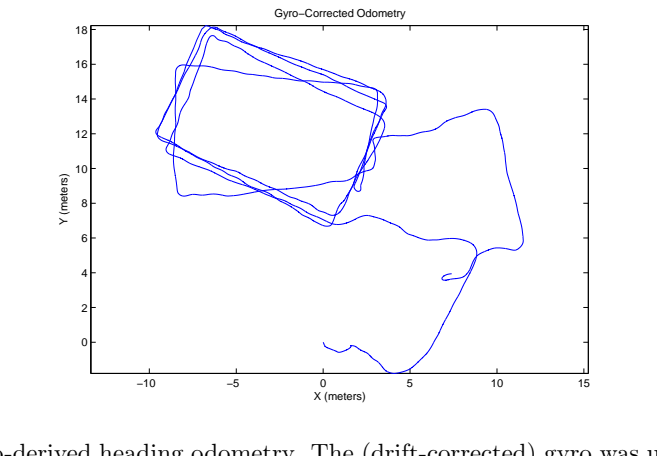
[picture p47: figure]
X (meters); Y (meters); Gyro−Corrected Odometry

Figure 11: Gyroderived heading odometry. The (driftcorrected) gyro was used exclusively for heading. You should replicate these results, and try to improve them further by fusing the odometryderived heading and the gyroderived heading.

Using Eqn. 17, estimate Vemf of the motor from these parameters. We know that Vemf is proportional to angular velocity, but what is the scale factor? We could look it up on the motor’s datasheet, but it’s probably not terribly accurate anyway.
Let’s consider a single wheel. We have it’s Vemf and its actual velocity as measured by the quadrature phase encoders. To estimate velocity, you’ll need to consider the amount of time that elapsed during every time step. You can compute this using:

>> dtime = [ 0; diff(data(:,TIME))]

One of the irritating things about working with real systems is that data doesn’t always cooperate. It’s entirely possible (in fact, likely) that you may encounter intervals in which zero time elapsed. When you compute the velocity during this interval, you must be careful to avoid a dividebyzero! A good way of dealing with this is to estimate the velocity by looking at a window spanning several time samples. This can also serve to filter out some of the noise!
We know that Vemf and velocity should be proportional to each other. Time for an upsetting fact: there’s probably some nonlinear offset as well. In other words, let’s model the system as:
velocity = x1 ∗ Vemf + x2 | (18)
We want to solve for x1 and x2, and we know the other two quantities.
This is (hopefully) true at every timestep, so let’s write this in matrix form. Let B be the matrix of actual velocities, and let A be a matrix with Vemf in the first column and 1s in the second column (in matlabeese, this is A=[vemf ones(size(vemf))]). We can then write:
Ax = B | (19)
This of course is the most basic of all Linear Algebra problems. Remember that this system is hugely overdetermined: we have thousands of simultaneous equations, and only two unknown variables. This is a good opportunity to compute a leastsquares fit. (For a reminder of the mathematics, see Strang’s 18.06 textbook, “Introduction to Linear Algebra”.)

x = (AT A)

−1AT B | (20)

We can now estimate the velocity of the motor using our coefficients x1 and x2, and compare it to our measured values using odometry. For the left wheel, you should get a graph like that in Fig. 17.

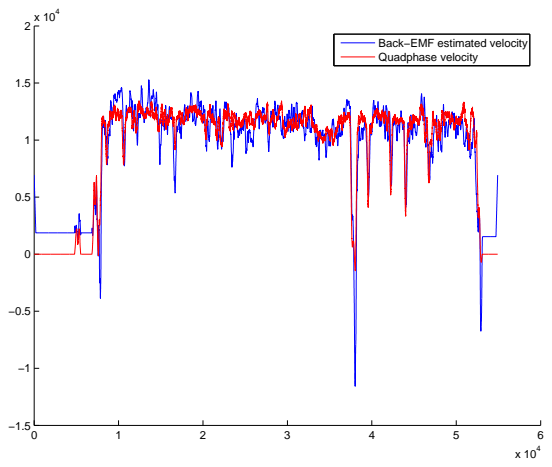
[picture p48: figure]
Back−EMF estimated velocity Quadphase velocity

Figure 12: Estimating velocity from Current Sense. Using Eqn. 17, we can estimate backemf (and thus velocity) using the motor’s current and applied voltage.

Now let’s put it all together. Estimate the velocity for the left and right wheels, and compute a trajectory without using the quadrature phase data (except for calibrating your models.)
How does it look? When does it perform well/poorly? How does it look if you use the gyro data for your θ estimate? You should be able to achieve something like Fig. 13. Keep in mind that this approach doesn’t require any optical encoders at all!

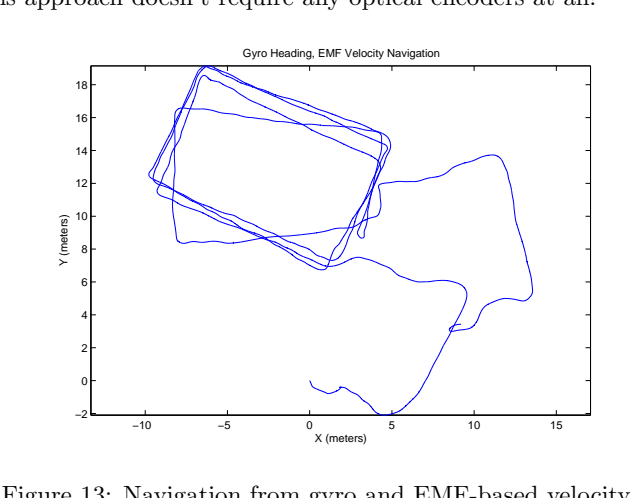
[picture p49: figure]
X (meters); Y (meters); Gyro Heading, EMF Velocity Navigation

Figure 13: Navigation from gyro and EMF-based velocity.

### 6 Conclusion

You now have a pretty good idea about what odometry is, what it can do, and what it can’t. In Maslab, you won’t have optical encoders as good as those used in this problem. But you will have a gyro, current sense, and the ability to build your own quadrature phase optical encoders.
What approaches do you think will work? Is there some other way of navigating? Maslab robots have cameras. If you pick out a feature and follow it around, can you use that to compute changes in robot orientation? If you find a feature of known size, can you estimate how far away you are?
You can purchase other sensors too– perhaps an electronic compass. Inexpensive electronic compasses might be low resolution, but they won’t drift like a gyro. Can an electronic compass plus a gyro be a powerful navigation aid?

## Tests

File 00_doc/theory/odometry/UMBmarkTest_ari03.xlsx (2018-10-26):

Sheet: test2
compensazione errori sitematici con test quadrilatero bidirezionale |  |  |  |  |  |  |  | 2017-08-14
UMBmark —
A Method for Measuring, Comparing, and Correcting
Dead-reckoning Errors in Mobile Robots |  |  |  |  |  |  |  | diametri ai valori nominali: |  |  | 2.7280
 | L | 2 | m |  |  |  |  |  |  | baseline attuale |  | 0.138
risultati test
test cw | x fisico | y fisico | x arianna | y arianna |  | ex | ey | r |  |  |  | su x | su y
1 | 1.49 | -1.15 | 0.0023 | -0.047 | -4.82 | 1.4877 | -1.103 | 1.852 |  |  | beta | 0.1193479167 | -0.4009625
2 | 1.57 | -0.9 | -0.01 | -0.034 | -4.75 | 1.58 | -0.866 | 1.802 |  |  | R | 16.76767842 | -5.02156852
3 | 1.61 | -0.99 | 0.039 | -0.016 | -4.7 | 1.571 | -0.974 | 1.848 |  |  | Ed | 1.008264127 | 0.9728910436 | 1.131 | Ddx | 1.126345867 | 1.146540762
4 | 1.66 | -1.18 | 0.056 | -0.02 | -4.8 | 1.604 | -1.16 | 1.979 |  |  |  |  |  | 1.131 | Dsx | 1.135654133 | 1.115459238
5 | 1.75 | -1.13 | 0.032 | -0.04 | -4.64 | 1.718 | -1.09 | 2.035 |  |  |  |  |  | 69.46794956 |  | 69.46794956 | 2.728
 |  |  |  |  |  | 0 | 0 | 2.035 | rcw max |  | alfa | -0.1193479167 | 0.4009625
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

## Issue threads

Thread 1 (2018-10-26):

arresto su ostacolo troppo lento

giorgio323323, 2018-10-26:
il lidar misura la distanza continuamente. Un test comanda l'arresto quando la distanza è minore di 50 cm.
1) il sistema funziona male. il robot si arresta troppo tardi
2) la distanza va messa come parametro e forse salvato in eeprom

giorgio323323, 2018-11-25:
risolto con lettura di ogni frame. Aggiunto anche sensore IR anteriore

Closed 2018-11-25.

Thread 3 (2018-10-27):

allarme ARI bloccata

giorgio323323, 2018-10-27:
Allarme ARI bloccata se velocità = zero e tensione comandata ai motori != 0
dovrebbe muoversi ma è ferma.

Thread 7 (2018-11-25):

sensore IR anteriore soffre di interferenze.

giorgio323323, 2018-11-25:

giorgio323323, 2019-01-03:
Il sensore Vl53 non ha interferenze col mifi-TF. Inoltre riporta la distanza in modo continuo. Il precedente viene abbandonato.

Closed 2019-01-03.

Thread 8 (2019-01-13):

comandi i1

aleairaghi, 2019-01-13:
attivare solo su movimento

giorgio323323, 2019-01-23:
20gen19 3.05.7
		la registrazione, una volta attivata, parte quando R diventa diverso da zero.
		Cioe quando ARI inizia a muoversi

Closed 2019-01-23.

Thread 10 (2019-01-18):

arianna udp presentazione

aleairaghi, 2019-01-18:
facciamo una procedura di salvataggio nome in eeprom  e poi quando mandiamo i pacchetti udp ci presentiamo con il nome (possiamo controllare piu arianna o capire a chi ci colleghiamo

Closed 2019-01-22.

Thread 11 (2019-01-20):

proposta personalizzazione arianna presentazione....con wifimanagerparametr la cosa è veloce e semplice

aleairaghi, 2019-01-20:
*********************************************
char* 		ssid;
char* 		password;
char* nomeari;
char* portAri;

*************************************************************
omissis
************************************************************
void configModeCallback (WiFiManager *myWiFiManager) {
	//Serial.println("Entered config mode");
	//Serial.println(WiFi.softAPIP());
	//if you used auto generated SSID, print it
	//Serial.println(myWiFiManager->getConfigPortalSSID());

	//entered config mode, make led toggle faster
	ticker.attach(0.2, tick);
}

WiFiManagerParameter custom_nome("nome", "nome arianna", nomeari, 10);
WiFiManagerParameter custom_porta("porta", "porta udp 8888", portAri, 4);

void setup()
{
***********************omissis****************************************************
	WiFiManager wifiManager;
	wifiManager.addParameter(&custom_nome);
	wifiManager.addParameter(&custom_porta);
	//reset settings - for testing
*******************************omissis**************************************************
void loop() {
	//uint8_t i;
	//check if there are any new clients
	if (server.hasClient()){
		if (!serverClient || !serverClient.connected()){
			serverClient = server.available();

			if (verbose) Serial.println("New client");

		}
	}
	if (!serverClient.connected()) {
		delay(500);
		//Serial.println("connessione chiusa");
		  IPAddress broadcastIp = WiFi.localIP();
		// se non ci sono client connessi
		// invia nome sulla rete per essere trovato
		broadcastIp[3] = 255;

		if (verbose)	Serial.println(WiFi.localIP());
		String tempprt=String(custom_porta.getValue());
		udpport=tempprt.toInt();
		UDP.beginPacket(broadcastIp, udpport);
		UDP.print(String(custom_nome.getValue()));
*********************************************omissis***************************************

Closed 2019-01-22.

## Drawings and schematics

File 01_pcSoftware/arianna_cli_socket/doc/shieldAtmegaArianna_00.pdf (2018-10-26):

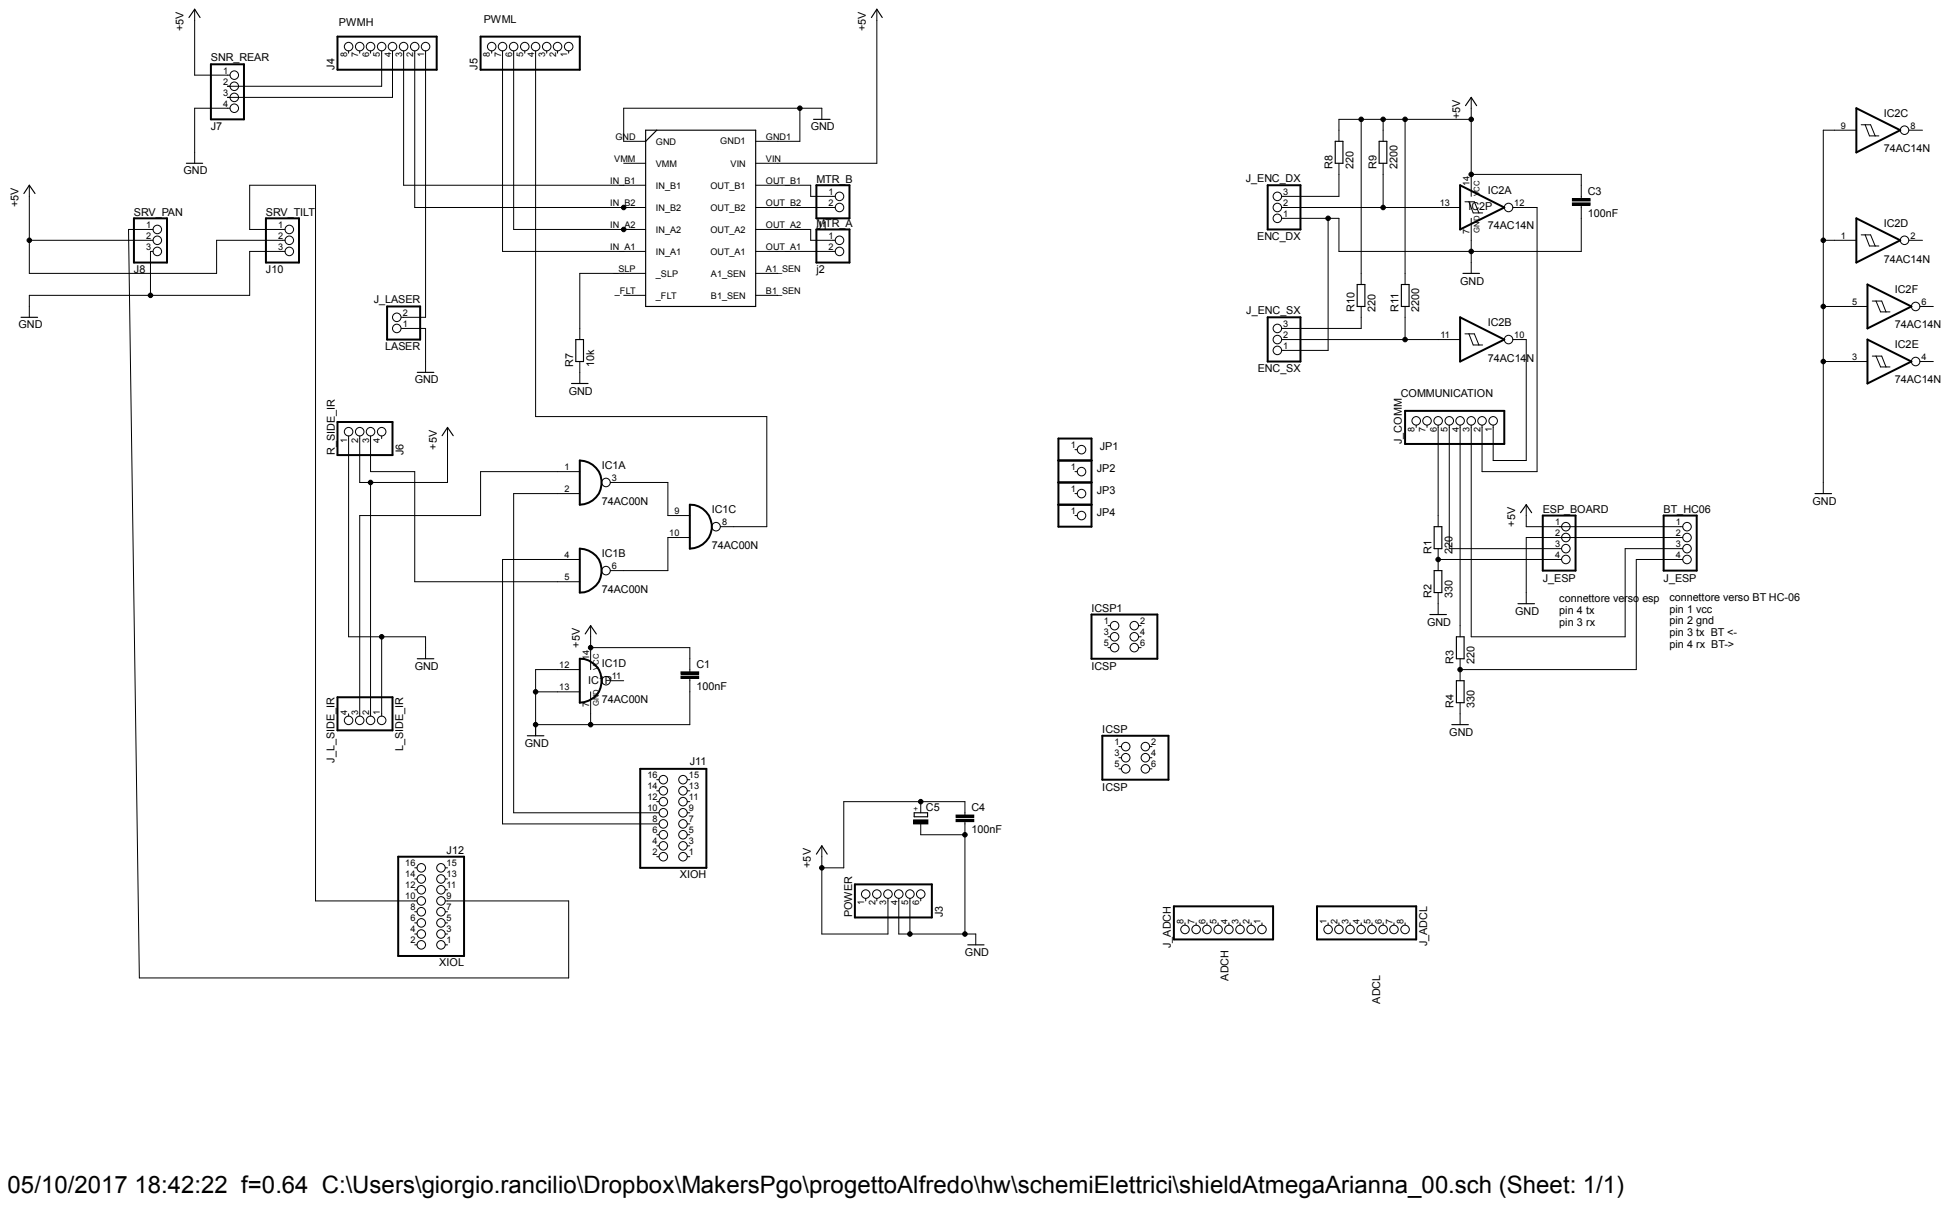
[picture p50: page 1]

J_ESP
connettore verso BT HC-06
pin 1 vcc
pin 2 gnd
pin 3 tx BT <-
pin 4 rx BT->

05/10/2017 18:42:22 f=0.64 C:\Users\giorgio.rancilio\Dropbox\MakersPgo\progettoAlfredo\hw\schemiElettrici\shieldAtmegaArianna_00.sch (Sheet: 1/1)

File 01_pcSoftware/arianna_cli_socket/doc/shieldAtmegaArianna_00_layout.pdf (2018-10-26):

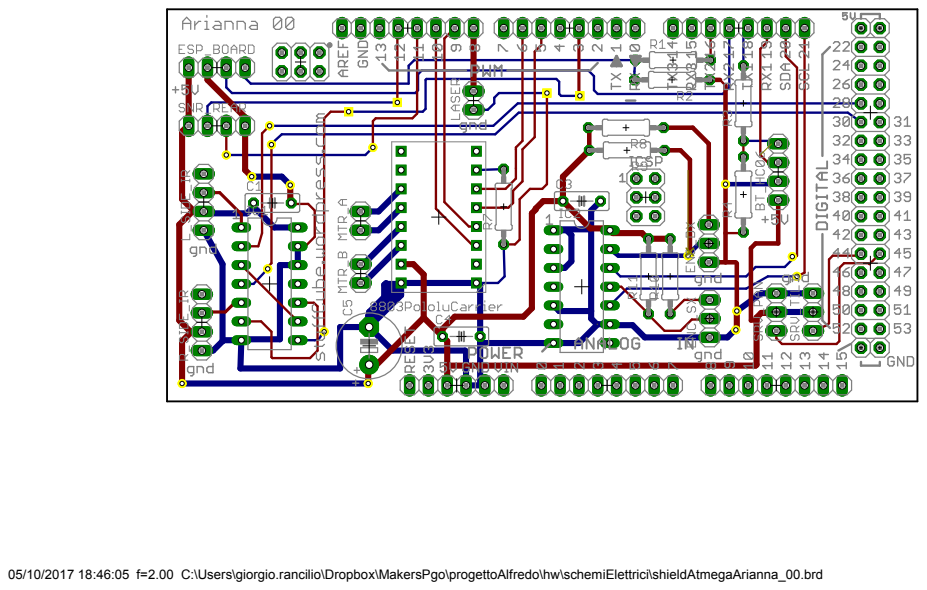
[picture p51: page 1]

05/10/2017 18:46:05 f=2.00 C:\Users\giorgio.rancilio\Dropbox\MakersPgo\progettoAlfredo\hw\schemiElettrici\shieldAtmegaArianna_00.brd

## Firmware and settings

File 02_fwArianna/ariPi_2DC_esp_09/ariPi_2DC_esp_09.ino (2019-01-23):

#define V_FW_ATMEGA  "3.05.08"
/**@file ariPi_2DC_esp_08.ino */
/* stuffcube.wordpress.com

	23gen19 3.05.8
	su blocco per ostacolo azzerare distanza residua #9, 
	soluzione: distanza = odometro 

	20gen19 3.05.7
		la registrazione, una volta attivata, parte quando R diventa diverso da zero.
		Cioe quando ARI inizia a muoversi

	13gen19 3.05.6
		introdotto regolatore PI anche su modo R6
		introdotto terminatore su risposta registratore

	06gen19 3.05.5
		inserito offset su PAN, F5. Salvato in E2prom
		test OscilloSscope
		motorSpeedRef =  108; //MODERATA; troppo veloce eccede. 
		se tropo pesante non si muove........
		modificata temporizzazione task.
			la base è la rampa a 10 ms che incrementa cnt10ms
			ogni volta che arriva a TEMPO_CONTROLLO viene eseguito

		03gen19 3.05.4
		errato separatore, corretto. String(inputString.substring(2)) +";"+\

    03gen19 3.05.03
		corretto baco su divLidar
		// preparata aggiunta lidarDistance alla risposta 'p'
		rimossa E4 e E5 (set dei parametri predefinito)

    27dic18 3.05.02
		valore default KpTeta da 0.8 a 8
		baco: caricava KpTeta con valore di default in firstRun
		rimossa risposta "mis:"
		rimosso cmd 'B', il sensore ostacolo si autodetecta
		aggiornata stringa di risposta a comando 'p'
		campo ID msg 'p' in posizione 2

	24dic18 3.05.00
		aggiunto vl53 per la gestione ostacoli, ritorna ost come segnale  per non creare confusione con lidar, aggiunto parametro lidar

	09dic18  3.04.01
		gestione lidar con ritorno in mm divido il valore per 10
		aggiunto divisore divLidar come parametro in E2prom per vecchi lidar
		modificati valori di default per meccanica corrente
		corretto errore in load default
		caricando questa versione la prima volta vanno ripristinati i valori meccanici

	01dic18 3.04.00
		sensore ostacolo anteriore off alla partenza. va abilitato per usarlo
		aggiunta V_FW_ATMEGA
		formato M.mm.sb
		M: il cambio richiede modifiche hw. Aggiungere un sensore (es sensore frontale) non è una modifica hw, è una opzione
		mm: aggiunta di una funzione, le versioni precedenti non la supportano. es la gestione del sensore frontale.
		sb: subversion. si migliorano funzioni o corregono bachi. nulla viene aggiunto.

		richiesta "h" versione V_FW_ATMEGA
		printDatiCalibrazione dava errore per risposta troppo lunga

	25nov18 definiti LED1..3
		attivato led1 insieme a LedPuntatore

	11Nov18
		gestione sensore ostacolo frontale
		comando B per abilitarlo B0 off, B1 On
		nota che il Lidar si sente sull'IR. Se tolgo lidar dall'asse
		non interferisce.


	01Nov18 
		rivisto lidar. Introdotta guida a distanza dalla parete. Modo R1 e R2. Parametro 'O' distRef.
		nellla stringa "pos:..." aggiunto in coda "statoRun". Questo permette di coordinare il sw su pc.
		introdotti parametri per guadagni regolatori vari

  08ott18
    lidardist da float a int, Piccola modifica in testOstacoli()

  04set18
  //    delay(25); rimosso in lidar() insieme a 3 assegnamenti

  07ago18
  revisione 3.0
  rimosso sonar
  rimosso BT
  rimossa gestione comandi BT
  sensori di distanza IR: tolto interrupt per misura lineare, inserito stato ON/Off
  FILE_PATTERNS = [...] *.ino
  EXTENSION_MAPPING = ino=c doxygen config filebuf

  da ora i commenti più recenti sono in alto
  intestazioni routine per doxygen
/ * *

     @brief  Gets the most recent sensor values and transform in angle.
            This function reads only x and y magnetometer values
            The coefficients for correction are applied.

      the output is tetaCompass which is a global variable.

    @param  a .....
    @return b ....


 * /

/// Brief description.
https://learn.adafruit.com/the-well-automated-arduino-library/doxygen-tips
http://www.stack.nl/~dimitri/doxygen/manual/markdown.html






----------------------------------------------------------------------------

note : 30lug16
fare un doppio movimento per la posizione
il primo fa in grosso e nel caso eccede.
il secondo si posiziona fine.
la macchina a stati è già pronta

giocare con baseline per la giusta larghezza

R5 si ferma troppo avanti, l'angolo che trova è sbagliato
devo dare due R5 per farlo andare


testare con modifica VA_zero attiva, nei test precedenti non lo era
testare modo R5 che gira su una ruota.


sistemata cablatura:
motore DX morsetti A - per il piu e meno fare foto
motore SX morsetti B
IR DX a ingDX
IR SX a ingSX
Encoder SX a ing SX
Encoder DX a ing DX

parametri taratura salvati e recuperati da E2prom
talvolta perde dei dati (giroRuota). Confusione con aggancio BT ??
messo comando f per leggere distanza degli IR
R5 e R6 girano ma non danno risultati ripetibili
m sonar rivedere





aggiustare le dirVx = 0 gestite in odometro


*/
/*
 * arianna
 * giorgio323@gmail.com
 * infostuffcube@gmail.com
 *
 * 16nov16  inizio

  test su sensore ir
  l'idea è trovare il tempo a 1 rispetto al tempo totale
  questo è un indicatore della distanza

  10dic16 sensore rotazione motore (odometro)
      spostato su Raspberry la compilazione
      ID_000  digitalPinToInterrupt(SIDE_IR_PIN) non dichiarato

  27dic16 comandi da seriale
      gestione arrivo in posizione
      aggiunto sonar montato su servo

      per trovare la direzione da puntare cerco il punto a distanza minima
      con un algoritmo di bisezione
      faccio con uno script esterno

  02gen17 penso a gestire sensore dx e sx
  numbers 0 (on digital pin 2) and 1 (on digital pin 3)

  19gen17 differenziale elettronico
      tolgo ovfTimer perchè usato dai PWM
      gestire misura sensore senza interrupt timer

  28gen17 add blueTooth on serial port1
      vanno ignorati i vari messaggi da BT
      quando non è connesso
      code 0000
      http://wiki.seeedstudio.com/wiki/Bluetooth_Bee

  23mar17 ID_001 rimosso limite angolo teta

  14mag17 si aggiunge comunicazione con esp ID_002
      si usa la serial2 verso esp
      modifica protocollo Alessandro Airaghi

  21mag17 ripristinato BT in parallelo ID_003
      Ok

  07giu17 cambiati encoder
      # come indicatore inizio msg monitor
        aggiunto comado di home 'H', prende la posizione attuale come 0, 0, 0
      cambiato terminatore seriale, da println a print + \n ID_004
      nel controllo di teta porto -2 <= S <= 2  ID_005

  29lug17 macchina a stati e rampa su tetaRef Rr


  11ago17 comando H modificato (distanza, odometro, lastPosition = 0.0)
      introdotto statoRun 99. Questo indica una rampa in corso.
      precedentemente lo statoRun 0 era presente anche durante la rampa di fermata
      il 99 serve per eviatre di inserire un ritardo coi comandi seriali per attendere la fine rampa

      nella lettura encoder se tensione al motore zero non conto impulsi.
      serve per evitare che quando curva su una ruota ferma possano esserci movimenti

  22ago17 ariPi_2DC_esp_02.ino
      messo ordine su nomi e posizioni encoder motori etc
      sistemati segni delle reazioni
      questo per capire su cosa si agisce
      Lettura velocità angolare e lineare

  10set17 diventa _03
      salvo dati di taratura in eeprom  ID_006
      rivisti sensori IR left e dx
  20set17
      inserita richiesta p per avere posx posy e teta in una sola volta
  060tt17
    ale
    aggiunta richiesta q per scansione area circostante con sonar per mappa

  12dic2017
    rimossa parte di bt libero porta SerialBT per rilevatore laser
    pulizia generale codice esp su serial 3


  08nov17
      inizializzato 'i' in eeprom
      rimosso #include <TimerOne.h>


  03dic17
      ID_007
      porta4 per comunicazione con la scheda sensori IR per la ricerca della
      docking station
      un micro esegue il sw nel foleder IRrecvDemo_x.ino
      viene fatto un bridge tra comandi da seriale verso la porta 4
      al momento è bloccante

  sistemare i parametri in funzione di ed anche per ari02



  10feb18
    merge

  21feb18
    // ID_008 dimenticato un pezzo

  05mag18
    merge per ari06.
    Lidar,
    Esp con IR
    tolgo BlueTooth
    tolgo ponte verso scheda IR

  12giu18
    // ID_009
    aggiunto getione sensore compass, gyro etc
    liberate porte 20 e 21, I2C (SCL, SDAT)
    eliminati sensori dx e sx per avere liberi interrupt per encoder (erano sul pin 3)
    modificati pin interrupt encoder
    pin 21 ora su pin 2
    pin 20 ora su pin 3
  aggiunta richiesta bussola 'f'
  agginto comando selezione guida 'G' con odometro, bussola, fusione ..

    ID_010
  riportati comandi seriale mancanti su "comandi"
  aggiungta possibilita di indice ai parametri
  la prima cifra dopo la lettera seleziona sino a 10
  indici (Es dati taratura F0, F1, F2 ..
  Rimango compatibile con comandi precedenti
  Salvati coefficienti taratura bussola in EEprom


  liberia tfmini.h   https://github.com/opensensinglab/tfmini/tree/master/src


 * Simple test for the DRV8833 library.
 * The DRV8833 is a dual motor driver carrier made by Pololu.
 * You can find it here: https://www.pololu.com/product/2130


 */



#include <SPI.h>
#include <SD.h>
#include <Servo.h>
#include <TFMini.h>
#include <EEPROM.h>     // ID_006

// ID_009
#include <Wire.h>
#include <Adafruit_Sensor.h>
#include <Adafruit_LSM303_U.h>
#include <math.h>
#include "Adafruit_VL53L0X.h"
// \ID_009


//#define ARI2  1
#define ARI3  1

#define SCRIVI  0
#define LEGGI   1
#define DEFAULT 2

#define DUE_PI  6.28318

/* Assign a unique ID to this sensor at the same time */
Adafruit_LSM303_Mag_Unified mag = Adafruit_LSM303_Mag_Unified(12345); //ID_009

Servo servoPan;       	// create servo object to control a servo
Servo servoTilt;        // create servo object to control a servo


//********** ID_002
#define ESPserial   Serial2
#define TFserial  Serial1   // LaserRadar

//creo tfmini
TFMini  tfmini;

String  inputString     	= "";
String  inputStringTmp    	= "";
int   	okcomm        		= 0;
static  String risposta;
char  	port        		= 0;

//**********fine ID_002

// dc motor
#include <DRV8833.h>

// Create an instance of the DRV8833:
DRV8833 driver = DRV8833();

//creo istanza vl530l0x
Adafruit_VL53L0X lox = Adafruit_VL53L0X();

// Pin numbers. Replace with your own!
// Attach the Arduino's pin numbers below to the
// Ain1 and Ain2 DRV8833 pins.
// N.B. la libreria sembra non gestire i pin 44-46 (timer diverso)
const int MTR_A_DX_P1   = 5;  /*!< output pin 1 for right motor */
const int MTR_A_DX_P2   = 6;  /*!< output pin 2 for right motor */
const int MTR_B_SX_P1   = 9;  /*!< output pin 1 for left motor */
const int MTR_B_SX_P2   = 10; /*!< output pin 2 for left motor */


#define nOfSamples	100
float ch1[nOfSamples]; 
float ch2[nOfSamples]; 
float ch3[nOfSamples]; 
float ch4[nOfSamples]; 

int sampleRate = 0;

int motorSpeedRef   = 0;
int direzione     	= 1;
int dirVA     		= 1;    // ID_005
int dirVB     		= 1;

int VB_zero     	= 0;
int VA_zero     	= 0;


#define SERVO_PAN_PIN     	45	///< Digital IO pin connected to the servo pin.
#define SERVO_TILT_PIN    	44  ///< Digital IO pin connected to the servo pin.

#define GIRO_DX_PIN     	3   ///< encoder  rotazione albero motore ID_009
#define GIRO_SX_PIN     	2   ///< encoder  rotazione albero motore ID_009

#define R_SIDE_FRONT    	29  ///< sensore frontale Dx      Low = ostacolo
#define L_SIDE_FRONT    	31  ///< sensore frontale Sx
#define ENB_R_SIDE_FRONT  	28  ///< abilita sensore frontale Dx. High = Enable
#define ENB_L_SIDE_FRONT  	30  ///< abilita frontale Sx
#define LED1        		34  ///< LED1
#define LED2        		33  ///< LED2
#define LED3        		32  ///< LED3




#define ledPin        		13  ///< led segnalazioni varie su Arduino
#define laserPin      		8   ///< porta puntatore laser

#define  TEST_MOTORE      	0  	///< modalità di test per fasi di debug
#define  TEST_STERZO      	1   ///< modalità di test per fasi di debug
#define  TEST_SENSORS     	2   ///< modalità di test per fasi di debug
#define  TEST_CONTROLLO   	3   ///< modalità di test per fasi di debug
#define  TEST_GIRO_SENSOR   4   ///< modalità di test per fasi di debug

long odometroCnt, odometroDxCnt, odometroSxCnt;     ///< contatori encoder

char firstRun;


#define TEMPO_CONTROLLO 	3   ///< tempo del controllo sterzo, posizione etc in 10ms


float ED      		= 1.0;    	///< definiscono la meccanica del robot. descrizione nella parte cinematica 
float ED_BASE     	= 1.0;    	///< definiscono la meccanica del robot. descrizione nella parte cinematica  
float BASELINE    	= 130.0;  	///< larghezza carreggiata in [mm]. descrizione nella parte cinematica  
float LAGHEZZA_A_MEZZI = 0.065; ///< larghezza meta' carreggiata in [m]. descrizione nella parte cinematica  

float GIRO_RUOTA_SX = 1.0;    	///< [mm per impulso*0.5]  sviluppo ruota[mm]/(2*ppr) (pulses per revolution)]. descrizione nella parte cinematica  
float GIRO_RUOTA_DX = 1.0;    	///< [mm per impulso*0.5]  sviluppo ruota[mm]/(2*ppr) (pulses per revolution)]. descrizione nella parte cinematica  
float GIRO_RUOTA  = 1.0;    	///< (GIRO_RUOTA_SX + GIRO_RUOTA_DX)/2. descrizione nella parte cinematica  

unsigned long MIN_TIME_TRA_PULSE = 9;     ///< tempo minimo tra impulsi encoder per evitare errate letture [ms]


#define E_POSIZIONAMENTO    10    ///< [mm], distanza dall'obbiettivo dove il robot si arresta
#define E_APPROCCIO     	300   ///< [mm], distanza dall'obbiettivo dove il robot inizia a rallentare

/*
  MODERATA    è il pwm di movimento normale
  APPROCCIO     durante l'avvicinamento alla poszione
  ACCELERAZIONE   nella fase del partenza
*/
#define FERMO     		0 		///< valore pwm di uscita durante stato di FERMO
#define MODERATA    	190     ///< valore pwm di uscita durante marcia MODERATA
#define APPROCCIO   	110     ///< valore pwm di uscita durante marcia APPROCCIO
#define ACCELERAZIONE 	160     ///< valore pwm di uscita durante fase accelerazione (non usato)
#define AVANTI      0
#define INDIETRO    1

#define MAX_STERZO  1.0       	///< massimo valore di sterzo. con 1 si ha una ruota ferma e l'altra al doppio della velocita'

// parametri lettura e/o scrittura
int   statoRun    	= 0;      	///< macchina a stati del movimento. Definisce anche il tipo controllo guida.
float   odometro    = 0;      	///< distanza percorsa in mm
float   distanza    = 0;      	///< distanza da percorrere col prossio Run
float   raggiorSterzo = 0.0;    ///< raggiorSterzo indica lo scorrimento che applichiamo alle ruote. vedi function differenziale
int     lidardist     = 0;      ///< [cm] distanza misurata dal Lidar
float   errore;

int   motorSpeed    = 0;
int   motorSpeedValue = MODERATA;
int   panAngle    	= 90;     	///< angolo destinazione del servo Pan
int   tiltAngle     = 90;   	///< angolo destinazione del servo Tilt
char  laser       	= 0;      	///< stato uscita puntatore laser
float kp_guida;  				///< guadagno proporzionale per controllo su distanza muro
float kd_guida;   				///< guadagno derivativo    per controllo su distanza muro

float kpTeta;      				///< guadagno proporzionale per controllo su teta
float kiTeta;     				///< guadagno integrale per controllo su teta

float posTarget;
float posRef ;
float step;
int counterArresto;
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
void loop() {

static long exeTime, tInit;


  mode = TEST_CONTROLLO;

  getCmd2();              /// gestione comunicazione con ESP
  rSeriale();             /// gestione comunicazione con ESP

  servoPan.write ( panAngle + offsetPan );     /// assegna angoli a pan e tilt
  servoTilt.write(tiltAngle);


  /**
    funzionamento corrente con anelli di controllo attivi
  */
    if (mode == TEST_CONTROLLO){

    if (firstRun){
      Serial.println("start TEST_CONTROLLO mode");
      Serial.println("controlloAttivo");
      raggiorSterzo = 0.0;
      servoPan.write( panAngle);
      servoTilt.write(tiltAngle);
      digitalWrite( ENB_L_SIDE_FRONT, HIGH);
      timeLidar=millis();
      firstRun = 0;
    }

    /*
      test e azione ostacoli frontali
    */

    testOstacoli();
    if (sensore_ost == 1) 	occlusoDavanti = vl53dist		< distOstacolo;
    else					occlusoDavanti = lidarDistance	< distOstacolo;
    

        if (occlusoDavanti && (statoRun != 5) &&(statoRun != 6) &&(statoRun != 0))
        {
			//motorSpeedRef = FERMO;
			statoRun      	= 99;   // senza rampa
			motorSpeed    	= 0;    // annullo rampa
			motorSpeedRef   = 0;
			distanza 		= odometro;
			risposta    	= "ostacolo";
			sendAnswer2(port);
			if (sensore_ost==1){
				risposta = "ost;" + String(vl53dist);
			}
			else{
				risposta = "ost;" + String(lidarDistance);
			}
			sendAnswer2(port);
        }


    /** statoRun

      il movimento è gestito da una macchina a stati. Lo stato iniziale è fermo.


      0: fermo
      1: controllo sterzo da sensore dx e distanza automatico (non attivo)
      1: controllo sterzo da sensore sx e distanza automatico (non attivo)
      2: controllo distanza, sterzo da parametro
      4: controllo distanza, sterzo da parametro da tetaRef vs teta odometria
      5: rotazione sul posto con una ruota ferma
      6: rotazione sul posto con ruote controrotanti

      99: comando arresto
    */

      // parte a 30 ms
      if ( cnt10ms >= TEMPO_CONTROLLO){

		cnt10ms = 0;
		
        exeTime = micros() - tInit;
        //Serial.println(lidarDistance);
        tInit = micros();

        lidarDistance = tfmini.getDistance()/divLidar;

        updatePosition();
        // ID_009 bussola

        if (bussola) compass();

        if (modoGuida == 0) tetaMisura = teta;      // ID_001
        if (modoGuida == 1) tetaMisura = tetaCompass; // ID_009
        if (modoGuida == 3) tetaMisura = tetaCompass; // ID_009
        if (modoGuida == 2) {
          tetaCompass = 0;
          modoGuida   = 1;
        }



        // controllo sterzo da lidar
        // R3: PAN  10 muro su lato DX
        // R1: PAN 170 muro su lato SX
        // kp usato 0.5
        // Se errore troppo alto andarci con S limitato
        if ((statoRun == 1)||(statoRun == 3)){

          errore = float(distRef - lidarDistance);
          // per come sono messi i motori inverto segno dell
          // deltaErrore
          deltaErrore = - errore + erroreK_1;
          erroreK_1   = errore;
          //tauD = 100e-3;
          //ts   = 25e-3
          //0.7788008 ktD  = exp(-ts/tauD)
          DerActive = DerActive*0.7788008 + kd_guida*deltaErrore*0.2211992;

          if (statoRun == 1) {
            raggiorSterzo =   kp_guida*errore  - DerActive;
          }
          else{
            raggiorSterzo =  -kp_guida*errore  + DerActive;
          }
          // errore +/- 0.5


          if (raggiorSterzo < -MAX_S) raggiorSterzo = -MAX_S;
          if (raggiorSterzo >  MAX_S) raggiorSterzo =  MAX_S;
        }

        if (statoRun == 2){
          motorSpeedRef = motorSpeedValue;
          direzione     = AVANTI;
        }

        // controllo sterzo da teta
        if (statoRun == 4){

          // regolatore PI

          errore = tetaRef - tetaMisura;
          raggiorSterzo =   kpTeta*errore;
          i_part += raggiorSterzo*kiTeta;

          // anti windup
          // limito la parte integrale se la parte proporzionale è già alta
          // questo evita di accumulare errore da scaricare
          // se la somma di parte P e I supera il massimo, la parte integrale viene
          // limitata a MAX - parte P
          if  ((raggiorSterzo + i_part) >  MAX_STERZO){
            i_part = MAX_STERZO - raggiorSterzo;
            if (i_part < 0) i_part = 0;
          }
          if  ((raggiorSterzo + i_part) < -MAX_STERZO){
            i_part = -MAX_STERZO - raggiorSterzo; // -2 - (-1) = -1, -2 -(-3) = 1
            if (i_part > 0) i_part = 0;
          }
          if (i_part>  0.5) i_part =  0.5;
          if (i_part< -0.5) i_part = -0.5;

          raggiorSterzo += i_part;

          // errore +/- 0.5

          if (raggiorSterzo < -2.0) raggiorSterzo = -2.0;   // ID_005
          if (raggiorSterzo >  2.0) raggiorSterzo =  2.0;   // ID_005
        }


        /** gestione raggiungimento angolo target
          in questo caso il robot deve ruotare per orientarsi con l'angolo dato.
          Questo vale per i modi 5 e 6.

			viene generato una rampa sull'angolo sino al target
			un controllo PI genera la velocità del motore
			
        */
        if ((statoRun == 5)||(statoRun == 6)){
		
			switch (SM_R5){
				case 0:
					posTarget = tetaRef;
					posRef    = tetaMisura;		// init rampa posizione
					
					step 		= 3.14/(1.5/0.03);
					if (posTarget < posRef)	step = -step;
					counterArresto = 0;
					SM_R5   = 1;
					break;
		
				case 1:
			
					posRef 	+= step;
					
					if (abs(posRef - posTarget) < 2*(3.14/(1.5/0.03))){
						posRef = posTarget;
						counterArresto++;
						// giunto al target lascio un secondo per stabilizzare posizione
						// trascorso il tempo fermo il movimento
						if (counterArresto > 30){
							SM_R5     = 0;
							statoRun    = 0;  // arresto senza rampa
							motorSpeed  = 0;  // annullo rampa
							motorSpeedRef = 0;
							break;
						}
					}

					// regolatore PI

					errore = posRef - tetaMisura;
					raggiorSterzo =   kpTeta*errore;
					i_part += raggiorSterzo*kiTeta;

					// anti windup
					// limito la parte integrale se la parte proporzionale è già alta
					// questo evita di accumulare errore da scaricare
					// se la somma di parte P e I supera il massimo, la parte integrale viene
					// limitata a MAX - parte P
					if  ((raggiorSterzo + i_part) >  MAX_STERZO){
						i_part = MAX_STERZO - raggiorSterzo;
						if (i_part < 0) i_part = 0;
					}
					if  ((raggiorSterzo + i_part) < -MAX_STERZO){
						i_part = -MAX_STERZO - raggiorSterzo; // -2 - (-1) = -1, -2 -(-3) = 1
						if (i_part > 0) i_part = 0;
					}
					if (i_part>  0.5) i_part =  0.5;
					if (i_part< -0.5) i_part = -0.5;

					raggiorSterzo += i_part;

					// errore +/- 0.5

					if (raggiorSterzo < -2.0) raggiorSterzo = -2.0;   // ID_005
					if (raggiorSterzo >  2.0) raggiorSterzo =  2.0;   // ID_005
					
	                motorSpeed =  abs(raggiorSterzo)*110.0; //MODERATA;
					if (raggiorSterzo > 0) 	direzione = AVANTI;
					else					direzione = INDIETRO;

					break;
			}
/*
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

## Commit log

2018-10-26 sistemazione1
    aggiornata struttura cartelle
    aggiunto sw pc
    aggiunto fw faroIR
    aggiunta documentazione
    [UMBmarkTest_ari03.xlsx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]
2018-10-29 aripy
    aggiornato a mia versione
    [pos.csv]
2018-10-30 aggiornato gitingore
    aggiornato .gitignore con
    arianna_gui.cpython-36.pyc
    cmd.txt
    pos.csv
    unicoma.txt
    [pos.csv]
2018-11-07 problema radar
    risolto problema radar dovuto a ritardo nella registrazione newpos
    [pos.csv]
2018-11-07 Update 02_fwArianna/ariPi_2DC_esp_08/ariPi_2DC_esp_08.ino
    corretta gestione lidar
    inseriti modi guida R1 R3 con lidar
2018-11-21 11Nov18 stato "ostacolo" 90. In questo stato accetta solo comandi R6. gestione sensore ostacolo frontale comando B per abilitarlo B0 off, B1 On nota che il Lidar si sente sull'IR. Se tolgo lidar dall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
    01Nov18 rivisto lidar. Introdotta guida a dsitanza dalla parete. Modo R1 e R2. Parametro 'O' distRef.
    nellla stringa "pos:..." aggiunto in coda "statoRun". Questo permette di coordinare il sw su pc.
    introdotti parametri per guadagni regolatori vari
    [ariPi_2DC_esp_08.ino]
2018-11-25 25nov18 definiti LED1..3 attivato led1 insieme a LedPuntatore
2018-12-01 01dic18 3.04.00 FW ariPi_2DC_esp_08 sensore ostacolo anteriore off alla partenza. va abilitato per usarlo aggiunta V_FW_ATMEGA formato M.mm.sb M: il cambio richiede modifiche hw. Aggiungere un sensor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
    richiesta "h" versione V_FW_ATMEGA
    printDatiCalibrazione dava errore per risposta troppo lunga
    added dir 04_disegni3D
    [ARIV3_coperchioTre.stl, ARIV3_scatolaBase.stl, poratLidarServoPiccolo v4.stl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]
2018-12-02 aggiornamento readme.md. Tolto invio continuo misura lidar su seriale
2018-12-05 aggiunti pcb
2018-12-05 png con cmmenti di costruzione
2018-12-07 documentazione di installazione Arduino, librerie, git e clazione del repository
2018-12-09 aggiunta gestione lidar 1a generazione
2018-12-11 aggiunta id risposta a pos
    mi serve per sincronizzare il programma con arduino
2018-12-11 versione 2.0 software
    movimento per target
    [pos.csv]
2018-12-16 /*@serverTcp_IR_Receiver_o1.ino * stuffcube.wordpress.com
    16dic18 1.00.01
    aggiunta versione
    si legge con >v
    /**@file ariPi_2DC_esp_08.ino */
    /* stuffcube.wordpress.com
    09dic18 3.04.01
    gestione lidar con ritorno in mm divido il valore per 10
    aggiunto divisore divLidar come parametro in E2prom per vecchi lidar
    modificati valori di default per meccanica corrente
    corretto errore in load default
    caricando questa versione la prima volta vanno ripristinati i valori meccanici
    [ariPi_2DC_esp_08.ino, serverTcp_IR_Receiver_01.ino]
2018-12-23 aggiornameno caricamenti e gestione target
    gestione percorsi migliorata , in config scelta se caricare i parametri
    [pos.csv]
2018-12-24 cancellati arianna socket intermedi e caricata nuova release
    la 2.2 usa il ritorno del vl53 come sensore di distanza , va allineato con firmware. da verificare
    [pos.csv]
2018-12-27 aggiunto parametro lidar
2018-12-27 aggiunto comando divisore lidar
    aggiunto comando divisore lidar
2018-12-28 aggiunti supporti motore per encoder 3d printer
    aggiunti supporti motore per encoder 3d printer
    [motorMount_v2.scad, motorMount_v2.stl]
2018-12-28 minime correzioni di testo
2018-12-29 FW ATmega introduzione sensore anteriore VL53L0X rimozione di quello digitale rimosso ritorno a tempo della distanza Lidar 'mis'
    FW Wemos
    rimossa chiamata a tempo della posizione comando '>p'
    [pos.csv]
2018-12-30 leggi il wiki
2019-01-03 errato separatore nella stringa di risposta 'p'
2019-01-10 disegni contenitore e FW con aggiunte funzioni ocilloscopio
    [ARIV3_coperchioTre.stl, ARIV3_scatolaBase.stl, ARI_V3_baseSupporto.stl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]
2019-01-18 aggiunto in config test per caricare configurazioni iniziali
    se esiste il file okini,txt carica i parametri iniziali altrimenti usa quelli in eeprom....temporaneo per sviluppo
2019-01-20 aggiornati disegni 3D alcuni passati in .md e cancellati alcuni docx FW: ATMega ora lo scope inizia a registrare qundo R di venta diverso da zero FW: Esp, introdotto nome robot per peterne gestire pi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
    [ARI_V3_baseSupportoGrigliaFori.dxf, ARI_V3_coperchio.stl, ARI_V3_omniDue.stl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]
2019-01-21 aggiunto file di configurazione
    gestione pagine web di configurazione arianna tramite file ini, ogni arianna puo avere configurazioni diverse in base al nome di arianna stessa che deve coincidere con quello impostato su esp
2019-01-23 pdate documentazione, correzione Issue #9 in ariPi....
    [ariPi_2DC_esp_09.ino]
